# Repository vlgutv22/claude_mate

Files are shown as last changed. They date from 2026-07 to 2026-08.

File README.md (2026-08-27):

# Claude Mate










> **Not affiliated with Anthropic.** Claude and Claude Code are trademarks of
> Anthropic, PBC. This is an independent, non-commercial project — see
> [TRADEMARKS.md](TRADEMARKS.md).

<p align="center">
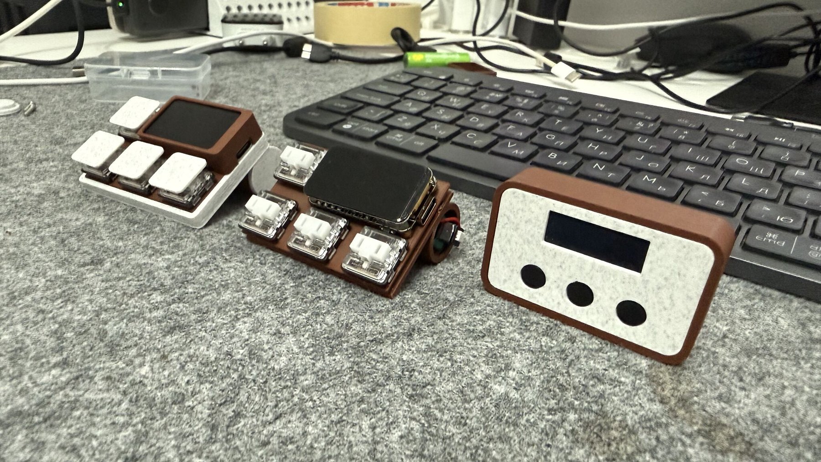
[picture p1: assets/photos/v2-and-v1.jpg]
Both Claude Mate builds on a desk — the cordless ESP32-S3 keypad with its colour screen, the same keypad opened up around its cell, and the original Arduino Nano box with its OLED
  
</p>

<p align="center"><sub><b>Two devices, one protocol.</b> Left and centre: iteration 2, the
cordless ESP32-S3 keypad (assembled, and opened around its cell). Right: iteration 1, the
USB Arduino Nano box.</sub></p>

**Claude Mate exists to cut the cognitive overload of orchestrating many
AI-agent sessions at once** — a wall of Claude Code tabs spread across different
accounts and projects, each finishing, blocking, or erroring on its own
schedule. Instead of scanning every terminal to find the one that stalled, you
glance at a small desk device: one screen and an indication LED tell you *which*
session needs you *right now*, and a single button jumps you straight to it.

**There are two devices, speaking one protocol, byte for byte.** The original
**Arduino Nano** over USB, and a cordless **ESP32-S3** with a 172×320 colour
screen that reaches the daemon over Wi-Fi, runs on a 14500 cell, and can open a
**live mirror of a session's actual terminal**. The daemon cannot tell them
apart: either works on its own, or **both at once** (see
[Bill of Materials](#bill-of-materials), [Roadmap](#roadmap) and
[`firmware/README.md`](firmware/README.md)).

You feed it from the Claude Code **hooks** or the **PTY wrapper**
(`claude-mate-wrap`); it becomes an ambient, always-on triage pane for every
session you have open — in VS Code, the terminal CLI, iTerm2, tmux, anywhere.

**Iteration 2 — ESP32-S3, 172×320 colour IPS, cordless:**

```
        ┌──────────────────────────────────────┐
        │ ▁▄█ CLAUDE MATE              ▮▮▮     │  ← status bar: Wi-Fi link · battery (3 segments)
        ├──────────────────────────────────────┤
        │ api-server                           │  ← r0: session name, in the state's colour
        │ WAIT   0:42                   work   │  ← r1: state · time-in-state · account
        │ Opus 5 xhigh                 5h82%   │  ← r2: model · effort · remaining limit
        │ 2/6  E  B  W  D  I                   │  ← r3: queue position · fleet strip, letter-coloured
        │ wifi 192.168.1.42                    │  ← link detail (firmware-local, never from the daemon)
        │══════════════════════════════════════│  ← accent bar in the selected session's state colour
        └──────────────────────────────────────┘
                  (•) WS2812 — rhythm AND colour
        [ PREV ]  [ GO ]  [ NEXT ]  [ MENU ]       ← a fourth button, with three gestures
   MENU: tap = the selected session's real terminal · double-tap = the on-device menu
         hold 2 s = long sleep (a tap wakes the board)
```

**Iteration 1 — Arduino Nano, 128×32 mono OLED, USB:**

```
        ┌───────────────────────┐
        │ api-server            │   ← r0: session name (flashes while its alert
        │ WAIT  0:42       work │   ← r1: state · time-in-state · account   is unacknowledged)
        │ Opus 5 xhigh    5h82% │   ← r2: model · effort · remaining limit
        │ 2/6 E B W D I         │   ← r3: queue position · whole-fleet letter strip
        └───────────────────────┘       (the active tab's letter sits in a wide centred filled rectangle)
              (•) indication LED               ← blinks per alert class, until you ack
          [ PREV ]   [ GO ]   [ NEXT ]         ← three buttons — same meaning, always
   PREV/NEXT: step the triage queue (hold = auto-repeat)   GO: short = ack + raise · double = FOLLOW · long = ack only

   the flash: name row inverting = unacknowledged (needs you) · steady = seen
   the strip: E error · B waiting · W working · D done · I idle — one letter per session, stable order
              a letter BLINKS while that tab's alert is unacknowledged; it goes steady once you ack it
   the box:   the active tab's letter is a wide centred filled rectangle (letter knocked out) — shows which tab is on screen
   the right edges: which ACCOUNT the session runs as (its wrapper profile) · how much of that account's plan
              limit is LEFT (5h82% = 82% of the 5-hour window · wk31% = 31% of the week — the tighter one shows)
   FOLLOW:    double-click GO → a ► marker appears; PREV/NEXT then also raise the selected terminal (raise only)
   the LED:   START 1 s blink · INPUT even blink · DONE 4-blink cascade · ERROR fast strobe  (loops until you GO/ack)
```

---

## Contents

- **[Install & use](#install--use)** — one command, then every CLI command
- **[The manual, 0 → hero](docs/USING.md)** — daemon, CLI and device in one page
- [What it is](#what-it-is)
- [The terminal mirror (ESP32-S3)](#the-terminal-mirror-esp32-s3)
- [Two ways to feed it](#two-ways-to-feed-it)
- [Features](#features)
- [Architecture](#architecture)
- [LED alerts & the acknowledge model](#led-alerts--the-acknowledge-model)
- [Bill of Materials](#bill-of-materials) · [Enclosures & 3D models](#enclosures--3d-models)
- [Quick start](#quick-start) · [Configuration](#configuration)
- [How the status maps to your sessions](#how-the-status-maps-to-your-sessions)
- [Roadmap](#roadmap)
- [Repository layout](#repository-layout)
- [Limitations](#limitations)
- [Changelog](#changelog)
- [License](#license)

---

## Install & use

**Install — one command.**

```sh
git clone https://github.com/vlgutv22/claude_mate.git && cd claude_mate
./install/install.sh --yes
```

It installs the Claude Code status hook, merges the hooks block into
`~/.claude/settings.json` (backing it up first), installs and **starts the
LaunchAgent** so the daemon runs at login, installs `pyserial` + `bleak`, and
puts the three commands below on your `PATH`. Idempotent — re-run it after a
`git pull`. Drop `--yes` and it asks before editing `settings.json`, its only
question.

**Then point `claude` at the wrapper** — this is what puts model, effort, account
and remaining limit on the screen:

```sh
echo 'alias claude="'"$PWD"'/bin/claude-mate-wrap"' >> ~/.zshrc && exec zsh
```

**No hardware needed.** `claude-mate` in a terminal is the same interface as the
device — and run bare, it is an app rather than a printout:

```sh
claude-mate
```
```
 claude-mate   ● daemon running · 14:22:31

 SESSIONS
  ▸• api-server   working    1:23   Opus 5  xhigh  work
    web-ui        waiting    0:05   Opus 5         needs you
    docs          idle      12:40

  ▸  Start new session
     Start new session · skip permissions
     Device · link status and pairing
     Accounts · switch or review
     Quit

 ↑↓ move   ⏎ raise this session   a ack   f follow   m mirror   c continue
 r restart daemon   q quit
```

Arrow keys move, Enter chooses, `q` quits. **Start new session** runs `claude`
through the wrapper in this terminal, which is the part you would otherwise
have typed — and going through the wrapper is what makes the new session show
up on the device at all.

Piped, hooked, cron'd or tested, `claude-mate` is still the plain one-shot queue
print it always was; the app appears only when both ends are a terminal.

### Every command

Full reference, including the other three binaries and every environment
variable: **[docs/CLI.md](docs/CLI.md)**.

| Command | Device button | What it does |
|---|---|---|
| `claude-mate` | — | the app on a terminal, else print the queue and exit |
| `claude-mate status` | — | the queue, printed once |
| `claude-mate watch` | — | reprint it every second until Ctrl-C |
| `claude-mate next` / `prev` | NEXT / PREV | step the selection (or scroll the mirror) |
| `claude-mate go` | GO | acknowledge **and raise that session's terminal** |
| `claude-mate ack` | GO, held | acknowledge only — leave your windows alone |
| `claude-mate follow` | ACK, held | toggle FOLLOW: `next`/`prev` then also raise |
| `claude-mate mirror` | 4th, tapped | toggle the live terminal mirror on the device |
| `claude-mate continue` | — | type `continue` into that session |
| `claude-mate new-terminal` | — | open a terminal in that session's directory |
| `claude-mate select <n\|name>` | *(none)* | point at a row instead of stepping to it |
| `claude-mate accounts` | — | the saved logins |
| `claude-mate accounts rm <n\|name>` | — | delete one, after typing its name back |
| `claude-mate daemon` | — | start the daemon, or restart it, through launchd |
| `claude-mate --version` | — | which build this is |

Three more commands beside it:

| | |
|---|---|
| `claude-mate-wrap` | the thing that actually runs `claude` and reports it. Reached through the shell alias above, never by name |
| `claude-mate-connect` | every link with a verdict, and the shortest fix for whichever is down. `--pair` enrols a cordless device over BLE |
| `claude-mate-switch` | carry this terminal's conversation to another account, with remaining limits |

**It presses the same buttons.** `claude-mate go` sends `press|G`, which the
daemon hands to the *same* handler that receives `B|G` from the device — so GO
means one thing here, and there is no second implementation to drift.

📖 **[docs/USING.md](docs/USING.md) is the full manual**, 0 → hero: the daemon,
every command above in detail, every button and screen on the device, how to
connect one, and a symptom → cause table for when something is wrong.

---

## What it is

**Claude Mate** is a small desk companion paired with a lightweight Python
daemon on your Mac. Build it either way — or both, at the same time:

| | **Iteration 1** — `claude_mate/` | **Iteration 2** — `claude_mate_s3/` |
|---|---|---|
| Board | Arduino Nano (ATmega328P) | Waveshare ESP32-S3-LCD-1.47**B** |
| Display | 0.91" 128×32 mono OLED (SSD1306) | 1.47" 172×320 colour IPS (ST7789) |
| Transport | USB serial | **BLE** or **Wi-Fi (TCP)**, USB as fallback |
| Buttons | 3 — PREV / GO / NEXT | 4 — + **MENU** (Kailh Choc low-profile) |
| Alert light | one LED, rhythm only | WS2812, rhythm **+ colour** |
| Power | USB | USB **or** a 14500 cell, with a gauge |
| Extra | — | a **live mirror** of a session's terminal |

The daemon keeps ONE **stable, alphabetically-ordered** **triage queue** of every
Claude Code session (tabs never shuffle as their states change) and renders ONE
screen: the *selected* session, over a whole-fleet letter strip. Urgency is
tracked **separately** — it drives the LED and the blinking fleet letters,
never the tab order or which tab is shown. The LED blinks a status-distinct pattern for the worst
*unacknowledged* alert — so a single tab finishing, blocking, or erroring is
*seen* even while the rest of your fleet keeps working. It keeps blinking until
you deal with it. There are **no UI modes**: the buttons — **PREV · GO · NEXT**,
and **MENU** on the S3 — mean the same thing at all times.

The single must-have action is **GO**: press it and the window for the
displayed session is raised so you can deal with it — the integrated VS Code
panel *or* the actual terminal that session is running in (matched by TTY).
Raise **only**: nothing in the system ever collapses or resizes a window.
Retrying or resubmitting a turn is intentionally **out of scope** (see
[Limitations](#limitations)).

The extra pixels on the S3 buy **typography, colour and the terminal mirror** —
never a different information model. The daemon pre-renders the same four rows
of at most 21 characters for both devices; each just draws what it was sent.

---

## The terminal mirror (ESP32-S3)

Tapping the **4th button** opens a live view of the selected session's *actual
terminal* on the device — 52×17 characters, refreshed about once a second.
**PREV/NEXT** then scroll it instead of moving the selection, and **GO** closes
it and raises the real window. Only **wrapped** sessions can be mirrored: a
hook-only session has no PTY for the daemon to read, and the device says so.

It adds no new channel. The PTY wrapper already mirrored the full TUI into
[pyte](https://github.com/selectel/pyte) (it was only being mined for state and
the model/effort strings), and the daemon already held a per-session control
socket to every wrapper for `focus`. The mirror is one more request/response on
that socket — so polling runs **only while the view is open**, and an unwatched
fleet costs nothing.

> ⚠️ **The mirror puts raw terminal output on the network.** The handshake is
> authenticated, but the session itself is **plaintext TCP** — and terminal
> contents can include keys, tokens and file contents, which is a materially
> larger exposure than shipping `WAIT` and a model name. Keep it to networks you
> trust. `--tcp` is opt-in and fails closed without a token.

---

## Two ways to feed it

You can drive the daemon from **either or both** of these — mix freely:

| Path | What it is | What it can see |
|---|---|---|
| **(a) Claude Code hooks** | `hooks/claude-status.sh`, wired to `UserPromptSubmit` / `Notification` / `Stop` / `StopFailure`. Fire-and-forget; never blocks or fails a turn. | Turn boundaries: started, needs-input, finished OK, finished on error — plus the **background work Claude reports on `Stop`** (`background_tasks` entries whose own `status` is still in flight, plus one-shot `session_crons`), so a turn that ends with work still running reports `working`, not a premature DONE — while a task listed as already finished is not counted, because the next `Stop` that would correct it may never come. Works in the VS Code extension and the CLI. |
| **(b) PTY wrapper** `bin/claude-mate-wrap` | Run `claude` *through* a wrapper (`alias claude=claude-mate-wrap`). It forks a pseudo-terminal, relays stdin/stdout transparently, and mirrors the TUI into a headless terminal emulator to read the **live screen**. | Everything on screen the hooks can't report: the spinner, **API errors/retries**, **permission prompts**, interactive option-pickers, and every **background-work** tell — the *"Waiting for N dynamic workflow to finish"* banner, the turn recap's *"· 1 shell still running"* suffix and the **live in-flight chip** in the hint row — i.e. it knows a session is **still busy after the turn "ends"**, including work that is only queued, and knows when it has stopped being busy. |

The wrapper is the more capable feed (true live state, plus terminal focus); the
hooks are the zero-dependency feed. Use whichever fits each session.

---

## Features

- **One stable, alphabetically-ordered triage queue** — every session in a
  fixed order (alphabetical by name, tiebroken by session key) so tabs **never
  shuffle under you** as their states change. **Urgency** is computed
  **separately** (worst unacknowledged alert: error → waiting → done, oldest
  first) and drives only the LED and the blinking fleet letters — never the
  tab order. **PREV** / **NEXT** step the order manually (hold to auto-repeat,
  wrapping at the ends); the screen **never changes subject on its own**.
- **No UI modes** — the buttons mean the same thing at all times:
  **PREV · GO · NEXT** (plus **MENU** on the S3). A short **GO** acknowledges
  the shown alert **and raises its window**; a **long-press of GO** (~0.5 s)
  acknowledges it **without** touching any window. Buttons fire instantly
  (edge-accepted ~40 ms debounce), and every accepted press flashes the device
  for ~80 ms — the Nano inverts the whole panel, the S3 turns its accent bar
  white — instant "the device heard you" feedback, well before the daemon
  round-trips a new frame.
- **No auto-switch, ever** — the selection is **sticky**: only PREV/NEXT/GO
  move it, and a GO/ACK stays on the tab it acted on. An alert on another tab
  announces itself through the LED and its **blinking fleet letter**; the view
  stays exactly where you left it until you navigate.
- **Navigation never touches windows** — the ONLY window operation in the
  whole system is GO, and it only **raises/activates**; the daemon never
  collapses, resizes, or miniaturizes anything.
- **GO is WYSIWYG** — GO/ACK act on exactly the session whose name is on the
  glass, never a freshly recomputed most-urgent alert. So a press can only ever
  raise the terminal you are actually looking at.
- **Status-distinct LED alerts** — the indication LED blinks the pattern of the
  *worst unacknowledged* alert across the whole fleet:
  - **START** — a job (re)started → one long 1 s blink (one-shot).
  - **INPUT** — a session is waiting on you → an aggressive even blink
    (~2.8 Hz), **looping** until you ack it.
  - **DONE** — a turn finished → a cascade of 4 quick blinks, then a pause,
    **looping** until you ack it.
  - **ERROR** — a turn ended on an API error → a super-aggressive ~7 Hz
    strobe, **looping** until you ack it.

  The loops run in the firmware until the daemon sends `V|OFF` (a GO/ACK, or
  the state changes on its own). If the daemon dies mid-alert the firmware
  stops the loop on its own after ~30 s of silence — and shows **LINK LOST**.
- **"Finished but not seen" model** — when a turn ends, the session becomes
  **done** and *stays* done (name flashing, LED looping) until you acknowledge
  it; later idle keepalives don't silently clear it. GO (or a long-press ACK)
  acknowledges it.
- **Flashing name row** — while the shown session's alert is unacknowledged,
  the top name row inverts at ~2.5 Hz; once acknowledged it goes steady. At
  a glance you know whether you've seen it.
- **Whole-fleet strip** — the bottom row shows your queue position
  (`pos/total`) plus one status letter per session in stable (alphabetical)
  order, **space-separated**: `E` error · `B` waiting · `W` working · `D` done ·
  `I` idle. A letter **blinks** while that tab's alert is unacknowledged.
- **Live time-in-state** — the state row counts up how long the session has
  been in its current state: for a `working` tab that IS the live turn
  runtime; for an alert it is how long it has been waiting on *you*.
- **One-button FOCUS** — GO raises the session's window: first the **PTY
  wrapper's own terminal** (iTerm2 / Terminal.app / VS Code / Ghostty / Warp /
  tmux, matched by TTY), else a **VS Code deep link**, else the VS Code window
  for the workspace folder. Raise only, always.
- **Honest link state** — with no daemon frame yet the firmware shows a boot
  splash; after ~30 s of daemon silence it replaces the stale frame with a
  **LINK LOST** screen (`NO LINK / waiting for daemon`) instead of freezing,
  and recovers on the next parsed line.
- **Hot-reloadable detection** — the wrapper's state patterns live in
  [`patterns.json`](patterns.json) and reload live (~0.25 s, no restart), so you
  can tune what counts as error/waiting/busy without touching code.
- **Robust by design** — the daemon keeps the serial port open continuously,
  auto-detects and auto-reconnects to the device, never crashes on a missing
  port; the hooks never block a turn; the wrapper falls back to running `claude`
  directly if anything is wrong.
- **`--mock` demo mode** — run the whole display with fake sessions cycling
  through every state, no Claude and no hardware required.

**On the ESP32-S3, additionally:**

- **Cordless, on a cell** — Wi-Fi (TCP) instead of USB, discovered over mDNS
  and authenticated with a nonce/HMAC handshake in which the token never
  crosses the wire. Wi-Fi credentials, daemon address and token live in **NVS**,
  a separate partition, so they **survive a reflash**. An unprovisioned board
  comes up on BLE and asks for a token over the cable; hold **BOOT** at power-on
  for a Wi-Fi setup portal you join from a phone.
- **Colour as a second channel** — the WS2812 plays the same rhythm *and* the
  alert class's colour, and every fleet letter is drawn in its own state colour.
  The colours differ in **brightness** as well as hue, so they stay distinct for
  a red/green-colourblind reader and in direct sunlight.
- **A battery indicator that doesn't lie** — **three segments** (3 green, 2
  amber, 1 red), not a percentage. Unplug a full cell and the voltage relaxes
  from 4200 to ~3950 mV in minutes, so a percentage read 100 % then 79 % with
  nothing wrong: 4200 mV is the *charger's* regulation point, surface charge is
  not consumption, and at ~9 mV per percent the ADC noise is worth whole points.
  Median-of-15 samples, an EMA, 60 mV of hysteresis and a 45-second hold sit
  behind it. The exact number stays in the About page, where diagnosis wants it.
  Charging is inferred in tiers; the board exposes no charge-status line.
- **A live terminal mirror** — see [above](#the-terminal-mirror-esp32-s3).
- **An on-device menu** — double-tap the 4th button. Four items: the triage view,
  SETTINGS, SHIP IT and long sleep. Settings holds the rest — a **BLE gamepad**
  switch, screen sleep, brightness, alert-LED level including a genuine *off*,
  Mac sound, flip, an About readout, and factory reset. **Nothing to do with
  Wi-Fi is on it at all** — not the radio switch, not the setup portal. Pairing
  a cordless board is `claude-mate-connect --pair` plus one press of GO, so the
  portal stopped being the only way in and stopped earning a row. **On the radio
  switch specifically:** one
  press used to be enough to move a cordless board onto Wi-Fi, and a board with
  no credentials then reboots into a portal that outranks the menu — hiding the
  row you would use to undo it. `claude-mate link <wifi|p2p|ble>` over USB still
  does it, which puts that switch behind a cable you have to actually have. About lives here
  rather than on the top strip because it is not a place you go: it is something
  you read. Entirely
  **firmware-local**: while it is up PREV/GO/NEXT are handled on
  the device and never emitted, so the queue cannot move while you are aiming at
  a settings row — and there is **no protocol change and no daemon change** for
  any of it.
- **A screen that turns itself off** — after 1–30 minutes, and only when nothing
  is waiting on you. What counts as waiting comes from the frame the device
  already has: a flashing name row, any lowercase fleet letter, or a *looping*
  LED — which the daemon drives from exactly "worst unacknowledged alert", so it
  is the authoritative signal. An alert turns the screen back on by itself. A
  `working` fleet does **not** hold it on — an hour of grinding with nothing to
  say is the case this exists for — and neither does `NO LINK`, because a dead
  daemon must not be able to burn the cell flat. A press on a dark screen only
  wakes, and is swallowed: GO raises a window, and obeying a press aimed at a
  screen you cannot read would sometimes yank you to the wrong session.
- **Long sleep** — hold the **4th button** for 2 s for deep sleep, tap to wake.
  Roughly a month of standby on a 14500; the WS2812 has no shutdown pin, so a
  switch in the battery lead is the only true zero.

---

## Architecture

```
   Claude Code session
   ├─ (a) hooks ─ ~/.claude/hooks/claude-status.sh
   │                 "<state>|<sid>|<name>\n"
   │
   └─ (b) PTY wrapper ─ bin/claude-mate-wrap  (alias claude=claude-mate-wrap)
                     "<state>|<sid>|<name>|<ctrl_sock>|<model>|<effort>\n"   + screen-scrapes the live TUI
                            │
                            ▼
              Unix domain socket  /tmp/claude-mate.sock
                            │
                            ▼
   ┌──────────────────────────────────────────────┐
   │   Python daemon (Mac)                        │
   │   • ONE triage queue + "done-until-acked"    │   (STABLE alphabetical order —
   │   • ONE pre-rendered screen                  │    tabs never shuffle; urgency separate)
   │       F|<flags>|<sel>|<r0>|<r1>|<r2>|<r3>          │
   │   • LED policy  V|<START/INPUT/DONE/ERR/OFF> │   worst unacked class, loops until ack
   │   • GO: raise the session's window — RAISE   │
   │     ONLY (wrapper ctrl-sock → VS Code link)  │
   │   • MIRROR: pull the session's live screen   │
   │     from its wrapper → M| lines (S3 only)    │
   └──────────────────────────────────────────────┘
             │                              │
   USB serial 115200 8N1        TCP :8787 (--tcp) or BLE GATT (--ble):
   "|"-delimited ASCII          mDNS-discovered / duty-cycled advertising,
             │                  the SAME nonce/HMAC handshake and the SAME
             │                  "|" lines — the token never crosses the wire
             ▼                              ▼
   ┌────────────────────────────┐  ┌──────────────────────────────────┐
   │  Arduino Nano (ATmega328P) │  │  ESP32-S3 (Waveshare -LCD-1.47B) │
   │  • SSD1306 128x32 OLED —   │  │  • ST7789 172x320 colour IPS —   │
   │    draws the one frame it  │  │    same four rows, + status bar  │
   │    was last sent (dumb)    │  │    and the M| terminal mirror    │
   │  • LED (D8) plays V|<KIND> │  │  • WS2812 plays V|<KIND> in the  │
   │  • PREV/GO/NEXT buttons    │  │    alert class's colour          │
   │    → B|P B|N B|G B|K       │  │  • + MENU button → B|M           │
   └────────────────────────────┘  │  • battery gauge, Wi-Fi config   │
             │                     │    in NVS, deep-sleep power-off  │
             │                     │  • its OWN menu + screen sleep,  │
             │                     │    which the daemon never sees   │
             │                     └──────────────────────────────────┘
             │  H (hello on boot), B|<x> (buttons)        │
             └───────────────► back to the daemon ◄───────┘
                    (both may be connected at the same time)
```

Two control flows worth calling out:

- **FOCUS round-trip.** Each wrapped session opens a per-session control socket
  (`/tmp/claude-mate-ctrl-<id>.sock`) and tells the daemon about it. On a GO
  press the daemon connects to that socket and sends the single verb `focus`;
  the wrapper raises *its own* terminal window using the right method for
  `$TERM_PROGRAM` (iTerm2 and Terminal.app match the exact tab by TTY), replying
  `go` on receipt and `ok` when the window op completed — so consecutive GO
  presses raise windows in press order. Hook-only sessions fall back to a
  VS Code deep link / window raise.
- **Reset recovery.** Opening the USB serial port resets the Nano (~1.5 s). On
  boot the Arduino emits `H`; the daemon responds by re-sending the full current
  state (the current frame + re-arming the LED loop), so the display recovers
  cleanly after any reconnect. A wireless device gets the same treatment when it
  (re)connects.
- **The wireless handshake.** The device dials the daemon, not the other way
  round — so it works from any address the Mac never has to know. It finds the
  listener via the `_claudemate._tcp` mDNS advertisement, then proves it knows
  the shared token against a server-issued nonce: the **token itself never
  crosses the wire**. `--tcp` is off unless asked for, and refuses to start
  without a token rather than serving an unauthenticated listener.

> The **triage queue** is a **stable, alphabetically-ordered** list of sessions —
> tabs never reorder as their states change. **Urgency** (worst unacknowledged
> **error > waiting > done**, oldest first) is tracked **separately** and drives
> only the LED and the blinking fleet letters, never the tab order or the shown
> tab (the selection is sticky). The top row is the selected session's **name**;
> its state (`ERR`/`WAIT`/`DONE`/`WORK`/`IDLE`) leads the second row.

---

## LED alerts & the acknowledge model

The LED is driven **entirely by the daemon** via `V|<KIND>` lines — the
firmware just plays the pattern (on D8 on the Nano, on the WS2812 on the S3);
the screen never blinks the LED on its own. The pattern is always the class of
the **worst unacknowledged alert** across all sessions (`ERROR` > `INPUT` >
`DONE`), so the LED loops exactly while something needs you:

| Event | `V|` kind | LED pattern | S3 colour | Repeat until acked |
|---|---|---|---|---|
| Job (re)started (nothing else pending) | `START` | one long 1 s blink, then dark | white | — (one-shot) |
| Waiting on you | `INPUT` | aggressive even blink (~2.8 Hz) | amber | **loops** continuously |
| Turn finished | `DONE` | cascade — 4 quick blinks, then a pause | green | **loops** continuously |
| Error / retry | `ERROR` | super-aggressive fast strobe (~7 Hz) | red | **loops** continuously |

The **rhythm is the primary channel** and is identical on both devices — colour
is redundant reinforcement on the S3, never the only thing carrying the message.

The loops run in the firmware until the daemon sends `V|OFF`. A turn ending
becomes **done** and keeps looping until you acknowledge the session — raising
it (**GO** short-press) or silencing it in place (**GO** long-press, no window
op) acknowledges it: a done tab becomes idle; a waiting/error tab goes quiet
but keeps its state until it changes. An alert can also die by
**auto-resolving** (the session leaves the alert class on its own — you
answered in the terminal) or by **TTL pruning**; nothing else removes one. A
session re-entering the same alert class within ~5 s of being acknowledged
stays acknowledged, so a bouncing detector can't re-fire the LED you just
silenced. The flashing name row mirrors the ack state: inverting while
unacknowledged, steady once seen. If the daemon ever dies mid-alert, the
firmware stops the loop on its own after ~30 s of serial silence and shows the
**LINK LOST** screen.

---

## Bill of Materials

### Iteration 2 — ESP32-S3, cordless

| Qty | Part | Notes |
|-----|---|---|
| 1 | **Waveshare ESP32-S3-LCD-1.47B** dev board | 1.47" 172×320 IPS (ST7789), dual-core ESP32-S3, 8 MB PSRAM, 16 MB flash, USB-C. Carries the WS2812, the Li-ion charger and the battery sense divider — so there is nothing else to solder on the board side |
| 4 | **Kailh Choc low-profile (1350) switches** | PREV · GO · NEXT · **MENU**. Tactile ("Chocolate"/brown) or linear, whichever you prefer — the firmware debounces in software either way |
| 4 | Choc keycaps (1350 footprint) | Any low-profile cap that fits Choc stems |
| 1 | **14500 Li-ion cell, ~800 mAh** | AA-sized 3.7 V. Plugs straight into the board's battery header — **do not** wire anything to GPIO 1 yourself, the sense divider is already there |
| 2 | M2 screws | Close the printed enclosure |
| — | Thin hook-up wire | Four switches to GPIO 3–6, one shared GND — no resistors, no debounce caps |
| 1 | USB-C cable | Flashing and charging |

> ⚠️ **The cell must be 3.7 V Li-ion.** The board's onboard charger is a 4.2 V
> Li-ion charger and the firmware's gauge curve and charge detection are
> calibrated for that chemistry (`CHARGE_FULL_MV 4150`, `BATT_LOW_MV 3300` in
> [`board_s3.h`](firmware/claude_mate_s3/board_s3.h)). A 3.2 V LiFePO4 cell would
> be over-charged by it *and* read as flat.

Pinout summary (full details in [`firmware/README.md`](firmware/README.md)):

| Signal | GPIO | Notes |
|---|---|---|
| PREV button | 3 | `INPUT_PULLUP`, emits `B|P`. A strapping pin, but an inert one — `STRAP_JTAG_SEL` is unburned by default |
| GO button | 4 | `INPUT_PULLUP`, emits `B|G` / `B|K` — same meanings as on the Nano |
| NEXT button | 5 | `INPUT_PULLUP`, emits `B|N` |
| **MENU** button | 6 | `INPUT_PULLUP`. Tap emits `B|M` (the mirror); **double-tap opens the on-device menu**; **hold 2 s = long sleep**, a tap wakes. Only the tap emits anything — the menu and the hold are firmware-local |
| Backlight | 46 | **On-board.** GPIO 46 on the ‑1.47**B**, 48 on the original ‑1.47 — the only pin that differs between revisions, and the wrong one leaves the panel dark while the ST7789 is driven perfectly |
| WS2812 alert LED | 38 | On-board. Plays `V|<kind>` in the alert class's colour |
| Battery sense | 1 | On-board 3:1 divider. Nothing to wire |

### Iteration 1 — Arduino Nano, USB

| Qty | Part | Notes |
|-----|---|---|
| 1 | Arduino Nano (ATmega328P) | Any USB-serial Nano clone works |
| 1 | SSD1306 0.91" 128×32 OLED, I2C | Address `0x3C` (some boards `0x3D`); 0.96" 128×64 also works |
| 3 | Momentary push buttons | PREV, GO, NEXT |
| 1 | LED + ~220 Ω–1 kΩ resistor | indication LED on D8 (the sole alert output) |
| — | Jumper wires, breadboard / perfboard | |
| 1 | USB cable (to the Mac) | Data-capable, not charge-only |

> The indication LED is the **sole alert output**: wire it on **D8 through a
> ~220 Ω–1 kΩ series resistor** to GND so the pin isn't over-driven, and keep
> all grounds common. See [docs/WIRING.md](docs/WIRING.md).

Pinout summary (full details in [docs/WIRING.md](docs/WIRING.md)):

| Signal | Pin | Notes |
|---|---|---|
| OLED SDA | A4 | I2C data |
| OLED SCL | A3 | **software (bit-banged) I2C** — hardware SCL A5 was damaged; see `firmware/claude_mate/softssd1306.h` |
| GO button | D2 | `INPUT_PULLUP`, emits `B|G` short (single = ack + raise; double-click = toggle FOLLOW) / `B|K` long (ack only) |
| NEXT button | D3 | `INPUT_PULLUP`, emits `B|N` (selection down; auto-repeats while held) |
| PREV button | D4 | `INPUT_PULLUP`, emits `B|P` (selection up; auto-repeats while held) |
| Indication LED | D8 | LED + series resistor to GND; plays the `V|<kind>` alert pattern |

Buttons on both builds use `INPUT_PULLUP` (other leg to GND; pressed = LOW),
laid out left→right as **PREV | GO | NEXT**.

---

## Enclosures & 3D models

Both devices are 3D-printed in the same two-material look — a terracotta body
with a felt-textured faceplate. Print either for **personal use** under the
project's non-commercial license.

| | Iteration 2 — ESP32-S3 | Iteration 1 — Arduino Nano |
|---|---|---|
| Model | [`claude_mate_s3.stl`](assets/3d-model/claude_mate_s3.stl) | [`claude_mate_v2.3mf`](assets/3d-model/claude_mate_v2.3mf) |
| Format | STL — body, 1 mm faceplate, LCD shelf and rim in assembled position; three small parts laid out separately | 3MF |
| Body size | ≈ 55 × 43 × 23 mm | — |
| Cut-outs | 1.47" LCD on a raised shelf, four Choc switches, USB-C | 0.91" OLED, three round buttons, USB |
| Holds | a 14500 cell in a tube on the back, closed by two M2 screws | the Nano and the perfboard |

Open either in Bambu Studio, PrusaSlicer, or Cura. The felt look is the 1 mm
faceplate printed in a second filament; print it in one colour and it still
assembles the same.

**Iteration 2:**

| On the keyboard | Assembled | Back, with the cell tube |
|:---:|:---:|:---:|
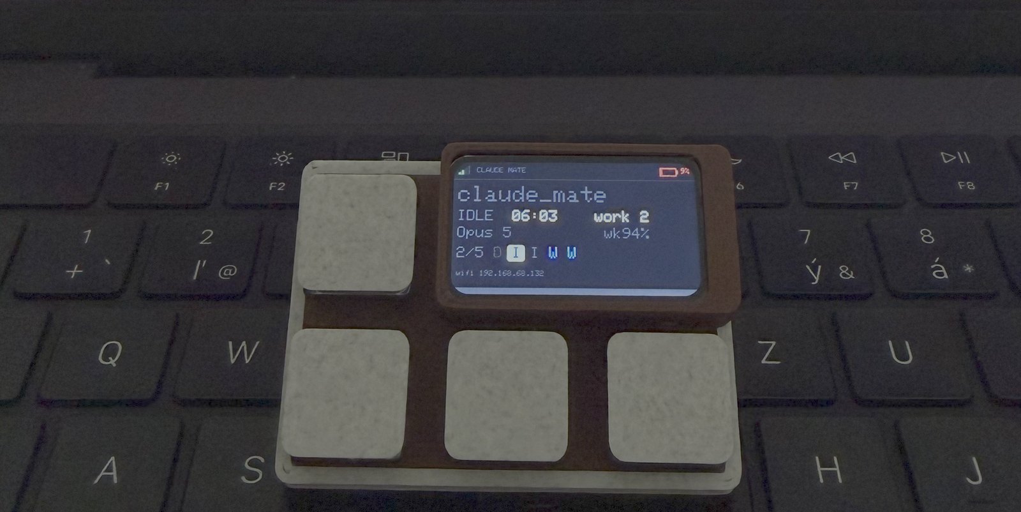
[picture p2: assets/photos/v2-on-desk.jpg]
The ESP32-S3 Claude Mate sitting on a laptop keyboard, its colour screen showing a live session
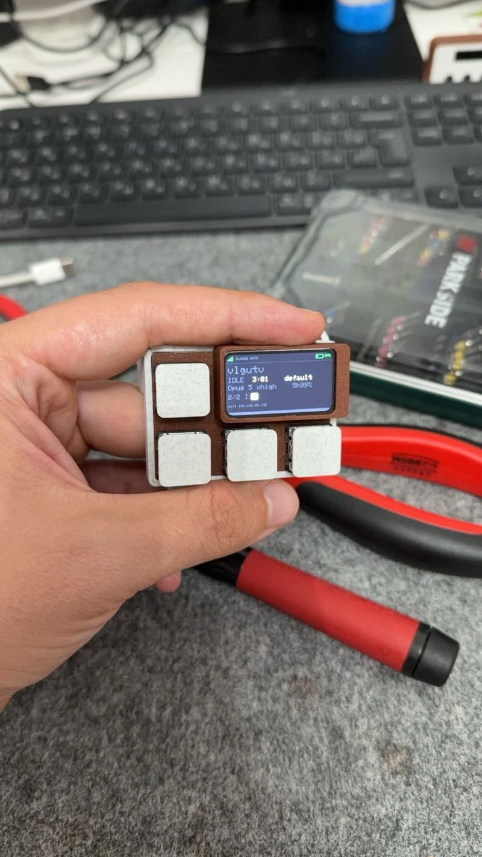
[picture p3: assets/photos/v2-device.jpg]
The assembled ESP32-S3 device held in a hand, four Kailh Choc keycaps and the colour screen lit
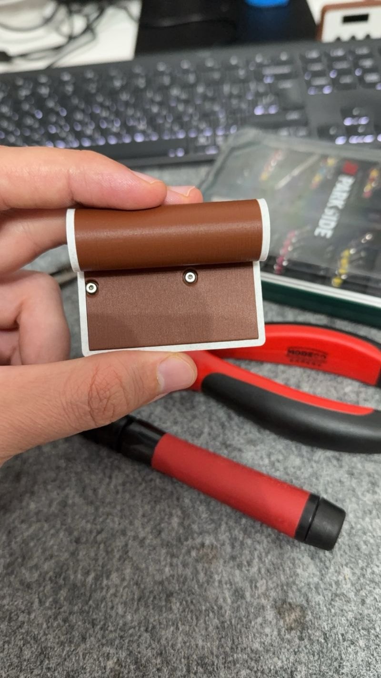
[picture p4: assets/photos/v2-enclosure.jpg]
The back of the printed enclosure — a cylindrical tube for the 14500 cell and a screwed-on base plate
| [](assets/photos/v2-on-desk.jpg) | [](assets/photos/v2-device.jpg) | [](assets/photos/v2-enclosure.jpg) |

**Iteration 1:**

| On the desk | Printed enclosure | Inside |
|:---:|:---:|:---:|
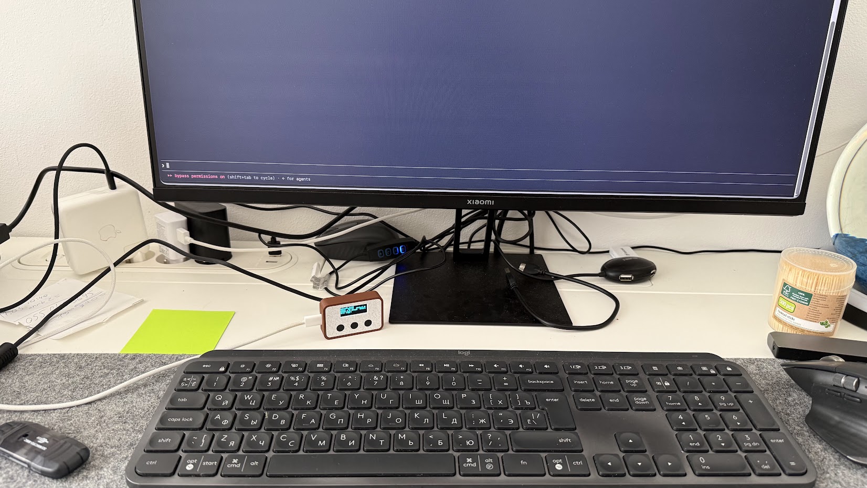
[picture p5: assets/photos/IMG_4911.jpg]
Claude Mate on a desk in front of the monitor
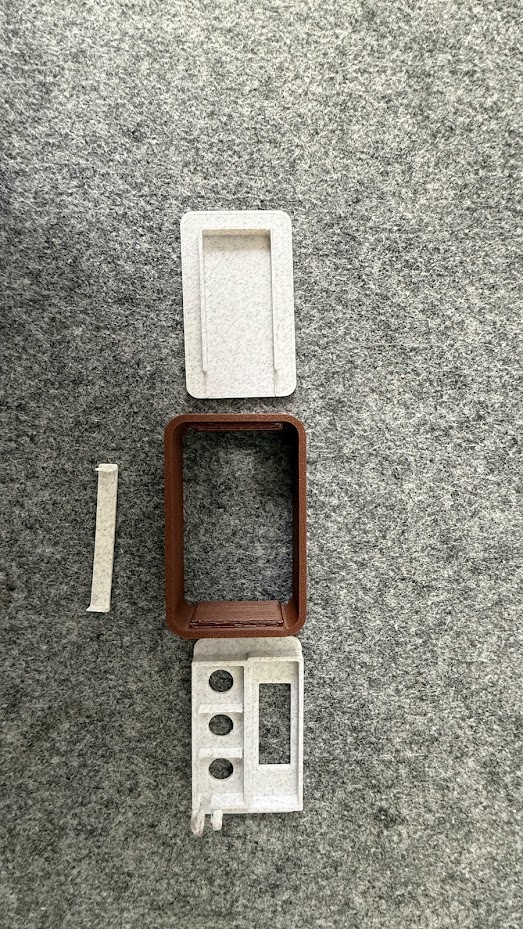
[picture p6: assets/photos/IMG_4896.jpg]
3D-printed enclosure parts laid out
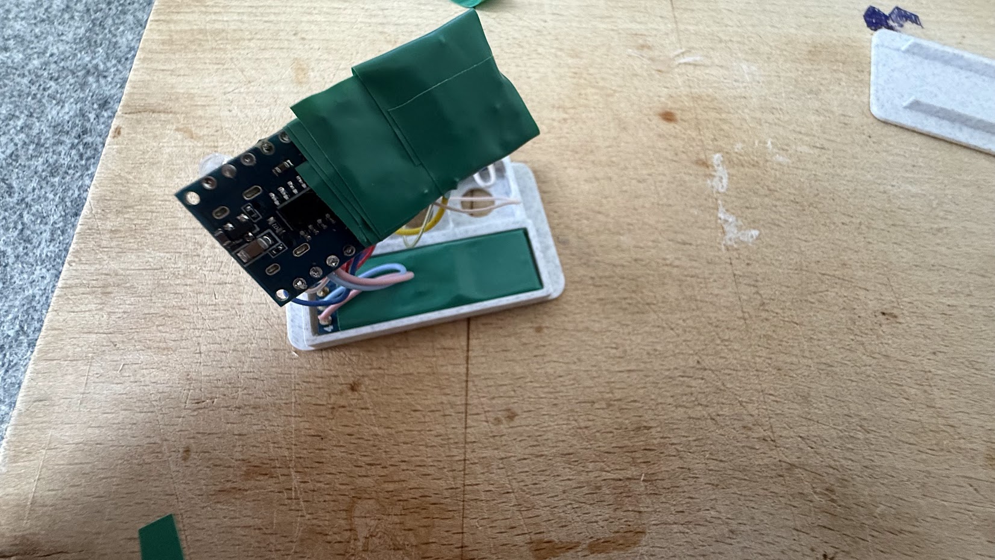
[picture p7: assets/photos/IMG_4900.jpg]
Wired PCB going into the enclosure
| [](assets/photos/IMG_4911.jpg) | [](assets/photos/IMG_4896.jpg) | [](assets/photos/IMG_4900.jpg) |

More build photos are in [`assets/photos/`](assets/photos/).

---

## Quick start

**One command.** Clone it and run the installer:

```sh
git clone https://github.com/vlgutv22/claude_mate.git && cd claude_mate
./install/install.sh --yes
```

That installs the status hook, merges the hooks block into
`~/.claude/settings.json` (backing it up first), installs and **starts the
LaunchAgent** so the daemon runs at login, and puts `claude-mate`,
`claude-mate-connect` and `claude-mate-switch` on your `PATH`. Drop `--yes` and it
asks before touching `settings.json` — that is the only question it has. Re-run it
any time; it is idempotent.

Then point `claude` at the PTY wrapper, which is what puts model, effort, account
and remaining limit on the screen:

```sh
echo 'alias claude="'"$PWD"'/bin/claude-mate-wrap"' >> ~/.zshrc && exec zsh
```

Check it with `claude-mate` (your sessions) and `claude-mate-connect` (every
link, with a verdict). **No hardware needed to try it** — `claude-mate` is the
same interface as the device:

```sh
claude-mate watch
```

📖 **[docs/USING.md](docs/USING.md) is the manual** — the daemon, every CLI
command, every button and screen on the device, and what to do when something is
wrong. The rest of this section is the manual way, and what to flash.

---

<details>
<summary><b>The manual way, and flashing a device</b></summary>

1. **Build & flash the firmware** — pick your device (or do both; they coexist):

   - **Arduino Nano** (`firmware/claude_mate/claude_mate.ino`). Install
     **Adafruit GFX** via the Arduino Library Manager — it is the only external
     library needed (the SSD1306 itself is driven by the bundled
     `softssd1306.h`, a software-I2C `Adafruit_GFX` subclass).
     ```sh
     arduino-cli upload -b arduino:avr:nano:cpu=atmega328 -p /dev/cu.usbserial-XXXX \
                        firmware/claude_mate
     ```
   - **ESP32-S3** (`firmware/claude_mate_s3/`). Install *GFX Library for
     Arduino* (Arduino_GFX), then use the bundled script — **`arduino-cli
     upload` cannot flash this board**, and `firmware/README.md` explains the
     three reasons why:
     ```sh
     ./firmware/flash_s3.sh
     ```
     On first boot an unprovisioned board comes up on **BLE** with no token —
     and with the daemon running you do nothing: it hands its token to any
     device that appears on the cable. Cordless, pair it in one command:
     `claude-mate-connect --pair`, then press **GO** on the device.
2. **Run the daemon** on your Mac:
   ```sh
   python3 daemon/claude_mate_daemon.py
   ```
   Try it with no hardware/Claude first:
   ```sh
   python3 daemon/claude_mate_daemon.py --mock
   ```
   For a **wireless** device, opt into a wireless transport. Either generates a
   shared token on first run and prints it — type that into the device's setup
   portal:
   ```sh
   python3 daemon/claude_mate_daemon.py --tcp        # port 8787, advertised over mDNS
   python3 daemon/claude_mate_daemon.py --ble        # Bluetooth LE (pip install bleak)
   ```
   Wi-Fi reaches the whole home or office and is right when the host is **not on
   this desk**; BLE is right when it **is**, and lets the device advertise in
   200 ms bursts four seconds apart instead of holding an association open all
   day for a device that has almost nothing to say. Pick one on the device at
   `I|BLE` over USB — it has a single 2.4 GHz radio, so it is never both. See
   [docs/POWER.md](docs/POWER.md).
   Add `--sound` to also play a macOS alert sound when the worst unacknowledged
   alert class changes. The device has no speaker of its own — the ESP32-S3 has
   no DAC and the board's rail is a linear LDO, so there is no switching node a
   firmware trick could make audible.
3. **Feed it.** Pick either (or both):
   - **Hooks:** install the Claude Code hooks so session events reach the daemon.
   - **PTY wrapper:** `pip install pyte`, then run Claude through the wrapper:
     ```sh
     alias claude="$PWD/bin/claude-mate-wrap"
     claude            # use Claude exactly as normal — now with live state + FOCUS
     ```
     The wrapper is safe to install as a global `claude` shim: non-interactive
     (`claude -p …`, pipes, CI) execs the real binary, and it locates the real
     `claude` even when every `claude` on `PATH` is your own shim.

</details>

Step-by-step guides:

- 📖 **The manual — daemon, CLI and device** — [docs/USING.md](docs/USING.md)
- 📦 **Install** — [docs/INSTALL.md](docs/INSTALL.md)
- 🔌 **Wiring (Nano)** — [docs/WIRING.md](docs/WIRING.md)
- 📶 **Both firmwares, flashing & provisioning** — [firmware/README.md](firmware/README.md)
- 📡 **Line protocol** — [docs/PROTOCOL.md](docs/PROTOCOL.md)
- 🔋 **Power, and what the battery build costs** — [docs/POWER.md](docs/POWER.md)
- ✅ **Testing** — [docs/TESTING.md](docs/TESTING.md)

### Configuration

**Daemon** environment variables (all optional):

| Variable | Default | Meaning |
|---|---|---|
| `CLAUDE_MATE_PORT`  | autodetect | Serial device. Autodetects `/dev/cu.usbserial*` then `/dev/cu.usbmodem*` |
| `CLAUDE_MATE_SOCK`  | `/tmp/claude-mate.sock` | Unix socket the hooks/wrapper write to |
| `CLAUDE_MATE_BAUD`  | `115200` | Serial baud rate |
| `CLAUDE_MATE_TCP` | off | `1` also serves the protocol over TCP for wireless devices (same as `--tcp`) |
| `CLAUDE_MATE_TCP_PORT` | `8787` | TCP listener port |
| `CLAUDE_MATE_TCP_BIND` | `0.0.0.0` | Bind address — a remote device needs a routable one; `127.0.0.1` keeps it on this machine |
| `CLAUDE_MATE_BLE` | off | `1` also serves the protocol over **Bluetooth LE** for the battery build (same as `--ble`). Needs the optional `bleak` package; without it the daemon says so and carries on |
| `CLAUDE_MATE_BLE_ADDRESS` | scan | Connect to this BLE address instead of scanning for the service. macOS reports its own per-host UUIDs, not MAC addresses — use the string `bleak` printed |
| `CLAUDE_MATE_TOKEN` / `_TOKEN_FILE` | `~/.config/claude-mate/token` | Shared secret wireless devices authenticate with — **the same one on both radios**. `--tcp`/`--ble` **generate one** (0600) and print it if none exists — send that to the device as `T\|<token>` over USB, or type it into the setup portal. Either transport still refuses to start if a token can neither be read nor created |
| `CLAUDE_MATE_SOUND`  | off | `1` plays a macOS alert sound when the worst unacknowledged alert class changes (same as `--sound`) |
| `CLAUDE_MATE_NO_USB_PROVISION` | off | `1` stops the daemon handing its token to a device that appears on the USB cable. On by default because *"how do I connect it after a factory reset"* should not be a question: provisioning over USB is already the trusted path, so the cable does it with nobody typing anything |

The listener is advertised as `_claudemate._tcp` over mDNS, so a device with no
host configured finds the daemon on its own.

**PTY wrapper** environment variables:

| Variable | Default | Meaning |
|---|---|---|
| `CLAUDE_MATE_SOCK` | `/tmp/claude-mate.sock` | Daemon socket to report state to |
| `CLAUDE_MATE_PATTERNS` | `<repo>/patterns.json`  | Detection patterns file (hot-reloaded) |
| `CLAUDE_MATE_DEBUG` | unset | If set to a path, append screen + state snapshots there (debugging) |
| `CLAUDE_REAL` | autodetect | Explicit path to the real `claude` binary |
| `CLAUDE_MATE_ACCOUNTS_DIR` | `~/.claude-accounts` | Root of account profile dirs (see below) |
| `CLAUDE_MATE_ACCOUNT`  | unset | Profile name to use, skipping the picker |
| `CLAUDE_MATE_USAGE_POLL_S` | `120` | Remaining-limit poll period in seconds (`<= 0` disables) |

**Account profiles** — Claude Code holds one login per config dir, so the
wrapper can run different terminals under different accounts by pointing each
session at its own `CLAUDE_CONFIG_DIR`. Every subdirectory of
`~/.claude-accounts` is a profile; create one with `mkdir -p
~/.claude-accounts/work` (or by typing a new name at the picker). Once at
least one profile exists, every interactive start shows a picker listing each
profile with the email logged into it — press Enter for your default
`~/.claude` login, or pick a number. `claude --account work …` (the flag is
consumed by the wrapper, never passed to claude) or `CLAUDE_MATE_ACCOUNT=work`
selects a profile non-interactively, and an already-exported
`CLAUDE_CONFIG_DIR` always wins. A fresh profile starts logged out — claude
prompts `/login` there on first run — and keeps its own settings, history, and
MCP config. With no profile dirs, nothing changes.

**The same thing from a terminal** — `claude-mate`. The device is the good
interface, but it is one device, sometimes across the room, and sometimes flat.
Everything it does is a line on the daemon's socket, so none of it needed to be
exclusive to the hardware:

```sh
claude-mate                  # the app: arrow keys, and a menu
claude-mate status           # the queue, printed once (what a pipe gets)
claude-mate watch            # ...and keep printing it
claude-mate next / prev      # step the selection
claude-mate go               # ack + raise that session's terminal
claude-mate ack / follow     # ack only · toggle FOLLOW
claude-mate mirror           # toggle the terminal mirror
claude-mate continue         # type "continue" into that session
claude-mate new-terminal     # open a terminal in that session's directory
claude-mate select api       # point at a row instead of stepping to it
claude-mate accounts         # the saved logins
claude-mate accounts rm old  # delete one, after typing its name back
claude-mate daemon           # start it, or restart it
```

Run it bare on a terminal and it is an app rather than a printout: arrow keys
through the queue, Enter to raise a session, and a menu that starts a new
wrapped session without going back to a shell. Piped, hooked or scripted it
stays exactly the one-shot print above. **[docs/CLI.md](docs/CLI.md)** is the
full reference for all four commands.

**It presses the same buttons.** `claude-mate go` sends `press|G`, which the
daemon hands to the *same* `ButtonReader` that handles `B|G` off the wire — so GO
means one thing on this project (mirror closes first, a double press toggles
FOLLOW, the raised window is the one whose name was on the glass) and there is no
second implementation to drift. `claude-mate select` is the only thing the device
has no equivalent for; it walks there with PREV/NEXT instead.

**Deleting an account happens in the CLI's own process, never over the socket.**
That socket is `chmod 0600` — the user's own, which is all a hook needs. Even
so, a hook firing a malformed line should not be able to remove a login.

**Device will not connect?** — press `d` at the account picker, or run
`claude-mate-connect`. It reports every link — daemon, token, cable, BLE — and
prints the shortest fix for whichever one is down.

With a cable it has nothing to do: **the daemon hands its token to any device
that appears on USB**, so a board that has just been factory reset links itself
a few seconds after being plugged in, with nobody typing anything. Cordless,
**pair it over BLE** — one command and one button:

```sh
claude-mate-connect --pair     # the device shows PAIR? — press GO on it
```

The device is the one that asks its human, which is what makes it safe to expose
to the radio: being in range gets you a prompt on a screen you cannot reach, and
nothing else. The token is sent only after the button, and once — see
[`docs/PROTOCOL.md`](docs/PROTOCOL.md#enrolment).

> **It will never appear in System Settings → Bluetooth**, and that is correct,
> not a fault. The status link is an unpaired GATT peripheral advertising in
> short bursts; there is no pairing step by design, because Just Works pairing
> authenticates nobody and the token handshake is what decides who may drive the
> device. Only a CoreBluetooth scan sees it, which is what the daemon does — its
> log is the one place the Mac can answer *"is it advertising?"*. (The **gamepad**
> mode is a genuine HID device and does appear there; that is a different role of
> the same board.)

**Hit the limit? Carry the conversation across** — `claude-mate-switch`
continues *this terminal's* conversation on another account. An account is a
config dir read once at startup, so nothing can change account in place; and
each profile keeps its own `projects/` tree, so a new account cannot see the
old one's transcripts. The switch closes that gap: a transcript is just a file,
so copying it into the target profile's tree makes `claude --resume` find it.

```sh
claude-mate-switch                 # accounts, remaining limits, and what would move
claude-mate-switch work2           # copy the conversation there and resume
claude-mate-switch --best          # whichever account has the most headroom left
claude-mate-switch --dry-run work2 # show the move, touch nothing
```

It works because the wrapper publishes a small **context file per terminal**
under `$TMPDIR` — which transcript is in flight, under which account, in which
directory, with which flags, and how depleted that account is. Temp and
per-terminal on purpose: it describes a running process, is worthless once that
process exits (and is unlinked then), and two terminals in the same directory
are two different conversations that must not carry each other off. A context
not refreshed for 15 minutes is treated as dead rather than resumed.

Which transcript is *this* terminal's is **asked, not guessed**: the wrapper
mints the conversation id and hands it to claude (`--session-id`), so the file
is the one with that name wherever Claude Code's undocumented directory
mangling puts it. The earlier version looked at the newest `.jsonl` under the
config dir and picked wrong in the field — a terminal in one project offering
to carry off another terminal's conversation from another project. Sessions
that name their own conversation (`--resume`, `--continue`) fall back to a
search that now verifies the directory recorded *inside* each transcript.

> **One caution.** The copy puts one account's conversation into another
> account's local store, and resuming replays it to that account's API. The
> tool never switches without being told where, prints both logins side by
> side, and says so plainly when their email domains differ — but it does not
> *stop*. It used to: a differing domain was read as "another organisation" and
> refused. Every account it can reach is one you installed and logged into
> yourself, so on a real three-account fleet spread across three domains that
> rule refused every possible switch, and said so only in a log file — breaking
> the exact case the feature exists for (*this account is out of limit,
> continue on another*). Announce, don't block.

**When a press declines, the device says why.** Any of these can fail for an
ordinary reason — already on that account, nothing said yet worth carrying, not
a wrapped session — and the wrapper answers each in words. Those words go on
the glass for about four seconds, across the middle two rows, keeping the
session name above them. A press that silently does nothing is indistinguishable
from a broken button, and the cure for "I pressed it and nothing happened" is
not to press harder.

**Account + remaining limit on the device** — each wrapped session reports
which account it runs as (the profile name, or `default`), shown right-aligned
on the state row, and how much of that account's plan limit is left, shown as
a chip on the model+effort row: `5h82%` = 82% of the 5-hour window remaining,
`wk31%` = 31% of the week — whichever window is more depleted. The wrapper
reads the session's own OAuth token (from `<config-dir>/.credentials.json`, or
the macOS Keychain where Claude Code keeps it) and polls Anthropic's usage
endpoint every `CLAUDE_MATE_USAGE_POLL_S` seconds (default 120; `<= 0`
disables). Read-only: the wrapper never refreshes or rewrites credentials —
that stays claude's job.

**Detection tuning** lives in [`patterns.json`](patterns.json) — case-insensitive
substrings matched against the rendered TUI, grouped as `error` / `waiting` /
`waiting_footer` / `busy` (precedence: error > waiting > waiting_footer > busy >
idle). Matching is scoped to Claude's **live status region** (the bottom ~20
non-empty lines) for error/waiting/busy, and to the **footer** (~4 lines) for the
generic picker phrases — so the same keywords in scrollback, logs, code, or
conversation above don't false-trigger. The footer phrases are limited to
`to select` / `to navigate` (a real question picker), and a footer-only `waiting`
must **persist a couple of seconds** before it reports — so a config dialog you
open and dismiss (the `/effort` or `/model` slider, whose footer is
`… · Esc to cancel`) no longer alerts the instant you open it.

**Background work is not tunable there — and deliberately so.** A turn can end
while a dynamic workflow, background agents, a backgrounded shell, a monitor or
an MCP task keep going, and the session must stay `working` until they finish
(otherwise the device buzzes DONE mid-flight and then shows IDLE for work that
is still running). Claude renders four tells for it, and the wrapper matches
them with **structural regexes** in code, because a substring loose enough to
catch them would fire on ordinary prose:

| Tell | Looks like | Covers |
|---|---|---|
| Banner | `✻ Waiting for 2 background agents and 1 dynamic workflow to finish` | Turn end; also matched when it **wraps** in a narrow terminal |
| Turn recap suffix | `✻ Crunched for 1m 56s · 1 shell still running` | Turn end, for work the banner doesn't name |
| Task-panel counter | a dim, right-aligned *`N` in background* | The same fact on Claude's task panel |
| **In-flight chip** (hint row) | `⏵⏵ bypass permissions on · 1 shell · ← for agents · ↓ to manage` | **Everything, including queued work and scheduled loops.** Read only *below the prompt box*, where neither the conversation nor the line you are typing can reach |

**The first three are transcript text, so they expire.** Claude prints them
once and never rewrites them — a recap still reads *"1 shell still running"*
long after that shell exited, and nothing scrolls it away while you are away
from the keyboard, which is exactly when the device is all you can see. So each
counts only while it is still Claude's **last word**: the moment Claude prints
anything that supersedes it (`⏺ Background command … completed (exit code 0)`,
`⏺ Agent … finished · 9s`, or simply the next reply), the tell goes quiet. The
chip needs no such gate — it lives in Claude's live chrome and disappears on its
own. Verified against two 200-second recordings of real sessions, one per tell;
the frames are the fixtures in `tools/test_detect.py`.

Three guards come with it. A to-do left `in progress` in the task panel is
**not** counted — it is a plan item, not a running task, and keying off it would
mean the device could never report DONE again. A **finished** subagent's row in
the agents panel keeps its final `9s · ↓ 7.5k tokens` on display, which is
textually a live activity meter — so the meter is read only above the prompt
box, never from that panel. And background work never masks
**needs-your-input**: only the foreground spinner vetoes a question picker, so a
session that keeps a shell or a workflow running still alerts when it asks you
something.

---

## How the status maps to your sessions

The daemon keeps one record per session (keyed by `session_id`, or by name if no
id is provided). Each session is in one of these states:

| State | Triggered by | Meaning |
|---|---|---|
| `working` | `UserPromptSubmit` / wrapper "busy" | A turn is in progress (or a background workflow is still running) |
| `waiting` | `Notification` / wrapper prompt+picker | Needs permission, a question, or a menu choice |
| `error` | `StopFailure` / wrapper API-error | Turn ended on an API error (5xx / overloaded / timeout / usage limit) |
| `done` | `Stop` (then held until acknowledged)  | Turn completed OK — keeps alerting until you GO/ack |
| `idle` | Inactivity (TTL) / acknowledged done | No active turn |

The daemon keeps the **triage queue** in a **stable, alphabetical order** (tabs
never shuffle as their states change) and computes **urgency separately**:

```
tab order:  STABLE — alphabetical by name (tiebreak: session key)
urgency:    worst UNACKNOWLEDGED alert (error > waiting > done, oldest first)
            → drives the LED loop + the blinking fleet letters only,
              never the order and never the shown tab
```

Urgency is the **priority model** for two things only: what the LED blinks
about, and which fleet letters blink on the strip. The shown tab is **sticky**:
the screen never switches on its own — you navigate with PREV/NEXT. The LED
pattern is always the class of the worst *unacknowledged* alert (`ERROR` >
`INPUT` > `DONE`), dropping to `V|OFF` when nothing needs you. GO/ACK act on the
session **currently shown** (WYSIWYG) and never move the tab order. With zero
sessions the device shows `MATE / no sessions`.

---

## Roadmap

Claude Mate is built in iterations, each removing more friction than the last.

- **Iteration 1 — Arduino + macOS (this repo).** An Arduino Nano drives the
  OLED, the three buttons, and the indication LED over **USB serial**; a Python
  daemon on the Mac keeps the triage queue, renders the screen, and raises
  windows. Tethered by USB to the machine it watches.
- **Iteration 2 — ESP32-S3 Wi-Fi remote (here, shipped).** A Waveshare
  ESP32-S3-LCD-1.47B talks to the daemon **over Wi-Fi** instead of USB — a
  genuinely wireless desk remote you can put anywhere, running on a 14500
  Li-ion cell with an on-screen battery gauge and a deep-sleep power-off. Same
  triage model, same line protocol; the transport became the network. The
  172×320 colour LCD adds a fourth **Kailh Choc** key that opens a **live
  mirror of a session's actual terminal**, and the follow-ons that iteration 1
  could only hint at — colour-coded alerts, on-battery operation — are in.
  Iteration 1 is **unchanged and still supported**: both devices speak the
  identical protocol and can be connected at the same time. See
  [`firmware/README.md`](firmware/README.md).

The goal stays fixed across every iteration: **one calm surface that tells you
which agent needs you, so running many of them in parallel stops taxing your
attention.**

---

## Repository layout

```
claude_mate/
├── README.md
├── LICENSE · CONTRIBUTING.md · CODE_OF_CONDUCT.md · SECURITY.md
├── patterns.json                  # hot-reloadable state-detection tuning
├── assets/                       # device photos + printable 3D enclosures (.3mf, .stl)
├── bin/
│   └── claude-mate-wrap           # PTY wrapper: live state + terminal FOCUS (pyte)
├── daemon/
│   ├── claude_mate_daemon.py      # Python daemon (pyserial; --tcp adds the wireless link)
│   └── blelink.py                 # BLE central for --ble (optional: bleak)
├── firmware/
│   ├── README.md                  # both builds: options, wiring, flashing, provisioning
│   ├── claude_mate/               # Arduino sketch (one-frame OLED renderer + LED)
│   ├── claude_mate_s3/            # ESP32-S3 sketch (colour UI, Wi-Fi/BLE, mirror, battery)
│   ├── flash_s3.sh                # the only way to flash the S3 board
│   └── selftest/                  # hardware self-test sketch
├── hooks/
│   ├── claude-status.sh           # installed to ~/.claude/hooks/
│   └── settings.snippet.json      # the four hook wirings
├── install/                       # install.sh / uninstall.sh / LaunchAgent plist
├── packaging/                     # notarizable macOS .pkg installer
├── tools/                         # feed.sh + e2e / wrapper / settings-merge tests
└── docs/
    ├── INSTALL.md · WIRING.md · PROTOCOL.md · TESTING.md · ARCHITECTURE.md
```

---

## Limitations

- **Retry/resubmit is out of scope.** When a turn ends on an error, Claude Mate
  shows it (a flashing `ERR` frame + the looping ~7 Hz LED strobe until you ack
  it) but does **not** offer a "retry" action. Reliably resubmitting a turn from outside the
  GUI is not feasible, so GO — taking you to the session — is the intended
  response.
- **Model/effort strings are best-effort.** The model/effort row (e.g.
  `Opus 4.8 xhigh`) is scraped from the live TUI by the PTY wrapper and
  stays empty for hook-only sessions or until scraped. Claude Mate never
  fabricates it; treat this as an extension point.
- **The remaining-limit chip is best-effort too.** It comes from Anthropic's
  OAuth usage endpoint (an undocumented interface that may change), polled with
  the session's own token. Offline / expired-token / console-account sessions
  simply show no chip (or keep the last known value until a poll succeeds).
- **FOCUS targets the wrapper's terminal first, then VS Code.** A wrapped session
  raises its own terminal window (matched by TTY) using the terminal app's own
  scripting — it selects the session's tab and brings that window to the front.
  No special permission is required (macOS **Automation**, granted once on first
  use — not Accessibility). Raise is the *only* window operation; nothing is ever
  collapsed or resized. Hook-only sessions fall back to a VS Code deep link, then
  to raising the VS Code window for the workspace folder — the exact deep-link URI
  lives behind a single config constant so it is trivial to update.
- **Detection is screen-scrape-based (wrapper).** State is inferred from the
  rendered TUI using `patterns.json`. It is scoped to the live status region to
  avoid false positives, but unusual terminal themes/locales may need a pattern
  tweak — which you can do live, no restart.
- **The wireless link is authenticated, not encrypted.** The handshake is
  nonce/HMAC and the token never crosses the wire, but the session itself is
  **plaintext** — so session names, states and, with the mirror open, raw
  terminal contents are readable by anyone on the same network. `--tcp` is
  opt-in and refuses to start without a token; treat it as a trusted-LAN
  feature. **`--ble` is exactly the same trade**, over a different pipe and with
  a shorter radius: the link is deliberately unpaired and unencrypted, because
  "Just Works" pairing is what a device with no keypad gets and is
  unauthenticated by definition — the token handshake, not Bluetooth, is what
  decides who may drive the device.
- **`arduino-cli upload` cannot flash the ESP32-S3 board.** Its download mode
  ignores the DTR/RTS straps, the USB link stalls partway through any large
  transfer, and `--after hard-reset` lands back in the bootloader looking
  exactly like a bricked board. Use `firmware/flash_s3.sh`, which works around
  all three and verifies every 32 KB piece with a device-side hash.
- **The S3's charge detection is inferred, not read.** The board exposes no
  charge-status line, so charging is deduced from the cell's own voltage —
  which is calibrated for a 14500-class Li-ion cell. A much larger cell creeps
  too slowly for the trend fallback; the "at the regulation point" tier still
  catches it.
- **macOS-focused.** The daemon and wrapper target a Mac (serial device naming,
  `open`, AppleScript focus). Other platforms would need port/focus adjustments.

---

## Changelog

Dated release notes live in **[CHANGELOG.md](CHANGELOG.md)** — the from-zero
interface rewrite, account profiles, the on-device account + remaining-limit
chip, and the move to a fully sticky selection.

---

## License

**Creative Commons Attribution-NonCommercial 4.0 International (CC BY-NC 4.0)** —
see [LICENSE](LICENSE). This covers the whole repo: the software, both
firmwares, the hardware design, the 3D-printable enclosures, the photos, and the
documentation.

- ✅ **Personal, non-commercial use** — build one for yourself, modify it, share
  it, and contribute changes back, with attribution.
- ❌ **No commercial use** — you may not sell the device, the models, or a
  service built on this work, or otherwise use it for commercial advantage.

Because of the non-commercial restriction this is **source-available** rather
than an OSI-approved "open-source" license — but the source is fully open for
personal use and contributions. © 2026 Volodymyr Gutorov and the Claude Mate
contributors.

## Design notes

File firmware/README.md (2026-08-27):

# Firmware

Two devices speak the same protocol, byte for byte. The daemon cannot tell them
apart, and **both can be connected at once**.

| | `claude_mate/` (iteration 1) | `claude_mate_s3/` (iteration 2) |
|---|---|---|
| Board | Arduino Nano | Waveshare ESP32-S3-LCD-1.47**B** |
| Display | 128×32 mono OLED (SSD1306) | 172×320 colour IPS (ST7789) |
| Transport | USB serial | **BLE or Wi-Fi (TCP)**, stored in NVS and switched over USB (`I\|BLE`); USB as fallback |
| Buttons | 3 — PREV / GO / NEXT | 4 — PREV / GO / NEXT / **MENU**, Kailh Choc (1350) |
| Alert LED | one LED, rhythm only | WS2812, rhythm **+ colour**, adjustable (incl. off) |
| Power | USB | USB or a 14500 Li-ion cell, with a battery gauge |
| On-device UI | — | a menu: settings, about, the game, sleep |
| Screen sleep | — | off after 1–30 min when nothing needs you |
| Flash with | `arduino-cli upload` | **`./flash_s3.sh`** (see below) |

The Nano build is **unchanged** by the S3 work and remains fully supported. The
S3 is an addition, not a replacement — the extra pixels buy typography, colour
and the terminal mirror, never a different information model.

---

## Arduino Nano — `claude_mate/`

Wiring is in [`docs/WIRING.md`](../docs/WIRING.md).

```bash
arduino-cli compile -b arduino:avr:nano:cpu=atmega328 firmware/claude_mate
arduino-cli upload  -b arduino:avr:nano:cpu=atmega328 -p /dev/cu.usbserial-XXXX \
                    firmware/claude_mate
```

Boards shipping the **new** bootloader need `cpu=atmega328` (as above) at
115200; older ones want `cpu=atmega328old`. Library: **Adafruit GFX**, and only
that one — the SSD1306 is driven by the bundled `softssd1306.h`, a software-I2C
`Adafruit_GFX` subclass that puts SCL on A3 (hardware SCL A5 was damaged) and
leaves SDA on A4. Adafruit SSD1306 is *not* needed; CI compiles this sketch with
Adafruit GFX alone.

`selftest/` is a standalone sketch that exercises the OLED, buttons and LED with
no daemon attached — flash it first when bringing up new hardware.

---

## ESP32-S3 — `claude_mate_s3/`

A cordless companion: colour LCD, four buttons, and a wireless link to the daemon
so it can sit anywhere on a battery.

- `claude_mate_s3.ino` — protocol, the CONDUCTOR view, the menu, hibernate
- `board_s3.h` — pin map, layout geometry, palette, battery/charging constants
- `netcfg.h` — Wi-Fi transport, mDNS discovery, HMAC handshake, NVS config,
  setup portal
- `blelink.h` — the same line protocol over BLE: duty-cycled advertising, a GATT
  service, the same HMAC handshake. The alternative to `netcfg.h`, never
  simultaneous with it — one 2.4 GHz radio
- `blepad.h` — the device as an ordinary Bluetooth HID gamepad
- `settings.h` — the device's own preferences (NVS, `mate-ui` namespace). The
  only state here that is neither the daemon's nor the network's; none of it is
  about a session, so the daemon has no business knowing

**Library:** *GFX Library for Arduino* (Arduino_GFX, by moononournation).

### Board options

```
esp32:esp32:waveshare_esp32_s3_lcd_147
    CDCOnBoot=cdc          REQUIRED
    USBMode=hwcdc
    PartitionScheme=app3M_fat9M_16MB
```

`CDCOnBoot=cdc` is **not** the board default, and without it `Serial` maps to
UART0 instead of USB — the `?` / `W|` / `S|` / `T|` config commands then have
nowhere to go. The 3 MB app partition is required because Wi-Fi plus the display
does not fit the default 1.2 MB.

`PSRAM=enabled` already means **OPI** on this board (`psram_type=opi`, correct
for the S3R8); do not "fix" it.

### Wiring you add

The bare board has only BOOT and RESET. Add four momentary switches, each
`INPUT_PULLUP` with its other leg to **GND** — no resistors, no debounce caps
(the firmware debounces in software, and all four grounds may share one wire):

```
PREV → GPIO 3     GO → GPIO 4     NEXT → GPIO 5     MENU → GPIO 6
```

The reference build uses **Kailh Choc low-profile (1350) switches** with Choc
keycaps, which is what the printed enclosure
([`assets/3d-model/claude_mate_s3.stl`](../assets/3d-model/claude_mate_s3.stl))
is cut for — three across the bottom, one above them at the left, with the LCD
on a raised shelf to their right. Tactile or linear is taste; the firmware
debounces either. Any momentary switch works if you print your own plate.

GPIO 3 is a strapping pin but an inert one: it selects the JTAG source and is
only sampled when `STRAP_JTAG_SEL` is burned, which is not the factory default.
Boot mode is decided by GPIO 0 and GPIO 46, neither of which is wired to a
button, so no button held through a reset can strand the board in download mode.
Verify with `espefuse summary` if in doubt.

**Battery:** nothing to solder. Plug a **14500 Li-ion cell (AA-sized, 3.7 V,
~800 mAh)** into the onboard battery header; the charger and the sense divider
are on-board, landing on GPIO 1. Do not connect anything to GPIO 1 yourself.

The chemistry is not interchangeable. The board's charger is a **4.2 V Li-ion**
charger, and `board_s3.h` calibrates both the percent curve and the
charge-trend detection for that (`CHARGE_FULL_MV 4150`, `BATT_LOW_MV 3300`). A
3.2 V LiFePO4 cell of the same physical size would be over-charged by the board
*and* read as permanently flat. A larger Li-ion cell (an 18650) is electrically
fine but creeps too slowly for the trend fallback — see the note at the
constants.

**Board revisions differ in exactly one pin:** the backlight is **GPIO 46** on
the ‑1.47B and GPIO 48 on the original ‑1.47. The wrong value fails in a
maddening way — the ST7789 is driven perfectly and the panel simply never
lights, which looks like a dead board or a bad flash.

### Flashing: use `./flash_s3.sh`

```bash
./firmware/flash_s3.sh              # compiles, then flashes the first usbmodem
./firmware/flash_s3.sh /dev/cu.usbmodemXXX
```

**`arduino-cli upload` does not work on this board.** Three quirks bite at once:

1. **Download mode.** `--before default-reset` (esptool's default, and what
   arduino-cli uses) drives the virtual DTR/RTS straps, which this board
   ignores — you get *"Failed to connect: No serial data received"*.
   `--before usb-reset` does a USB-level reset and works from a running app,
   with no BOOT/RESET press.
2. **The link cannot sustain a large transfer.** One ~680 KB stream stalls at a
   random point (2 %–24 % observed) with the USB node still present. So the app
   is written in **32 KB pieces**, one esptool run each, every piece verified by
   a device-side MD5. Roughly ten absorbed stalls per run is normal here, not a
   fault; retries alternate `no-reset` / `usb-reset` so a stall self-heals.
3. **Booting afterwards.** `--after hard-reset` re-asserts the GPIO 0 strap and
   lands straight back in download mode — dark screen, silent serial, esptool
   refusing to reconnect, indistinguishable from a bricked board. The script
   finishes with `--after watchdog-reset`.

Verifying the whole app with `verify-flash` can never complete: a 1 MB readback
hits the same ceiling as a 1 MB write, so it would fail on a perfectly good
image. Trust the per-piece hash plus the read-back verify of the small regions,
which the script does.

If automatic entry fails, the script falls back to prompting for a manual
**BOOT + RESET** (hold BOOT, tap RESET, release BOOT).

### First boot and provisioning

An unprovisioned board comes up **on BLE**, advertising as `Claude Mate` with no
token, and says so on the glass: `no token: claude-mate-connect`.

**With a cable, you do nothing.** The daemon hands its token to whatever appears
on the USB port, so a factory-reset board provisions itself and links a few
seconds after being plugged in.

**Without one, pair it — one command and one button:**

```sh
claude-mate-connect --pair      # or press `d` at the account picker
```

The device puts **PAIR?** on its screen; press **GO** on the device and it is
done. No access point, no phone, no secret typed by hand. The `E|` exchange
behind it is described under [BLE as the link itself](#ble-as-the-link-itself).

The long way round is still there for a board whose BLE will not start: hold
**BOOT** at power-on (or send `Z` over USB) to raise the setup portal — an access point
whose name and password are on the glass — join it from a phone at
`http://192.168.4.1`, paste the token and leave **Network** as *none*. Or
`T|<token>` down the cable.

**That default is a bootstrap fix, not a preference.** A board with empty NVS
used to default to Wi-Fi, which meant the setup portal — and the portal outranks
every screen on the device — including, at the time, the only row that could
have moved it to BLE. A factory-reset cordless board was therefore held in a portal it
had no credentials to satisfy, with the way out visible from nowhere. A board
that has an SSID stored is not affected: it still comes up on Wi-Fi, because an
upgrade must not move a working device onto a different radio behind its owner's
back.

**For Wi-Fi instead**, send `W|<ssid>|<password>` and then `I|WIFI`, or use the
setup portal — `Z` over the cable, or BOOT (or GO) held at power-on. Nothing
Wi-Fi is on the device's menu at all; see **Settings** below for why.

**For Wi-Fi with no network to join**, send `I|P2P`. The device stops being a
client and becomes the access point: it brings up `Claude-Mate-XXXX` with a
password generated **once and kept** (unlike the portal's, which is regenerated
every time, because the Mac is expected to save this network and rejoin it at
every login). Join it from the Mac and the device reads the Mac's DHCP lease off
its own AP and dials the daemon — same handshake, same protocol, no router and
no credentials anywhere. `I|P2P` prints the network and password before it
reboots; `?` prints them again, along with whether the Mac has joined yet.

Note that a P2P device is an AP for as long as it is on, which is the heaviest
radio state this firmware has — see [POWER.md](../docs/POWER.md). And the Mac
has one Wi-Fi radio: while it is on the device's network it is not on yours.
The portal shows an access point name (`Claude-Mate-XXXX`) and a password that is
regenerated on every portal start. Join it from a phone, open
`http://192.168.4.1`, and fill in the network, password, **shared token**, and
port (8787); leave the host blank to discover the daemon over mDNS.

On a device whose link is **BLE** the same page is the no-cable way to provision
a token: the network is optional there (the dropdown offers **none**), and the
token reaches the running BLE stack, so it takes effect on the next handshake
without a reboot. That portal also expires after 5 idle minutes and hands the
glass back, since it is not the only way out of there.

**Where the token comes from.** Run the daemon with `--tcp` or `--ble` once and
it creates one, prints it, and saves it to `~/.config/claude-mate/token` (mode
0600). Send that string as `T|<token>`, or paste it into the portal's **Shared
token** box. It used to refuse to start
without one, which left you having to know to create the file by hand before the
portal would ever be satisfiable.

> **An empty token box means "keep the one I have".** It used to write
> unconditionally, so coming back to the portal to change networks — filling in
> the Wi-Fi password and nothing else — silently erased the token, after which
> the device could never finish the handshake and just said it was not
> connected. To clear a token deliberately, tick **Erase the stored token**, or
> send `X|WIPE` over serial.

If a connection attempt fails, the reason now shows on the device's bottom line
for 20 seconds (`x no token configured`, `x wifi lost`, …) instead of the device
silently cycling back through `dialing…` — every failure used to look identical
from across the room.

Or provision over USB serial:

```
?                     print the current config (never the token itself)
W|<ssid>|<password>   set Wi-Fi credentials
S|<host>|<port>       set the daemon address (empty host = mDNS discovery)
T|<token>             set the shared secret (must match the daemon's)
I|AUTO I|CABLE I|BLE  which link the device uses (reboots into it)
I|WIFI I|P2P          ...wifi needs credentials stored first
X|WIPE                clear all stored config
R                     reboot
Z                     start the setup portal now
```

`?` also reports the link state and the battery gauge's raw millivolts, which is
the quickest way to tell a mis-set `BATT_DIVIDER` from a genuinely flat cell.

### The battery indicator is three segments, not a percentage

Three green, two amber, one red. That is not a simplification for its own sake —
a percentage was actively misleading here, and the failure is easy to reproduce:
unplug a full cell and the reading falls from 4200 mV to about 3950 mV within
minutes, so the display went **100 % → 79 %** with nothing wrong.

Every one of those numbers was honest. The display was still a lie:

- **4200 mV is the charger's constant-voltage point, not the cell's charge.**
  While plugged in you are reading the charger, not the battery.
- **A Li-ion just off charge carries surface charge** that relaxes over tens of
  minutes. That fall is not consumption.
- **The curve is steep here** — roughly 9 mV per percent — so ordinary ADC noise
  on an unfiltered divider is worth whole percentage points.

A number invites you to trust its last digit. Three segments promise only what
one voltage reading through a noisy divider can deliver, and the thresholds
(3900 / 3700 mV) are placed so a fresh cell's relaxation stays inside the top
segment instead of visibly draining.

Two guards sit behind it, stopping different things. **Hysteresis** (60 mV, fall
only — rise on touch) stops a voltage sitting on a threshold flickering between
levels. A **45-second hold** stops a genuine but brief excursion — a Wi-Fi TX
burst, a backlight step, the sag as the screen wakes — from moving the display at
all. Neither alone is enough: hysteresis lets a long sag through, and a hold
alone still flickers once it expires. The EMA also slowed from 1/8 to 1/16
(~80 s), since a three-level display has no use for speed.

The exact percentage and millivolts are still in `?` and on the About page.
Diagnosis wants the number; a glance wants the shape.

The daemon side needs `--tcp` (or `CLAUDE_MATE_TCP=1`) and a token in
`~/.config/claude-mate/token`. Config lives in NVS, a separate partition, so it
**survives a reflash**.

### The 4th button carries three gestures

It is the only button whose meaning the daemon does not own, which makes it the
only place the device can grow a UI of its own.

| Gesture | In CONDUCTOR | In the menu |
|---|---|---|
| **Tap** | open/close the terminal mirror | back out one level |
| **Double-tap** | open the menu | — |
| **Hold 2 s** | long sleep (deep sleep) — a tap wakes the board | same |

A tap is **deferred by 300 ms**, because a first tap is not yet knowably a single
one. That cost is paid by the least latency-sensitive of the three on purpose:
the mirror already waits a daemon round-trip, so 300 ms disappears into latency
that was there anyway. 300 ms is also the daemon's own `DOUBLE_CLICK_S`, so both
double-taps on this device — GO's FOLLOW toggle and this one — want the same
rhythm from your thumb.

The hold is deliberately much longer than any other gesture: switching off by
fumbling a button would be a poor joke on a device whose job is to be
glanceable. It works with the screen dark, too — reaching for the device to
switch it off should not need two goes.

### The menu

Firmware-local, and the **only** part of this device the daemon knows nothing
about. While it is up, PREV/NEXT/GO are handled here and **never emitted** — a
GO forwarded while you were aiming at a settings row would raise a terminal you
were not looking at. The daemon simply sees no button events, keeps its frame
current the whole time, and needs no protocol change.

```
  ┌──────────────────────────────────────┐
  │ ▁▄█ CLAUDE MATE               ▰ 64%  │
  ├──────────────────────────────────────┤
  │        ┌────────┐                    │
  │        │  ▤▤▤   │   ⚟     ▦     ☾    │  ← the selected tile is enlarged
  │        └────────┘                    │
  │            CONDUCTOR                 │  ← only the selected item is labelled
  │  PREV/NEXT move   GO open   4th back │
  └══════════════════════════════════════┘
```

A horizontal strip rather than a list, and not as a style preference: this panel
is 320×172, so a vertical list uses a fifth of the width and runs out of height
at five rows, while a strip has room to spare in the axis it actually has. Only
the selected item is labelled — several labels at once are either unreadable at
size 1 or collide at size 2, and the icons carry the recognition once you have
been here twice. They are drawn from primitives: at 34–46 px a font glyph is
unrecognisable, and a bitmap costs flash plus a second place to keep the design.

**Four items, not six.** ABOUT and WI-FI used to sit here and are now rows in
SETTINGS, because neither is a *place you go* — one is something you read and the
other is something you set, which is what that page is for. Keeping them on the
strip meant the top level grew every time the device learned a new trick, and
the strip is the one screen that has to stay scannable at a glance. The pitch
did not change; only the origin, since three gaps span 156 px instead of five
spanning 260.

| Item | What it does |
|---|---|
| **CONDUCTOR** | back to the triage view — the daemon's frame, unchanged since iteration 2 shipped |
| **SETTINGS** | the ten rows below |
| **SHIP IT** | the platformer, played on a contribution graph. Runs on the device itself; the record survives a flat battery |
| **SLEEP** | the same deep sleep the 2 s hold does, made discoverable |

### Settings

Eight rows, five visible, so the page scrolls and draws a scrollbar — without
one a cut list simply looks complete. Everything is computed from the row count,
so adding a row costs nothing but the row.

**There is no `Link` row, and that is deliberate.** It was a plain toggle, so
one press moved a cordless board onto Wi-Fi — and a board with no credentials
then reboots into the setup portal, which outranks the menu and does not time
out for a Wi-Fi device, so it hides the very row you would use to undo it. One
press on the glass, and no way back without a cable. The transport is not
deleted, only off the glass: `I|WIFI` / `I|BLE` still work over USB, which puts
that switch behind a cable you have to actually have — if you can type `I|WIFI`
you can type `I|BLE` back. Which radio is live, and whether it has found the
daemon, is on the **About** page.

**And no setup-portal row either — there is no Wi-Fi anywhere on this menu.**
That row existed for exactly one reason: a factory-reset board with no cable had
no way to be given a token. [BLE enrolment](#enrolment) removed that reason —
`claude-mate-connect --pair` puts **PAIR?** on the glass and one press of GO
provisions the device over the link it was already using. What was left was a
Wi-Fi flow wearing a label that said *Set token*.

The order here matters and is not taste: removing this row **before** pairing
existed stranded a real board within minutes, and `tools/test_ble_link.py`
asserts the `E|?` handler exists in the same breath as asserting the row does
not. The portal is still reachable where a mistake cannot reach it — `Z` over
USB, or **BOOT** (or **GO**) held at power-on — because a board whose BLE will
not start needs something, and both of those need physical access.

| Row | Values | Notes |
|---|---|---|
| **BLE gamepad** | on / off | The device as an **ordinary Bluetooth HID gamepad** — pair "Claude Mate" once in System Settings and macOS presents it as a system controller. **On means the device *is* a gamepad**, across a screen sleep and across a reboot, until you turn it off; off means it is the conductor again and the daemon link comes back. This is the only input path the **public site** can use: the daemon path needs `http://127.0.0.1`, which an https page cannot reach. It also skips Wi-Fi, mDNS, the TCP dial, the daemon and SSE entirely, which is the chain that was making the controller lurch. Four buttons, no axes, physical order (1 = PREV, 2 = GO, 3 = NEXT, 4 = 4th). Leave with a 2 s hold of the 4th button, which turns the switch off too. See the radio policy below |
| **Sleep screen** | off · 1m · 2m · 5m · 10m · 30m | One row, not a toggle plus a duration — the two can never disagree, and it costs one row on a screen that has five. Defaults to **off**: nobody's screen should start going dark because they took an update |
| **Brightness** | 5 steps | Non-linear in duty (20/60/120/200/255). Equal duty steps feel like one enormous jump at the bottom and four identical ones at the top. Applied live, so the step you are on is the step you can see |
| **Alert LED** | off · low · med · high | **off is genuinely dark.** A 7 Hz red strobe is the right answer to a failed turn at a desk and the wrong one in a bedroom — and the alert still arrives, through the flashing name row and fleet letter |
| **Mac sound** | on / off | Named for **where it happens**. "Sound: on" on a device with no speaker would be a promise the hardware cannot keep. Crosses the link at once (`O\|SND\|`) — a toggle that only reached NVS would do nothing until the next reconnect and read as a dead row |
| **Flip screen** | on / off | Applies **on restart**; the row says so and a long GO does it. Rotation is set once after `begin()`, and re-rotating a live panel is the one failure in this firmware that looks exactly like dead hardware |
| **About** | → | Link, RSSI (or, on BLE, which radio and whether the pad has it), battery % + raw mV, boot cause, firmware version. The serial `?` output, on the glass — the only place it can be read on a cordless device with no console attached. The 4th button backs out to **this page**, not to the top strip: one level at a time |
| **Factory reset** | hold GO to confirm | Wipes Wi-Fi, token **and** settings. Asks twice, and the second gesture is a **long** press rather than another tap — you cannot double-tap your way into wiping the token. Disarms itself after 6 s |

Settings live in their own NVS namespace (`mate-ui`), separate from the network
config, which is what lets a factory reset choose what it destroys. Writes are
deferred 1.5 s, so holding NEXT through the brightness steps costs one flash
write rather than five — with **one deliberate exception**: the gamepad switch
is written immediately. Turning it on tears the link down, brings the HID stack
up and hands the glass to the pad face, and a cell pulled in the second and a
half that follows would bring the device back as a conductor while the Mac still
lists "Claude Mate" as a paired controller. One flash write per deliberate
toggle is nothing; a switch that can disagree with reality across a power cycle
is not.

**There used to be two gamepad rows.** *Game controller* opened the
daemon-driven controller mode and *BLE gamepad* opened the HID one, side by side
on a 172 px screen, offering what reads as the same thing twice. They were not
the same thing, but the difference was a transport detail — precisely the kind
of thing a menu must not ask you to hold in your head. The HID one wins on every
axis that matters from the device's side, so the row became one persistent
switch, and the daemon-driven mode survives only where it belongs: as something
the Mac asks for over the link (`G|1`), never as a menu item. **The device's own
switch outranks the Mac's** — a browser tab closing no longer revokes a gamepad
you turned on yourself.

### The radio policy, in BLE gamepad mode

The S3 has **one 2.4 GHz radio**, shared between Wi-Fi and BLE, so holding both
up costs latency on the link that matters — and Wi-Fi is the half that was
misbehaving. But a device that goes deaf for a whole session is worse than a
laggy one: the daemon is the reason this thing exists, and an error you hear
about an hour later is an error you heard about too late.

So the radio follows your thumbs, because nothing else can tell it. **A HID
gamepad is one-way** — the browser has no channel back to the device — so "are
you mid-level?" is answered by "did you press anything recently?".

| State | Radio | Why |
|---|---|---|
| **Pressing things** (within `PAD_PLAY_IDLE_MS`, 6 s) | Wi-Fi parked via `net.shutdown()` | You are playing. `poll()` no-ops in `OFF`, so nothing blocks the loop and BLE gets the air to itself |
| **Still** for 6 s | Wi-Fi back up, link re-dialled | You stopped to read a card, or paused, or wandered off. Go and see what the daemon has |
| **Urgent alert arrives** (`V\|ERROR` or `V\|INPUT`) | Leaves the pad entirely, back to CONDUCTOR | Those two mean a human is blocked. `DONE` and `START` are news, and news can wait until you stop |

The radio is never parked mid-attempt: once it comes up it stays up for at least
`PAD_WIFI_CHECK_MS` (20 s), because tearing a join down before it can finish
would mean the check never actually happens — the device would spend the session
neither playing cleanly nor learning anything, which is the worst of both.

**None of that applies on a BLE link**, and cannot. There the transport and the
pad are two roles on *one stack*, so unparking would mean tearing the HID
connection down and re-pairing every time you paused to read something — not a
policy, a fault. The rule there is the plain one the settings row promises: the
gamepad is on, so the device is a gamepad, and turning it off is what brings the
daemon back.

### BLE as the link itself

Wi-Fi keeps an association up all day for a device that has almost nothing to
say. Status changes are rare and bursty — a session goes WAIT, forty minutes
later it goes DONE — and in between the radio holds a link open to transmit
nothing. That is the wrong shape for a cell, so the battery build can carry the
**same line protocol over BLE** instead (`blelink.h`, and `daemon/blelink.py` on
the Mac). Nothing above the wire knows which pipe it got.

| | Wi-Fi (`--tcp`) | BLE (`--ble`) |
|---|---|---|
| Who dials | the **device** dials the daemon, found over mDNS | the **Mac** scans and connects; the device only advertises |
| Idle radio | association held open continuously | **200 ms of advertising, then ~4 s silent**, repeating |
| Auth | nonce + HMAC-SHA256 over the shared token | *the same handshake, the same token* |
| Blocking the loop | `MDNS.queryService()` has no timeout parameter and a TCP dial costs up to 600 ms — both stop the button poll | nothing blocks; the duty cycle is two comparisons against `millis()` |
| Range | the whole home or office | one room |
| Right for | a host that is **not on this desk** | a device that **is** |

The duty-cycle figures come from [issue #21](https://github.com/vlgutv22/claude_mate/issues/21), credited there to
Jack Jansen in the ESP8266/ESP32 group, who measured roughly 5% of normal
consumption with that rhythm on his own battery devices. **Be honest about what
it saves here:** stopping the advertiser cuts the *radio's* share of the draw,
not the CPU's — this firmware never light-sleeps, because the display, the LED
pattern engine and the button poll all want the loop running. See
[`docs/POWER.md`](../docs/POWER.md).

The advertisement carries **identity, not status**. The issue floated packing
the compact status into the advertising payload, and it cannot work in this
direction: the status originates on the *host* and this device is the
*peripheral*, so the only thing it could advertise about is itself. Status
travels on GATT, where it also gets flow control for free.

Two characteristics, because a GATT characteristic is not bidirectional: an RX
one the daemon writes frames into, a TX one the device notifies button events
on. **A notification boundary is not a line boundary** — the device can pack two
lines into one notification and split one across two — and both ends reassemble
on newlines rather than assuming otherwise.

The link is **not encrypted and does not pair**. "Just Works" pairing is what a
device with no keypad gets, it is unauthenticated by definition, and it would
add an OS-level pairing dance to every fresh Mac. The token handshake is what
actually decides who may drive this device, and it is already provisioned — so
the threat model is exactly the Wi-Fi transport's, stated in the same terms: the
payload is plaintext, anyone in radio range can read session names and states,
and an on-path attacker could inject button events into an established
connection.

**Cost, measured rather than guessed:** the whole transport adds **9,008 bytes
of flash and 2,848 bytes of RAM** against the same sketch without it. It is that
cheap because the BLE stack was already linked in for the HID gamepad — the
~290 KB was paid for once, and this is the second thing to use it.

Select it with `I|BLE` over the cable — the *transport* is deliberately not on
the device's menu, for the reason given under **Settings** (provisioning is).
It is a stored
byte rather than a compile-time `#define` on purpose: moving a device on a desk
between the two should not need a toolchain. Holding BOOT at power-on still
forces the Wi-Fi setup portal whichever transport is stored — that escape hatch
has to outrank the setting, or a device could be locked out by the very thing
you were trying to fix. On a BLE device it outranks it only for as long as it is
up: five idle minutes and the portal expires, the radio goes off, and BLE gets
the glass back. Without that, holding BOOT on a cordless BLE board — which is
also how you enter download mode, so it happens by accident — was a one-way
door into a portal that device had no reason to fill in.

> **BOOT only — GO used to count and no longer does.** Factory reset is confirmed
> with a long press of **GO** and reboots at once, so GO was still held when
> `setup()` read the buttons a few milliseconds later: **every menu factory reset
> came back up in the Wi-Fi setup portal**, on a BLE device, reliably. Two fixes
> went in — `rebootAfterRelease()` waits for the button to come up, and
> `forcePortal` stopped accepting GO at all — because GO is the most-pressed
> button on this device and has no business arming a Wi-Fi flow.
>
> That does mean this gesture needs **BOOT**, which the printed enclosure covers.
> Deliberate: with pairing and USB provisioning, the portal is a last resort for a
> board whose BLE will not start, and a last resort should take deliberate
> physical access. The routes you actually want are `claude-mate-connect --pair`
> or plugging the cable in; `Z` over USB raises the portal without opening
> anything.

#### Why changing the link reboots the device

**BLE does not come back in the same boot.** `BLEDevice::deinit(true)` does not
fully release the controller, and every `BLEDevice::init()` after it fails —
deterministically, silently, forever. Measured on hardware, not assumed:

| | Result |
|---|---|
| Fresh boot → `ble` | `ADVERTISING` ✓ |
| `ble` → `wifi` → `ble` in one boot, swapping stacks in place | `ble : OFF`, permanently |
| ...and `I|BLE` again to force it | still `OFF` — a no-op, since the transport had not changed |
| Reboot | `ADVERTISING` ✓ |

The first cut swapped the stacks in place and worked exactly once per boot in
each direction. Flipping the row twice — which is what anyone does while looking
at a new setting — left the device with **no link at all**, no advertising, no
Wi-Fi, no retry and no way to force one. `ble : OFF` was visible only over a
cable a cordless device is probably not attached to.

So the rule is: **anything that takes the BLE stack down reboots to bring it
back.** The transport is in NVS, so the reboot loses nothing — the device comes
up as exactly what you asked for, in about three seconds, behind a screen that
says which link it is switching to. The same applies to turning the **BLE
gamepad off** on a BLE build, for the same reason: the pad and the link are two
roles on one controller.

There is a backstop underneath that. `blelink.h` remembers that it was asked to
be up and retries a failed start a few times; when those are spent, `stuck()`
tells the sketch and the sketch reboots. Rebooting is genuinely the only way
back, so the only real choice is between doing it deliberately and pretending
the problem is not there.

#### Connecting over BLE, start to finish

There is **no pairing step and no portal**. The device advertises, the daemon
scans, and the shared token — the same one the Wi-Fi transport uses, which a
provisioned device already has — is what lets them attach. Four things have to
be true, and all four are easy to check:

**1. The daemon has `bleak`, in the Python that actually runs it.** This is the
commonest miss, because the daemon usually runs from a LaunchAgent under a
different interpreter than the one on your `$PATH`:

```sh
# which Python is running the daemon?
ps -o comm= -p "$(pgrep -f claude_mate_daemon.py | head -1)"
# ...then install into THAT one, e.g.
/usr/local/bin/python3 -m pip install bleak
```

Without it the daemon says so and carries on over USB, which is a working
daemon and an easy thing not to notice.

**2. The daemon is running with `--ble`.** In the foreground that is literally
`--ble`. Under the **LaunchAgent there are no flags** — `install.sh` writes a
plist whose `ProgramArguments` you are not meant to hand-edit — so use the
environment variable instead, exactly as `--tcp` is enabled:

```sh
PLIST=~/Library/LaunchAgents/com.claudemate.daemon.plist
/usr/libexec/PlistBuddy -c "Add :EnvironmentVariables:CLAUDE_MATE_BLE string 1" "$PLIST"
launchctl unload "$PLIST" && launchctl load "$PLIST"
```

Every `--flag` has a `CLAUDE_MATE_*` twin for this reason; see the table in the
main [README](../README.md#configuration).

**3. macOS is letting that program use Bluetooth.** **System Settings →
Privacy & Security → Bluetooth** must list the program running the daemon —
your terminal, or the Python binary for a LaunchAgent. A LaunchAgent has no
window to raise a prompt from, so it can be refused *silently*: the daemon scans
forever and finds a device that is sitting right there advertising. If the log
says `no device found yet` while the device says it is advertising, check this
before anything else.

**4. The device is actually on BLE.** `I|BLE` over USB sets it (and reboots);
`?` prints `link : ble`, and **SETTINGS → About** shows it on the glass. A board
that has been moved to Wi-Fi is not advertising at all — the stack is down, so
the daemon scans forever and the Mac never sees it.

> **The device will never appear in System Settings → Bluetooth, and that is
> correct.** That pane lists Classic and pairable devices; this is an unpaired
> GATT peripheral advertising in 200 ms bursts every 4 s, and there is no
> pairing step by design (see the threat model in `blelink.h` — the token
> handshake is what decides who may drive the device, not Just Works pairing).
> Only a CoreBluetooth scan sees it, which is what the daemon does. **The
> daemon's log is the only place "is it advertising?" is answerable from the
> Mac** — not the Bluetooth pane, and not a generic scanner app, which will also
> usually miss a 5 % duty cycle.

**Knowing it worked**, from either end:

```
daemon      BLE device connected: 2A55ED32-...
            handshake H -> resending full state

device (?)  link  : ble
            ble   : LINKED  adv 200ms/4000ms  token (set)
```

**When it does not**, the two ends disagree in a way that names the fault:

| Device says | Daemon says | It is |
|---|---|---|
| `ble: start the daemon with --ble` | `no device found yet` | one of 1–3 above — usually the Bluetooth permission |
| `AUTHING`, then `no handshake - is the daemon on --ble?` | *(nothing)* | something connected that is not the daemon. macOS itself probes new GATT services; harmless, and it recycles after 5 s |
| `x token rejected` | `BLE: token rejected` | the device and the daemon hold different tokens. `T\|<token>` over USB, from `~/.config/claude-mate/token` |
| `x no token - claude-mate-connect` | `THE DEVICE HAS NO TOKEN` | exactly what it says, and it is what a factory-reset board says. Run `claude-mate-connect --pair` and press **GO** on the device. With a cable, plugging it in is enough — the daemon provisions it on port open |

### Screen sleep

The backlight is by far the biggest draw on this board — tens of milliamps
against the ~1 mA the WS2812 idles at — so turning it off is most of the runtime
available without touching the radio.

It goes off after the configured delay **only when nothing is waiting on you**,
and what counts as waiting is answered from the frame the device already has:
the flashing name row, any lowercase fleet letter, or a **looping** LED pattern
— which the daemon drives from exactly *"worst unacknowledged alert"* and is
therefore the authoritative signal. An alert turns the screen back on by itself.

Two things deliberately do **not** hold the backlight on:

- **A `working` fleet.** An hour of grinding with nothing to say is precisely
  the case this setting exists for.
- **`NO LINK`.** A dead daemon must not be able to burn the cell flat, which is
  what would happen the moment you carried the device out of Wi-Fi range.

Only the backlight goes off. `displayOff()` would save another milliamp or two
and would put the wake path one command away from the dead-panel failure above;
not worth 2 mA. Rendering is skipped while dark (a full flush is ~28 ms of SPI),
but the frame keeps arriving and being parsed, so waking shows the **current**
state rather than a stale one that then jumps. The terminal mirror is closed on
the way down — polling a wrapper once a second to draw onto a dark panel is the
one case where hibernating saves nothing and costs the Mac work.

**A press on a dark screen only wakes, and is swallowed.** Phone convention, but
for a specific reason: GO raises a terminal window, so obeying a press aimed at
a screen you cannot read would occasionally yank you to the wrong session — the
exact thing this device exists to prevent. The 2 s hold is the one exception.

"Off" means **deep sleep, not zero**. The WS2812 has no shutdown pin and idles
around 1 mA whenever the rail is up, which dwarfs the ~8 µA the S3 itself draws
asleep. That works out to roughly a month of standby on a 14500 — off in every
practical sense, but a switch in the battery lead remains the only true zero.

Waking **reboots**: deep sleep does not resume, it re-runs `setup()`. Config is
in NVS so nothing is lost, but rejoining Wi-Fi costs a few seconds. `?` reports
`boot : woke from power-off` or `power-on / reset`, which is the only way to
tell a deliberate wake from a brownout after the fact.

Three details in the implementation are load-bearing, and all three fail
silently if skipped:

- The backlight pin is driven low **and latched** (`gpio_hold_en`). Deep sleep
  releases every GPIO, so an unheld pin floats and the panel can sit there lit,
  burning the current this is meant to save. The latch survives the reboot, so
  `setup()` must release it first — otherwise the board wakes to a black screen,
  indistinguishable from the dead-panel failure a wrong `LCD_BL` causes.
- It **waits for the button to be released** before sleeping. The wake is
  level-triggered on LOW, so sleeping with the button still down wakes the chip
  instantly and reads as "power off is broken".
- The Wi-Fi link is closed **politely**. A half-open socket leaves the daemon
  holding a dead client and still listing the device as present.

### The terminal mirror

Tapping the 4th button in **CONDUCTOR** opens a live view of the selected
session's real terminal, refreshed about once a second; PREV/NEXT then scroll it
and GO closes it and raises the actual window. Only **wrapped** sessions can be
mirrored — a hook-only session has no PTY for the daemon to read and says so.
See [`docs/PROTOCOL.md`](../docs/PROTOCOL.md) for the wire format.

While the view is open the **daemon** reinterprets PREV/NEXT as scroll, so the
firmware never learns that this particular mode exists: it emits the same two
verbs either way and draws whatever rows arrive. That is still true of the
mirror. It is *not* true of the menu, which is the firmware's own and swallows
those buttons — see [The menu](#the-menu).

Terminal contents cross the network on the same token-authenticated but
**plaintext** TCP link as everything else. That is a bigger exposure than a
status string; keep it to networks you trust.

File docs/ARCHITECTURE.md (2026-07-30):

# Claude Mate — Architecture

Claude Mate is a hardware companion for Claude Code. Two devices speak the
identical protocol and may be connected at once:

- **Arduino Nano over USB** (iteration 1) — an I2C OLED, three buttons, and an
  **indication LED**. Everything below describes this device unless stated
  otherwise; it is the reference implementation of the protocol.
- **ESP32-S3 over Wi-Fi** (iteration 2) — a 172×320 colour LCD, four buttons, a
  WS2812, and a Li-ion cell. It reaches the daemon over TCP (mDNS-discovered,
  HMAC-authenticated) instead of a cable. It renders the *same* pre-rendered
  frame; the extra pixels buy typography and colour, never a different
  information model. Its one extra capability is the
  [terminal mirror](#the-terminal-mirror-esp32-s3-only). See
  [`firmware/README.md`](../firmware/README.md).

The daemon is written so that anything the Nano cannot do sits behind a verb the
Nano never sends, which is why iteration 2 required no change to iteration 1.

The Nano drives a small I2C OLED, three buttons, and an **indication LED**. The daemon
keeps ONE **stable, alphabetically-ordered** **triage queue** of sessions (tabs
never shuffle as their states change) and the OLED shows ONE screen — the
*selected* session (the selection is **sticky**: only PREV/NEXT/GO ever move
it): four size-1 rows — the session name, the
state + time-in-state (+ the account the session runs as), the model + effort
(+ a remaining-limit chip, e.g. `5h82%` = 82% of the 5-hour window left), and a
whole-fleet letter strip (with the queue position). The LED blinks a
status-distinct pattern (driven by the daemon) for the worst unacknowledged
alert, looping until you acknowledge it. It shows the live status of one or
more Claude Code sessions running in the VS Code native extension (and/or the
terminal CLI) on a Mac, and lets you press a button to **raise** the window of
a session that needs your attention.

Retry / resubmit is intentionally **out of scope** (see [Limitations](#limitations)).
**Focus is the must-have action.**

---

## Data flow

The end-to-end flow is one-directional for *status* (Claude → hardware) and a
short return path for *buttons* (hardware → action):

```
Claude Code hook event (UserPromptSubmit, Notification, Stop, StopFailure)
        |
        v
~/.claude/hooks/claude-status.sh        (fire-and-forget, always exits 0)
        |   one newline-terminated line:  <state>|<session_id>|<name>
        |   (a Stop whose payload still lists background_tasks — or a one-shot
        |    session_cron — reports 'working': the turn ended, the work did not)
        v
Unix domain socket  /tmp/claude-mate.sock
        |
        v
Python daemon  (daemon/claude_mate_daemon.py)
        |   - keeps session-state model keyed by session_id
        |   - keeps ONE triage queue in STABLE order (alphabetical by
        |     name, tiebroken by session key) — tabs never shuffle
        |   - urgency (worst unacked: error > waiting > done, oldest
        |     first) is separate: drives the LED + fleet blink only
        |   - pre-renders ONE screen:  F|<flags>|<sel>|<r0>|<r1>|<r2>|<r3>
        |   - drives the LED:  V|<kind> for the worst unacked alert class
        v
USB serial  (115200 8N1, ASCII lines, '|' delimited, '\n' terminated)
        |
        v
Arduino Nano (ATmega328P)
        |
        +--> OLED SSD1306 128x32 (software I2C, addr 0x3C)  draws the one frame it
        |                                            was last sent: four size-1
        |                                            rows — name (flashing ~2.5 Hz
        |                                            while unacked), state+time
        |                                            +account, model+effort
        |                                            +remaining-limit, fleet strip
        +--> indication LED (D8)                    plays V|<kind>: START one-shot;
                                                     INPUT/DONE/ERROR loop until V|OFF

Buttons back (return path) -- layout PREV | GO | NEXT:
        Button press (PREV=D4, GO=D2, NEXT=D3)
        |   serial line: B|P PREV · B|N NEXT · B|G GO-short · B|K GO-long
        v
        Arduino  -->  serial  -->  daemon
        |
        +-- B|P PREV   : selection one step up the queue   (auto-repeats while held)
        +-- B|N NEXT   : selection one step down the queue (auto-repeats while held)
        +-- B|G GO     : single = ack + RAISE the shown session's window (stay);
        |                 double-click = toggle FOLLOW mode
        |                 best    : PTY wrapper ctrl socket ('focus' — raise only)
        |                 primary : macOS deep link  (open <FOCUS_URI_TEMPLATE>)
        |                 fallback: raise VS Code window for the workspace cwd
        +-- B|K GO-long: acknowledge WITHOUT raising anything
```

A handshake byte closes the loop after every reset. Opening the USB serial port
resets the Nano (~1.5 s), so on boot the Arduino emits `H`; the daemon answers
`H` by **re-sending the full current state** (the current frame + re-arming the
LED loop), and the OLED redraws it. This keeps the display correct across
reconnects without any persistent storage on the device.

---

## Component diagram (ASCII)

```
 +-------------------------------------------------------------+
 |                          macOS host                         |
 |                                                             |
 |  +----------------+        +-----------------------------+  |
 |  |  Claude Code   |        |   Python daemon (always-on) |  |
 |  |  (VS Code ext  |        |                             |  |
 |  |   or CLI)      |        |  +-----------------------+  |  |
 |  |                |        |  | socket server thread  |  |  |
 |  |  hook events   |        |  |  /tmp/claude-mate.sock|  |  |
 |  +-------+--------+        |  +-----------+-----------+  |  |
 |          |                 |              |              |  |
 |          | runs            |              v              |  |
 |          v                 |  +-----------------------+  |  |
 |  +----------------+   sock  |  | session registry      |  |  |
 |  | claude-status. +-------->|  |  (dict keyed by sid)  |  |  |
 |  |     sh (hook)  |  line   |  |  + the triage queue   |  |  |
 |  +----------------+         |  +-----------+-----------+  |  |
 |                             |              |              |  |
 |                             |   +----------+----------+   |  |
 |                             |   |                     |   |  |
 |                             |   v                     v   |  |
 |                             | +-----------+   +-----------+|  |
 |                             | | screen    |   | serial    ||  |
 |                             | | composer  |   | maintainer||  |
 |                             | | + 1 Hz    |   | + button  ||  |
 |                             | | ticker    |   | reader    ||  |
 |                             | +-----+-----+   +-----+-----+|  |
 |                             +-------|---------------^------+  |
 |                                     |               |         |
 +-------------------------------------|---------------|---------+
                                       | USB           | B|P / B|N / B|G / B|K
                             F|.. V|.. P | CDC          | H
                                       v               |
                              +-----------------------------------+
                              |        Arduino Nano (328P)        |
                              |                                   |
                              |  +--------+    +----------------+ |
                              |  | OLED   |    | indication LED | |
                              |  | 0x3C   |    | D8, V|<kind>:  | |
                              |  | one F| |    | START one-shot | |
                              |  | frame  |    | INPUT/DONE/ERR | |
                              |  |        |    | loop until OFF | |
                              |  +--------+    +----------------+ |
                              |   [PREV D4]  [GO D2]  [NEXT D3]   |
                              +-----------------------------------+
```

The daemon is the brain. The Arduino is a thin display + input device: it holds
no session model, makes no policy decisions, and simply renders the one frame
the daemon last sent and reports button presses. The only screens it draws on
its own are the boot **splash** (`MATE / starting...`) and the **LINK LOST**
screen (`NO LINK / waiting for daemon`) after ~30 s of daemon silence; on every
accepted press it also inverts the whole panel for ~80 ms as instant feedback.

---

## Triage-queue logic

There are **no UI modes** and no aggregate status word. The **triage queue** is a
**stable, alphabetically-ordered** list of sessions — tabs keep their position as
their states change and never shuffle under the user:

```
tab order:  STABLE — alphabetical by name (tiebreak: session key)
urgency:    worst UNACKNOWLEDGED alert (error > waiting > done, oldest first)
            → drives the LED loop class + the blinking fleet letters ONLY
```

Urgency is computed **separately** from the order. It decides only what the LED
blinks about and which fleet letters blink; the shown tab is **sticky** — the
screen never switches subject on its own. An already-acknowledged error never
hides a fresh waiting alert in the LED, but the tab order itself never
reorders.

An alert is born on the transition into `error`/`waiting`/`done` and dies in
exactly four ways — nothing else removes one, so none can be lost silently:

1. **`B|G` GO** — acknowledged + the window raised.
2. **`B|K` ACK** — acknowledged, no window op.
3. **Auto-resolve** — the session leaves the alert class on its own (the user
   answered in the terminal → `working`; a new turn started).
4. **TTL prune** — `done` sessions drop after 120 s without updates; anything
   drops after 600 s.

Acknowledging a `done` session turns it `idle`. **Flap suppression:** a session
re-entering the SAME alert class within 5 s of being acknowledged stays
acknowledged, so a bouncing detector cannot re-fire the LED the user just
silenced.

### The indication LED

The OLED is the **sole visual status**; the **indication LED on D8** is the
alert output, driven **entirely by the daemon** via `V|<kind>` lines — the
firmware just plays the pattern. The pattern is always the class of the
**worst unacknowledged alert** across all sessions (`ERROR` > `INPUT` >
`DONE`), so the LED loops exactly while something needs the human:

```
START   one long 1 s blink, then dark                 one-shot
INPUT   aggressive even blink (~2.8 Hz)               LOOPS until V|OFF
ERROR   super-aggressive fast strobe (~7 Hz)          LOOPS until V|OFF
DONE    cascade — 4 quick blinks, then a pause        LOOPS until V|OFF
OFF     LED off now                                   (sent when nothing is unacked)
```

The daemon (re)sends a loop kind only when the desired loop *changes*, so the
link is not spammed. As a failsafe the firmware stops any loop **and shows the
LINK LOST screen** if the daemon goes fully silent for ~30 s. See
[PROTOCOL.md](PROTOCOL.md) for the exact contract.

---

## Screen behaviour

The screen is **daemon-driven**: the Arduino only ever shows the single frame
it was last told to show via an `F|<flags>|<sel>|<r0>|<r1>|<r2>|<r3>` line.

- **What a frame shows:** four size-1 rows (≤ 21 chars each) — **r0** the
  selected session's name (full width, ~21 chars, inverting ~2.5 Hz while its
  alert is unacknowledged); **r1** the state (4-char tag
  `ERR `/`WAIT`/`DONE`/`WORK`/`IDLE` + time in that state, plus the session's
  account right-aligned); **r2** the best-fit model + effort plus the
  remaining-limit chip right-aligned (e.g. `5h82%`); **r3** the fleet strip (`pos/total` + one
  status letter per session in stable (alphabetical) order, space-separated —
  `E` error, `B` waiting, `W` working, `D` done, `I` idle; cut with a trailing
  `+` when it doesn't fit). An unacknowledged alert's letter is sent **lowercase**
  so the firmware **blinks** it — the acked/unacked state of every tab is
  visible in the strip.
- **Screen ownership:** the display NEVER changes subject on its own — only
  PREV/NEXT/GO move the selection (it falls back to the first tab only when
  the selected session ends). A GO/ACK **stays on the tab** it acted on — the
  device never auto-switches tabs.
- **Active-tab highlight / FOLLOW:** the shown session's fleet letter is drawn in
  a **wide (~11 px) filled rectangle centred on it** (a lit block, letter knocked
  out) so you can see which tab is on screen. Double-clicking GO toggles
  **FOLLOW** mode (a ► marker by the state row): PREV/NEXT then also raise the
  selected terminal, ~250 ms after the selection settles (raise only — never ack
  or collapse).
- **Navigation:** **PREV** / **NEXT** step the selection up/down the queue,
  wrap around the ends, and auto-repeat while held (400 ms to start, then
  5/s). Selection is tracked by session **key**, so the subject stays put as
  sessions come and go (only the `pos/total` number changes).
- **WYSIWYG:** GO/ACK act on exactly the session whose frame is on the glass —
  never a freshly recomputed most-urgent alert. So a press can only ever raise the
  terminal whose name the user is actually looking at.
- The daemon sends an `F` line whenever the rendered bytes change: immediately
  on any state change or button, and ~1/s while a displayed time ticks.
  Identical frames are not re-sent (except on handshake). With **zero
  sessions** it sends `F|0|-1|MATE|no sessions||`.

Long sibling names that collide at the row width are disambiguated with a
middle squeeze (first 9 + `~` + last 10, e.g. `webapp-ba~ervice-one`). The
exact line format is in [PROTOCOL.md](PROTOCOL.md).

---

## The terminal mirror (ESP32-S3 only)

Tapping the S3's fourth button opens a live view of the selected session's
**actual terminal** on the device, refreshed about once a second. It is the one
capability the three-button build could not have: acknowledging and FOLLOW were
already reachable through GO's long-press and double-click, so a switch spent on
either would have bought a shortcut.

It reuses plumbing that already existed rather than adding a channel:

1. The PTY wrapper already mirrors the full TUI into a headless terminal
   emulator (**pyte**) — it was only mined for state and model/effort. It now
   also publishes that rendered text and serves it on the command `screen`.
2. The daemon already holds a **per-session control socket** to every wrapper
   (used for `focus`). The mirror is a request/response on that same socket, so
   there is no new socket, no streaming, and **zero cost when nobody is
   looking** — polling runs only while the view is open.
3. The daemon clips rows to the device's geometry and pushes them as `M|` lines,
   exactly as it pre-renders `F|` frames. The firmware stays a dumb renderer.

Three details are load-bearing:

- **The wrapper's reply is length-prefixed** (`SCREEN <n>`, then `n` rows, then
  `ok`) rather than sentinel-terminated. Terminal output can contain any line,
  *including one that is exactly `ok`*, which would truncate the mirror at an
  arbitrary point.
- **Blank runs are collapsed** before the tail is taken. A TUI is not a
  scrolling log: Claude's screen puts the banner and conversation at the top, a
  wide gap in the middle, and the input box pinned at the bottom, so a naive
  tail of the last rows mirrors the gap and shows nothing.
- **Rows are clipped, never reflowed.** A TUI's box drawing and alignment carry
  meaning; rewrapping turns it into noise.

While the view is open the **daemon** reinterprets PREV/NEXT as scroll, so the
firmware never learns a mode exists — it emits the same verbs either way. GO
closes the view and raises the real window: looking at a copy is superseded by
having the original. Only **wrapped** sessions can be mirrored; a hook-only
session has no PTY and says so, rather than showing a blank screen that would
read as an idle session.

**Privacy.** Terminal contents cross the network on the same token-authenticated
but **plaintext** TCP link as everything else. Sending `WAIT` and `Opus 4.8` is a
very different exposure from sending raw output, which can include keys and file
contents. Keep it to networks you trust.

---

## Focus mechanism

Focus is the single must-have action, and it is the **only window operation in
the entire system**: navigation NEVER touches macOS windows, and focus only
**raises/activates** — the daemon never collapses, resizes, or miniaturizes
anything (the wrapper's `collapse` verb still exists for compatibility, but the
daemon never sends it). When you press **GO** on a session, the daemon tries to
bring you to it:

1. **Best — the PTY wrapper's own terminal.** For wrapped sessions the daemon
   connects to the session's per-session control socket and sends the single
   verb `focus`; the wrapper raises + un-minimizes + activates *its own*
   terminal window. The wrapper replies in two stages — `go` on receipt
   (liveness), `ok` after the window op completed — and the daemon serializes
   focus work on a side thread, so consecutive GO presses raise windows in
   press order (a press still queued when a newer one arrives is dropped —
   last wins).

2. **Primary — VS Code deep link.** The daemon runs the macOS `open` command
   against a URI built from a configurable `FOCUS_URI_TEMPLATE` constant,
   formatted with the session id. Per the VERIFIED FACTS, the documented URI
   handler is:

   ```
   vscode://anthropic.claude-code/open?session={session_id}&prompt={prompt}
   ```

   This opens/links a Claude Code chat tab for the given session id. Keeping it
   behind a single constant means if the precise URI changes, it is a one-line
   fix.

3. **Fallback — raise the workspace window (always implemented).** When the
   session id is unknown/stale, or the primary `open` returns nonzero, the daemon
   raises VS Code for the session's workspace folder:
   `open -a "Visual Studio Code" <cwd>` (or `code <cwd>` if the CLI is on PATH),
   optionally activating "Visual Studio Code" via AppleScript.

A short GO also **acknowledges** the alert (raising the window = seen); a long
GO (~0.5 s, `B|K`) acknowledges *without* any window op.

---

## Robustness summary

- The daemon **keeps the serial port open continuously** to avoid resetting the
  Nano on every message.
- It **auto-detects** the port (`/dev/cu.usbserial*` then `/dev/cu.usbmodem*`)
  and **auto-reconnects** if the device disappears and returns; it never crashes
  on a missing port.
- Work is split across **threads with locks** (socket server, button reader,
  serial maintainer, 1 Hz ticker) — no busy-wait spinning; focus runs on
  serialized side threads so the button reader never blocks.
- The **hook always exits 0** and never blocks Claude; if the daemon/socket is
  down it silently no-ops with a short timeout.
- The **Arduino** tolerates partial/garbled lines, caps its input buffer
  (96 bytes), ignores malformed lines, and debounces buttons (~40 ms,
  immediate-fire). If the daemon goes silent for ~30 s it stops any LED loop
  and shows the **LINK LOST** screen instead of a frozen display.

---

## Limitations

These are deliberate, documented boundaries — not bugs:

- **Retry / resubmit is not supported in the GUI.** Re-running a failed turn is
  not reliably possible from outside the VS Code GUI, so Claude Mate does not
  attempt it. The hardware surfaces an `error` state as a flashing `ERR` frame
  (with the looping `V|ERROR` strobe) so a human can act, but the only button
  action toward a session is **GO** (raise its window).
- **Model/effort strings are best-effort.** The model/effort row is
  scraped from the live TUI by the PTY wrapper and stays empty for hook-only
  sessions or until scraped. The daemon **never fabricates** it; it fits
  whatever it reliably knows into the 21-char row.
- **Account + remaining limit come from the wrapper too.** The account is the
  wrapper's profile name (`default` for ~/.claude); the remaining-limit chip is
  polled from Anthropic's OAuth usage endpoint with the session's own token
  (read-only — refreshing credentials stays claude's job) and shows the more
  depleted of the 5-hour / weekly windows. Hook-only sessions show neither.
- **Focus depends on the deep link (hook-only sessions).** A wrapped session
  raises its own terminal via its control socket. Hook-only sessions use the
  VS Code deep link derived from the session id (VERIFIED FACTS:
  `vscode://anthropic.claude-code/open?session=...`). Per those same facts,
  **no documented URI pattern exists to programmatically focus an existing
  session inside an already-running chat panel** — the handler opens/links a chat
  tab. When the session id is unknown/stale or the deep link returns nonzero, the
  daemon falls back to **raising the VS Code window** for the workspace folder.
  Focus is therefore best-effort and may land you on the workspace rather than
  the precise chat in some cases.
- **No persistence on the device.** The Arduino holds no state; every reset
  relies on the `H` handshake and the daemon re-sending state. If the daemon is
  not running, the firmware shows the **LINK LOST** screen after ~30 s rather
  than stale data.

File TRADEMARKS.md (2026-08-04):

# Trademarks

Claude, Claude Code and Anthropic are trademarks of Anthropic, PBC.

Claude Mate is an independent, non-commercial project built by one person. It is
**not affiliated with, sponsored by, endorsed by, or officially connected to
Anthropic, PBC.**

References to "Claude" and "Claude Code" in this repository are nominative: they
identify the product this device is built to work with. No Anthropic logo,
wordmark or brand asset appears anywhere in this repository, on the project page,
or on the device — the device glyph and the game sprites are original artwork
drawn for this project (see [docs/GAME.md](docs/GAME.md#9-provenance-of-every-asset)).

Anthropic's trademark guidelines: <https://www.anthropic.com/legal/trademark-guidelines>

If Anthropic, PBC would like any use here changed or removed, email
vlgutv@gmail.com and it will be actioned.

---

## Note for anyone forking or packaging this

Anthropic's published guidelines are permission-first — *"You may only use our
trademarks as specifically permitted by us and only in materials we approve
beforehand"* — and they contain **no** naming carve-out, no nominative-use
exception and no "X for Claude" safe harbour of the kind Mozilla, Slack, the
Linux Foundation and WordPress all publish. Nothing here should be read as
permission to use those marks in *your* project's name.

If you build on this, prefer a name of your own with "for Claude Code" as a
trailing descriptive phrase, rather than a name with the mark inside it.

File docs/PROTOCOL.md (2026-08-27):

# Claude Mate — Protocol (source of truth)

This document is the **authoritative** description of every wire format in Claude
Mate. The daemon, the firmware, and the hook MUST agree with this file verbatim.
If code and this document disagree, the document wins until it is updated.

There are three interfaces:

1. **Serial protocol** — daemon ⇄ Arduino (USB CDC serial).
2. **Socket message** — hook / PTY wrapper → daemon (Unix domain socket).
3. **Session state model** — the triage queue the daemon keeps.

---

## 0. The interface model (one screen, one queue, three buttons)

The daemon keeps ONE **stable-ordered** list of sessions (alphabetical, so tabs
never shuffle) and renders ONE screen: the *selected* session. The firmware is
a dumb renderer: it holds exactly one pre-composed frame (four size-1 rows) and
draws it. All ordering, selection, truncation and layout live in the daemon.

```
+---------------------+
|api-server           |   r0: session name — flashes (inverts ~2.5 Hz) while
|WAIT  0:42       work|   r1: state tag + time-in-state    its alert is unacked
|Opus 4.8 xhigh  5h82%|       + the ACCOUNT the session runs as (right-aligned)
|2/6 E B W D I        |   r2: model + effort + REMAINING-LIMIT chip (right)
+---------------------+   r3: queue position + one status LETTER per session;
                              the active tab's letter sits in a filled rectangle
```

The **account** (`work`, `default`, …) is which Claude login the session runs
as (the PTY wrapper's `--account` profile). The **remaining-limit chip** shows
how much of that account's plan limit is left, for whichever window is more
depleted: `5h82%` = 82% of the 5-hour window remaining, `wk31%` = 31% of the
week left. Both come from the PTY wrapper and are empty (row right edges stay
blank) for hook-driven sessions.

The **active tab** (the session shown above) has its fleet letter drawn in a
**wide filled rectangle** in r3 — a lit block with the letter centred and
knocked out — so you can see at a glance which tab is on screen. Any tab with
an **unacknowledged alert** has its letter **blinking** in the strip, so you can
tell acked from unacked without hunting.

The buttons mean the same thing at all times. The Nano build has **three**; the
ESP32-S3 build adds a fourth, and the first three are identical on both:

| Button (left→right) | Short press | Held / double |
|---|---|---|
| **PREV** | selection one step **up** the queue | auto-repeats (400 ms, then 5/s) |
| **GO** | single: **RAISE** the terminal of the session **shown on the glass** (acknowledging its alert) | **double-click** (≤ 300 ms apart): toggle **FOLLOW** mode. Held ≥ 500 ms: acknowledge **without** raising. |
| **NEXT** | selection one step **down** the queue | auto-repeats (400 ms, then 5/s) |
| **MIRROR** *(4-button devices only)* | open/close a live view of that session's **actual terminal** | — (tap only) |

The 4th button is spent on the one thing three buttons could not do. Acknowledging
and FOLLOW were already reachable through GO's long-press and double-click, so
putting either on a switch would have bought a shortcut; showing the terminal was
not reachable at all. A 3-button device loses nothing — GO keeps all three
gestures — it simply cannot mirror.

**MIRROR mode.** While the view is open the daemon pulls the rendered TUI from
that session's PTY wrapper about once a second and pushes it as `M|` rows, and
**PREV/NEXT scroll the view instead of moving the selection**. That
reinterpretation happens in the DAEMON: the firmware emits the same `B|P`/`B|N`
either way and never learns a mode exists. GO closes the view and raises the real
window — looking at a copy is superseded by having the original. Polling stops
completely when the view closes, so an unwatched fleet costs nothing.

Only **wrapped** sessions can be mirrored: a hook-only session has no PTY for the
daemon to read, and says so rather than showing a blank screen that would look
like an idle session. Rows are **clipped, not reflowed** — a TUI's box drawing and
alignment carry meaning, and rewrapping turns it into noise.

**FOLLOW mode** (toggled by double-clicking GO, or by holding ACK on a
4-button device; shown by a small ► marker by the state row): while on,
PREV/NEXT additionally **raise** the selected session's terminal, ~250 ms after
the selection settles (so holding to scroll never raises the windows it passes
over). Raise ONLY — never ack (ack stays on GO long-press and the ACK button),
never collapse.

**Window contract:** navigation touches macOS windows ONLY in FOLLOW mode, and
then only to **raise/activate** the selected terminal — the daemon never
collapses, resizes, or miniaturizes anything.

**WYSIWYG:** GO/ACK act on **exactly the session whose frame is on the glass** —
never a freshly recomputed most-urgent alert. So a press can only ever raise the
terminal whose name the user is actually looking at.

**No auto-switch, ever:** the selection is **sticky** — the screen only
changes subject when you navigate (PREV/NEXT), and a GO/ACK **stays on the tab
it acted on**. An alert on another tab announces itself through the LED and its
blinking fleet letter, never by stealing the screen. The tab **order** never
changes either.

---

## 1. Serial protocol (daemon ⇄ Arduino)

**Transport:** USB CDC serial.
**Baud:** `115200`.
**Framing:** `8N1` (8 data bits, no parity, 1 stop bit).
**Encoding:** ASCII lines, each terminated by a **single newline** (`\n`).
**Field separator:** the `|` character.

Lines that do not parse MUST be ignored by the receiver (the Arduino caps its
input buffer at 96 bytes and drops malformed/oversized lines).

### 1a. Daemon → Arduino

| Line | Meaning |
|---|---|
| `F\|<flags>\|<sel>\|<r0>\|<r1>\|<r2>\|<r3>` | **The whole screen**, pre-rendered as four size-1 rows. See field table below. At least 7 fields; `r3` is the **last** field and may itself contain `\|`. A **transient notice** (why a press was declined, or which account a switch is heading for) rides in `r1`+`r2` for ~4 s: the daemon owns row rendering, so saying something new on the glass costs no firmware change and works on a device already flashed. `r0` and `r3` are left alone, so the message never loses the session it is about. |
| `V\|<kind>` | LED alert control (indication LED only; never touches the OLED). `<kind>` is `START`, `INPUT`, `DONE`, `ERROR`, or `OFF`. See **LED** below. |
| `L\|<i>\|<n>\|<name>\|<chip>` | **One saved account**, pushed on every handshake so the device's picker can show the logins you already have. Row 0 is always `default` (the `~/.claude` login, which is not a directory under the profiles root — omitting it let the device switch away from your main account with no way back). `i==0` resets the list, so a profile you deleted cannot leave a stale row behind. `<chip>` is that account's remaining-limit chip and may be empty: the names are free, the limits cost an HTTPS round trip each, so the daemon sends names immediately and re-sends enriched a moment later rather than blocking the handshake. Which account has headroom is the whole basis of the choice. Two consequences of that re-send, both load-bearing: the device must keep its **selection by name** across a rebuild (row numbers do not survive one, and the enriched push lands while a thumb is over GO), and the daemon must decode `B\|A<i>` against the list it actually **pushed** — it re-pushes within ~5 s of the profile set changing, but until then the glass is showing older rows and a fresh `listdir` would decode them to the wrong name. |
| `G\|2` | **BLE gamepad mode.** The device comes up as an ordinary Bluetooth HID gamepad (four buttons, no axes, physical order) and needs no daemon, no Wi-Fi and no loopback from then on — which is the only way a page served over **https** can be driven by this hardware, since it cannot reach `http://127.0.0.1`. Entering parks whichever radio was carrying the link, because the S3 has one 2.4 GHz radio and sharing it costs the link that matters. Reachable from the device itself at **SETTINGS → BLE gamepad** — the verb exists so the mode can also be entered, and tested, from the far end of a cable. Verified on hardware: advertises as `Claude Mate` with service `0x1812`, and `deinit` + Wi-Fi restart round-trips cleanly. **That last part holds only because Wi-Fi is a different stack** — BLE itself does *not* come back after a `deinit` in the same boot (`BLEDevice::init()` fails from then on), so on a device whose *link* is BLE, turning the gamepad off reboots rather than restarting the stack. See `firmware/README.md`. **`G\|2` now also sets the device's stored gamepad switch**, so it survives a reboot exactly as the menu toggle does — and consequently `G\|0` will *not* undo it (see below). |
| `G\|1` `G\|0` | **Controller mode** on / off. Sent by the daemon when a browser page takes or releases the grab on the `--web` bridge (see `daemon/webbridge.py`). While on, the device stops acting on its own buttons, reads the four pins raw and emits press/release **edges** (`B\|+P` …), draws a gamepad face **once** instead of per frame, and drops the backlight to a fraction of its normal duty. That last part is not decoration: a full flush is 110 KB over SPI, and doing it once a second to redraw a screen nobody is looking at — on battery, while the Mac has the buttons — is the overuse the mode exists to avoid. The device leaves on `G\|0`, or on a two-second hold of the 4th button if the Mac never sends one (a crashed tab, a killed daemon). An older firmware ignores `G\|` entirely and simply keeps its menu semantics. **The device can also be a gamepad by itself**, from **SETTINGS → BLE gamepad**, with no daemon involvement at all — so `G\|1` arriving while it is already a controller is a no-op rather than an error, and the daemon must not assume it is the only thing that puts the device there. <br><br>**`G\|0` releases only the mode the daemon opened.** Since the BLE gamepad became a persisted switch rather than an action, "on" is a standing instruction from the person holding the device, and a browser tab closing on the Mac must not revoke it. A device whose own switch is on stays a gamepad through `G\|0`; the two-second hold of the 4th button, or the settings row, is what turns it off. |
| `P` | Ping / keepalive, sent every ~15 s. The Arduino replies with `K` (NOT `H` — `H` means "I rebooted" and triggers a full resend + LED re-arm, which would restart the blink phase every ping). |

> **Adding a downlink verb? These letters are already taken, and not by this
> table.** On the S3, USB serial lines go to the **config console** first —
> `handleConfigLine()` — and only fall through to the protocol handler if it
> declines them. It owns `?`, `W`, `S`, `T`, `I`, `X`, `R`, `Y`, `Z`. A protocol verb
> that collides with one of those is **silently unreachable over USB** while
> working perfectly over TCP, so it survives every test that does not run on a
> cabled device. This is not hypothetical: controller mode first shipped as
> `X|1`, which the console answered with `refusing: send X|WIPE to clear
> config` — one lax compare away from wiping the Wi-Fi credentials and the
> token every time somebody opened the game. `tools/test_controller_mode.py`
> asserts the two sets stay disjoint.

**`F` line fields** — each row is ≤ 21 chars (size-1), drawn top to bottom:

| Field | Description |
|---|---|
| `flags` | Bitfield. **bit0**: invert **row 0** (the name) at ~2.5 Hz (an unacknowledged alert is on screen). **bit1**: FOLLOW mode is on (draw a ► marker by the state row). |
| `sel` | The character column **within `r3`** of the active tab's fleet letter (`-1` = none). The firmware fills a **wide** rectangle (~11 px) **centred** on that letter — a lit block with the letter knocked out. |
| `r0` (name) | Session name. The daemon truncates to the row width and, when two long sibling names collide, disambiguates with a middle squeeze (first 9 + `~` + last 10, e.g. `webapp-ba~ervice-one`). |
| `r1` (state) | `TAG  time` — the 4-char state tag (`ERR`/`WAIT`/`DONE`/`WORK`/`IDLE`) and the time in that state (mm:ss, or h:mm past an hour) — plus the session's **account** right-aligned (≥ 2-space gap, truncated to fit; omitted when unknown). |
| `r2` (meta) | Best-fit `model effort`, plus the **remaining-limit chip** (e.g. `5h82%`) right-aligned (≥ 2-space gap); the model+effort best-fit degrades into the room the chip leaves. Empty for hook-driven sessions with no scraped metadata. |
| `r3` (fleet) | `pos/total ` + one status **letter** per session in the stable (alphabetical) order, **space-separated**: `E` error, `B` waiting (blocked), `W` working, `D` done, `I` idle. An **unacknowledged alert's letter is sent LOWERCASE** — the firmware draws it uppercase but **blinks** it, so you can see which tabs still need acknowledging (they stop blinking as you ack them). When the strip does not fit, it is cut with a trailing `+`. `r3` is the last field (the firmware stops tokenizing at the 6th `\|` and takes the rest verbatim). |

The daemon sends an `F` line whenever the rendered bytes change: immediately on
any state change or button, and ~1/s while a displayed time ticks. Identical
frames are not re-sent (except on handshake).

With no sessions the daemon sends `F|0|-1|MATE|no sessions||`.

#### LED — `V|<kind>`

The daemon owns the LED policy; the firmware just plays the pattern on D8. The
pattern is always the class of the **worst unacknowledged alert** across all
sessions (`ERROR` > `INPUT` > `DONE`), so the LED loops exactly while something
needs the human:

| `<kind>` | When the daemon sends it | Firmware pattern | Repeat |
|---|---|---|---|
| `START`  | A job (re)started, and nothing else needs you. | one long **1 s** blink, then dark. | one-shot |
| `INPUT`  | Worst unacked alert is `waiting` (Claude needs input). | aggressive even blink (~2.8 Hz). | **loops** until `V\|OFF` |
| `ERROR`  | Worst unacked alert is `error`. | super-aggressive fast strobe (~7 Hz). | **loops** until `V\|OFF` |
| `DONE` | Worst unacked alert is `done` (finished turn). | cascade — 4 quick blinks, then a pause. | **loops** until `V\|OFF` |
| `OFF` | No unacknowledged alerts remain. | LED off now. | — |

The daemon (re)sends the loop `<kind>` only when the desired loop *changes*, so
the link is not spammed. As a failsafe the firmware stops any loop **and shows
the LINK LOST screen** if the daemon goes fully silent for ~30 s (it pings `P`
every 15 s and refreshes `F` frames ~1/s, so this only trips when the daemon
has died). `OFF` (alias `STOP`) darkens the LED immediately.

#### Firmware-local screens

Two states the firmware draws on its own (the daemon never sends them):

* **Splash** — booted, no `F` frame yet: `MATE` / `starting...`.
* **LINK LOST** — no serial byte for ~30 s: `NO LINK` / `waiting for daemon`.
  Clears on the next complete parsed line.

#### Press feedback blip

On every accepted button edge the firmware inverts the whole panel for ~80 ms
(SSD1306 `0xA7`/`0xA6`) — instant "the device heard you" feedback with zero
framebuffer cost. Best-effort: the command is only sent while no chunked frame
transfer is open.

### 1b. Arduino → Daemon

The buttons are, left→right, **PREV | GO | NEXT** (plus **ACK** on the
ESP32-S3's 4-button layout). Debounce is ~40 ms immediate-fire (an edge is
accepted and emitted the same tick). PREV/NEXT emit on the **press** edge and
auto-repeat while held (400 ms to start, then one event per 200 ms). GO and ACK
distinguish a short press (emit on release) from a long press (emit once at
500 ms; the release is then swallowed).

| Line  | Meaning |
|---|---|
| `H` | Hello / handshake, sent **once** right after boot/reset. On receiving `H` the daemon **re-sends the full current state** (frame + re-arms the LED loop). |
| `K` | Keepalive ack — the reply to `P`. The daemon ignores it. |
| `B\|P` | **PREV** pressed (D4) — selection one step up the queue. Repeats while held. |
| `B\|N` | **NEXT** pressed (D3) — selection one step down the queue. Repeats while held. |
| `B\|G` | **GO** short press (D2). The firmware just emits `B\|G` on each short press; the **daemon** disambiguates a single press (after ~300 ms) from a double-click. A single press raises the terminal of the session **shown on the glass** (raise only), acknowledging its alert. A **double-click** (two `B\|G` within ~300 ms) toggles **FOLLOW** mode. |
| `B\|K` | **GO** long press (D2, held ≥ ~500 ms) — acknowledge the shown session's alert WITHOUT raising anything. No-op when nothing is unacknowledged. Also sent by a **short press of the ACK button** on a 4-button device: same verb, same effect, no daemon-side distinction. |
| `B\|F` | Toggle **FOLLOW** mode directly. Identical in effect to a GO double-click, but unambiguous: no 300 ms window to race. Turning it ON raises the shown terminal immediately, exactly as the double-click does. No stock firmware emits this today (the 4th button became MIRROR); it is kept because the daemon accepting it costs nothing and a device with a fifth switch would want it. |
| `B\|M` | **MIRROR** — open/close the terminal view for the session on the glass. Now reached from the ACTIONS sheet rather than directly from the 4th button. |
| `B\|C` | **Send "continue"** — type `continue` into the shown session and press Enter. The reason the ACTIONS sheet exists: a session that hit its 5-hour limit or took an API error is waiting for one word, and this is how you say it without turning back to the laptop. Wrapped sessions only — a hook-only session has no PTY to type into. The daemon relays it as `submit continue` on that session's control socket; the wrapper strips control bytes, so this can never become a remote keyboard. |
| `B\|T` | **New terminal** — open one in the shown session's directory and focus it. `open -a Terminal <cwd>`, which both opens and fronts, so no separate raise is needed. |
| `B\|A<i>` | **Switch to saved account `<i>`** — continue the shown conversation on one of the logins you already have. Switching does **not** mean signing in again: each is a profile directory under `~/.claude-accounts` holding its own credentials. `<i>` indexes the `L\|` list the daemon pushed, sorted, so both ends agree which name row 3 was — a drift there would switch you to the wrong account. The daemon sends `switch <name>` to the wrapper, which owns the claude process and so is the only thing that can replace it: it copies the transcript into that profile and re-execs with `--resume`. The name travels as **one argument, spaces and all** — a profile is a directory the user named, and `work 2` is an ordinary name for one. The wrapper answers `err <why>` and **keeps the session running** if it cannot honour the request — already on that account, no such profile, or nothing said yet so there is no transcript to carry. Every reason is checked before claude is asked to exit: a switch that fails after the session is gone costs you the session and gives nothing back. **The refusal goes on the glass**, not just into a log — the daemon holds it across the middle two rows for ~4 s (see `F\|`), because a press that quietly declines is indistinguishable from a button that does not work. Reasons are written to fit two 21-char rows for that reason. A different **organisation** is *not* among them: every account the picker can offer is a login the user installed and authenticated, so the domain difference is announced by the switcher and not used to refuse — a guard that fired on every pair of a real three-account fleet was an outage, not a safeguard. |
| `B\|+P` `B\|-P` `B\|+G` `B\|-G` `B\|+N` `B\|-N` `B\|+M` `B\|-M` | Press / release **edges**, emitted **only in controller mode** (see `G\|` below). Debounce drops to 8 ms and there is no auto-repeat and no deferred tap, because a gamepad is asked a different question than a menu is: not "was it pressed" but "is it held down *this frame*". The ordinary verbs cannot answer it — 40 ms of debounce, then 400 ms before the first repeat, then one event per 200 ms, is a held direction that moves once, stalls for most of a second, then stutters. A daemon that does not know these codes must **ignore** them rather than treat `+` as the verb; acting on both edges would move the selection twice per press. |
| `O\|<KEY>\|<value>` | A device-set **option**. Unknown keys are ignored, so an older daemon and a newer firmware interoperate in both directions — the same rule the `B\|` verbs follow. Currently only `O\|SND\|0` / `O\|SND\|1`: mute or unmute the **macOS** alert sound. It crosses the link because it is the one device setting whose effect happens on the Mac — the device has no speaker, so a mute reached for on the device has to travel. Re-sent on every connect, since the daemon keeps no per-device state to remember it in. |

### 1c. Daemon → Arduino: the MIRROR view

Sent only while the view is open. Rows are pre-rendered and clipped to
**52 columns**, `17` rows, exactly like `F|` — the firmware never decides what
fits.

| Line | Meaning |
|---|---|
| `M\|T\|<title>` | Header: the mirrored session's name and state. |
| `M\|<n>\|<text>` | Row `n` (0-based, `n < 17`). Text is the rest of the line VERBATIM; tabs are expanded, control bytes become spaces, and any literal `\|` is replaced with `¦` so it cannot be mistaken for a field separator. |
| `M\|END` | The full set has landed — draw it. Buffering until `END` means the view updates in ONE flush and never tears mid-refresh. |
| `M\|OFF` | Close the view; the daemon then re-sends the normal `F\|` frame. |

The daemon fetches the rows by sending `screen` to the session's PTY-wrapper
control socket (the same socket used for `focus`). The wrapper replies
length-prefixed — `SCREEN <n>`, then `n` rows, then `ok` — rather than using a
sentinel, because terminal output can contain any line, **including one that is
exactly `ok`**, which would truncate the mirror at an arbitrary point. A wrapper
predating the command answers a bare `ok`, which reads as "no preview".

### 1d. The wireless handshake (TCP and BLE devices)

Before any of the above flows, a wireless device proves it knows the shared
token. **The same three lines on both radios**, in the same order, verified the
same way, against the same token — one handshake to understand, one secret to
provision, one thing to get wrong:

| Direction | Line | Meaning |
|---|---|---|
| daemon → device | `C\|<nonce>` | 32 hex chars, fresh per connection |
| device → daemon | `A\|<mac>` | hex HMAC-SHA256(token, nonce) |
| device → daemon | `A\|NOTOKEN` | *"I have no token configured"* — see below |
| daemon → device | `A\|OK` | authenticated; the protocol above begins |
| daemon → device | `A\|NO` | rejected; the socket closes |

The token never crosses the wire and the nonce is fresh per connection, so a
sniffed handshake is worthless.

`A|NOTOKEN` exists because a device with no token used to simply hang up, which
reached the daemon as `bad handshake None` — indistinguishable from a crash, a
truncated read or a network fault, when the device knew the exact answer all
along. A cleared token is the commonest wireless failure there is (it is what
the setup portal used to cause), so it gets a line of its own and a daemon
message that says what to do about it. A daemon too old to recognise it reports
a rejected token, which is still more use than silence.

### 1d-bis. Enrolment (`E|`, BLE only) {#enrolment}

The handshake above assumes both ends already share a token. Getting one *onto*
a cordless device used to mean a cable it may be nowhere near, or a Wi-Fi access
point and a phone — for a BLE board, over a link that is already connected and
talking. `E|` is the verb that closes that gap.

| Direction | Line | Meaning |
|---|---|---|
| daemon → device | `E\|?` | may I enrol you? |
| device → daemon | `E\|OK` | a human pressed **GO** on the device |
| device → daemon | `E\|NO` | declined, already provisioned, or nobody was there |
| daemon → device | `E\|<token>` | the secret — **only ever after `E\|OK`** |
| device → daemon | `E\|SET` | adopted; challenge me again |

**The device asks its own human**, and that is the whole security argument. It
puts `PAIR?` on its screen and waits up to 45 s for a button; the daemon's side
is *armed*, never on, for three minutes at a time and disarmed by success or by
a refusal. So being in radio range gets an attacker a prompt on a screen they
cannot reach, and nothing else — and `E|<token>` is refused outright unless a
button was pressed in that same connection, because "has no token yet" must
never be permission by itself.

**What it costs**, stated plainly: the token crosses the air once, in the clear,
inside that window. The link is unencrypted by design (see the threat model
above), so this introduces no plaintext that was not already there — but a
sniffer listening at the second you press GO does learn the secret. Pair away
from hostile radio, or use a cable, which the daemon provisions over
automatically and with no window at all.

### 1e. Which pipe carries it

Three, and the bytes above are identical on all of them. Nothing in the protocol
changes with the transport; only who dials whom, and what the idle radio costs.

| | USB | TCP (`--tcp`) | BLE (`--ble`) |
|---|---|---|---|
| Who initiates | the daemon opens the port | the **device** dials the daemon, found over mDNS | the **Mac** scans; the device only advertises |
| Discovery | serial-port glob | `_claudemate._tcp` | the service UUID `c1a0de00-…-0001` |
| Idle cost | none (cabled) | an association held open continuously | **200 ms of advertising, then ~4 s silent**, repeating |
| Handshake | none (physical access is the trust) | §1d | §1d, identical |
| Framing | newline-delimited ASCII | newline-delimited ASCII | newline-delimited ASCII inside GATT writes/notifications — **a notification boundary is not a line boundary**, and both ends reassemble on newlines |

On BLE the device is the **peripheral** and exposes two characteristics, because
a GATT characteristic is not bidirectional: `…-0002` is written by the daemon
(everything in §1a), `…-0003` is notified by the device (everything in §1b).
Status is **never** encoded into the advertising payload — the status originates
on the host and the peripheral is the device, so the only thing it could
advertise about is itself.

**Wi-Fi and BLE are alternatives, never simultaneous:** the ESP32-S3 has one
2.4 GHz radio. Which one is a stored device setting (`claude-mate link`, or
`I|WIFI` / `I|BLE` / `I|P2P` over the cable), not a compile-time choice. `p2p`
is a third value of that same setting: Wi-Fi with the device as the access point
and the Mac as its only client, so the device dials a DHCP lease off its own AP
instead of an mDNS answer off a router. **Nothing above the socket changes** —
same nonce handshake, same frames — which is why the daemon has no notion of P2P
at all. The daemon can
serve both at once — a Nano on a cable, a Wi-Fi board and a BLE board all get
every frame — because on its side they are three transports, not three
protocols.

**Reset note:** opening the USB serial port resets the Nano (~1.5 s). The `H`
handshake plus the daemon re-sending state on `H` is exactly what makes the
display recover correctly after every reconnect. The daemon also forgets its
LED-loop tracker on `H`, so an unacknowledged alert's loop is re-armed after
every replug.

---

## 2. Socket message (hook / PTY wrapper → daemon)

**Transport:** Unix domain socket at `/tmp/claude-mate.sock` (override with
`CLAUDE_MATE_SOCK`).
**Framing:** one **newline-terminated** line per message.

```
<state>|<session_id>|<name>[|<ctrl_sock>|<model>|<effort>|<account>|<limit>]
```

| Field | Description |
|---|---|
| `state` | One of: `working`, `waiting`, `done`, `error` (or `idle`/`end` from the PTY wrapper). |
| `session_id` | The Claude Code session id. **MAY be empty** if not provided. |
| `name` | Basename of `cwd`. |
| `ctrl_sock`  | (PTY wrapper) per-session control socket GO's `focus` connects to. Empty for hooks. |
| `model` | (PTY wrapper) model in use, e.g. `Opus 4.8`. Empty until scraped / for hooks. |
| `effort` | (PTY wrapper) effort level, e.g. `xhigh`. Empty until scraped / for hooks. |
| `account` | (PTY wrapper) account/profile the session runs as, e.g. `work` or `default`. Empty for hooks. |
| `limit` | (PTY wrapper) remaining-limit chip for that account, e.g. `5h82%` (82% of the 5-hour window left) or `wk31%` (31% of the week left) — whichever window is more depleted. Refreshed every `CLAUDE_MATE_USAGE_POLL_S` (default 120 s) from Anthropic's OAuth usage endpoint; empty until the first successful poll / for hooks. |

The hook path sends only the first three fields; the PTY wrapper appends the
control socket, (once scraped) the model + effort, and (once known) the
account + remaining limit. All trailing fields are optional — the daemon
defaults missing ones to empty.

The hook is **fire-and-forget**: it connects with a short timeout, writes one
line, and exits **0** regardless of outcome. If the daemon/socket is down it
**silently no-ops**. The hook must never block or fail a Claude turn.

### The control socket (CLI → daemon) {#the-control-socket}

The same socket carries **commands**, not just session updates, and this is the
whole surface — six verbs. Anything unrecognised is parsed as a session update
above and dropped, so a typo is silent rather than an error.

| Line | Reply | Meaning |
|---|---|---|
| `queue` | JSON | the whole queue, as the device shows it. Also the only liveness check there is |
| `accounts` | JSON | the saved logins and where they live |
| `accounts-refresh` | `ok` | re-read the accounts directory (after something changed it) |
| `press\|<code>` | `ok` | press a device button: `P N G K F M C T`, or `A<n>` to continue on saved account *n* |
| `select\|<n\|name>` | `ok <name>` | point the selection at a row |
| `pair` | `ok` | arm BLE enrolment for the next unprovisioned device |

**The button codes are the device's own**, and deliberately so: `press|G` is
handed to the same `ButtonReader` that handles `B|G` off the wire, so GO cannot
mean one thing to the device and another to the terminal.

There is **no** `status`, `ping` or `version` verb, and **no** delete. A hook in
any of your shells can write to this socket; a hook firing a malformed line
should not be able to remove a login, so `claude-mate accounts rm` does the
deletion in its own process and only asks the daemon to re-read afterwards. The
socket is mode 0600 — owner only.

Starting the daemon is not on here either, for the reason in
[CLI.md](CLI.md#starting-and-stopping-the-daemon): it goes through launchd, or
you get two of them fighting over one socket.

### Wrapper control socket (daemon → wrapper)

The daemon connects to a session's `ctrl_sock` and sends **only one verb**:

* `focus` — raise + un-minimize + activate that session's terminal window.

The wrapper replies in two stages — `go` on receipt (liveness), `ok` after the
window op completed — so consecutive focuses apply in press order. Pre-ack
wrappers close the socket immediately (EOF), degrading to fire-and-forget.
The `collapse` verb still exists in the wrapper for compatibility but the
daemon **never sends it**.

### Hook event → state mapping

| Claude Code hook event | Socket `state` |
|---|---|
| `UserPromptSubmit` | `working` |
| `Notification` | `waiting` |
| `Stop` | `done` — or `working`, see below |
| `StopFailure` | `error` |

> **A `Stop` with work still in flight reports `working`, not `done`.** The
> `Stop` payload carries `background_tasks[]` (background work that is running
> or pending: dynamic workflows, background agents, backgrounded shells,
> monitors, MCP tasks) and `session_crons[]` (scheduled tasks that will wake the
> session later). Each `background_tasks[]` entry carries its own `status`
> (`running`, `pending`, …); entries in a **terminal** status are already over
> and are not counted, because the later `Stop` that would correct the downgrade
> may never arrive. An entry with no `status` at all *is* counted, so a build
> that omits the field behaves as before. When in-flight work remains — or a
> cron is a **one-shot** wakeup (`recurring: false`), i.e. this turn continuing later —
> the hook reports `working`, and the finish is reported by the next `Stop` that
> lands with nothing in flight. Recurring crons are not counted: a session that
> merely owns a daily schedule is finished for now, and suppressing its DONE
> forever would hide it from the device. Both fields are optional, so a Claude
> Code build that omits them behaves exactly as before.

> **No `SessionEnd` hook is installed.** The daemon's `idle` state is **not**
> driven by any socket message — it is reached purely via the
> done-until-acknowledged model and TTL pruning (see §3).

---

## 3. Session state model (kept by the daemon)

The daemon keeps a dictionary of sessions, **keyed by `session_id`** (or by
`name` when the id is empty).

### Per-session fields

| Field | Description |
|---|---|
| `name` | cwd basename. |
| `state` | Current state (see below). |
| `sid` | Session id (`session_id`). |
| `cwd` | Working directory, if known (used by the FOCUS fallback). |
| `last_update_ts` | Timestamp of the last update for this session. |
| `state_since` | When the current state began — the displayed time is always *time in state* (for `working` that IS the live turn runtime; for an alert it is how long it has been waiting on the human). |
| `model`/`effort` | Best-effort strings scraped by the PTY wrapper. |
| `account`/`limit`| The account the session runs as + its remaining-limit chip (PTY wrapper; sticky once seen). |
| `focus_ctrl` | The wrapper control socket path, if any. |
| `acked` | Has the human seen this alert? |

### States

| State | Entered when |
|---|---|
| `working` | `UserPromptSubmit` fired — a turn is in progress. Also a turn that **ended with background work still in flight** (hook: `Stop` + `background_tasks`; PTY wrapper: the background-work tells on screen). |
| `waiting` | `Notification` fired — needs permission / Claude asked something. |
| `error` | `StopFailure` fired — turn ended on an API error (5xx / overloaded / timeout). |
| `done` | `Stop` fired — turn completed OK. Also `working` → `idle` becomes `done` (finished but not yet acknowledged) and STAYS `done` until acknowledged. |
| `idle` | Acknowledging a `done` session, or inactivity/TTL pruning. **No hook/socket message sets `idle` directly into the model.** |

### Tab order (stable) vs. urgency (separate)

The display / navigation order is **stable — alphabetical by name** (then the
session key as a deterministic tiebreak). Tabs keep their position as their
states change; they never shuffle under the user.

**Urgency** is computed separately and drives only two things, never the tab
order:

```
worst UNACKNOWLEDGED alert  (error > waiting > done, oldest first)
```

* the **LED** loop class, and
* which **fleet letters blink** (unacked alerts are sent lowercase).

It never moves the selection: the shown tab is sticky.

### Ack lifecycle

An alert is born on the transition into `error`/`waiting`/`done`. It dies in
exactly four ways — nothing else removes one, so none can be lost silently:

1. **`B|G` GO** — acknowledged + the window raised.
2. **`B|K` ACK** — acknowledged, no window op.
3. **Auto-resolve** — the session leaves the alert class on its own (the user
   answered in the terminal → `working`; a new turn started).
4. **TTL prune** — `done` sessions drop after 120 s without updates; anything
   drops after 600 s.

Acknowledging a `done` session turns it `idle`. **Flap suppression:** a session
re-entering the SAME alert class within 5 s of being acknowledged stays
acknowledged (a bouncing detector cannot re-fire the LED the user just
silenced).
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

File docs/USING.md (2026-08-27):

# Claude Mate — the manual, 0 → hero

Read it in order and you go from an empty machine to a working desk companion.
Every section stands alone if you already have the one before it.

**1.** [Install](#install-one-command) — one command · **2.** [The daemon](#the-daemon)
— what it is · **3.** [The CLI](#the-cli) — every command · **4.**
[The device](#the-device) — every button · **5.** [Connect one](#connecting-a-device)
· **6.** [When it is wrong](#when-something-is-wrong)
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

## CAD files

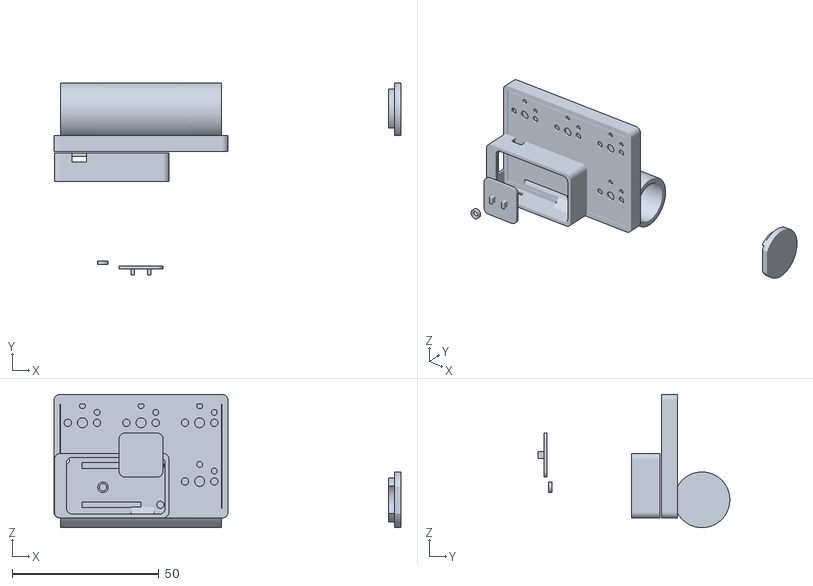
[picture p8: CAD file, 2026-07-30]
assets/3d-model/claude_mate_s3.stl
118.4 x 65.4 x 45.5

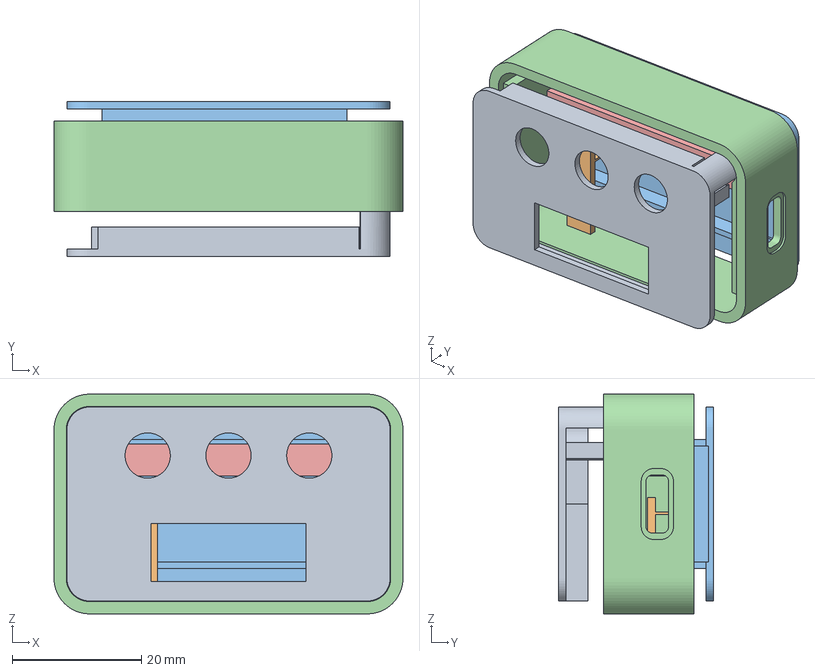
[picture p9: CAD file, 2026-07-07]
assets/3d-model/claude_mate_v2.3mf
54.0 x 24.0 x 34.0 mm

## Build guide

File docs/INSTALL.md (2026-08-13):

# Claude Mate — Install

## The short version

```sh
git clone https://github.com/vlgutv22/claude_mate.git && cd claude_mate
./install/install.sh --yes
```

Steps 2, 3 and 4 below are what that does: it installs the status hook, merges
the hooks block into `~/.claude/settings.json` (backing it up first), installs
and starts the **LaunchAgent** so the daemon runs at login, and puts
`claude-mate`, `claude-mate-connect` and `claude-mate-switch` on your `PATH`.
Drop `--yes` and it asks before editing `settings.json`, which is the only
question it has. It is idempotent — re-run it after a `git pull`.

Then alias `claude` to the PTY wrapper (this is what gets model, effort, account
and remaining limit onto the screen):

```sh
echo 'alias claude="'"$PWD"'/bin/claude-mate-wrap"' >> ~/.zshrc && exec zsh
```

**You do not need hardware.** `claude-mate` in a terminal is the same interface
as the device — see [USING.md](USING.md), which is the manual for both.

Undo it all with `./install/uninstall.sh`.

The rest of this page is the **manual** route, and the firmware. Read it if you
are flashing a board, or if you want to know exactly what the installer touched.

---

## Prerequisites

A Mac, **Python 3.9+**, and — only if you are building hardware — `arduino-cli`
or the Arduino IDE plus your assembled device ([WIRING.md](WIRING.md)).

Python dependencies, all optional in the sense that the daemon degrades rather
than fails without them: **pyserial** (a USB device), **pyte** (the terminal
mirror and the PTY wrapper's state scraping), **bleak** (the BLE transport).

Put the project wherever you like — this guide refers to its root as `$REPO`
(e.g. `~/src/claude_mate`).

> **Two devices, and this page's step 1 is the Nano.** For the **ESP32-S3** —
> the cordless colour build — flashing is `./firmware/flash_s3.sh` and is
> documented in [`firmware/README.md`](../firmware/README.md), because
> `arduino-cli upload` cannot flash that board and the reasons are specific.
> Provisioning it needs nothing typed: plug it in and the daemon hands it a
> token, or run `claude-mate-connect --pair` and press GO.

---

## 1. Flash the firmware (Arduino IDE)

1. Open the firmware sketch in the **Arduino IDE** (under `$REPO/firmware/`).
2. **Tools → Board →** Arduino Nano. **Tools → Processor →** ATmega328P (try
   "ATmega328P (Old Bootloader)" if uploads fail).
3. **Tools → Port →** select the Nano's port (a `/dev/cu.usbserial*` or
   `/dev/cu.usbmodem*` device).
4. Install the **one required library** via **Sketch → Include Library → Manage
   Libraries…**:
   - **Adafruit GFX Library** — graphics primitives, and the only external
     dependency. The panel itself is driven by the bundled
     [`softssd1306.h`](../firmware/claude_mate/softssd1306.h), a software-I2C
     `Adafruit_GFX` subclass that puts SCL on **A3** (hardware SCL A5 was
     damaged) and leaves SDA on A4. **Adafruit SSD1306 and Adafruit BusIO are
     not needed** — CI compiles this sketch with Adafruit GFX alone.
   - If you have a **1.3" SH1106** panel instead, you will need its own driver
     (**Adafruit SH1106 / U8g2**) and a matching edit to the sketch — see the
     SSD1306-vs-SH1106 note in [WIRING.md](WIRING.md).
5. Confirm the I2C address in the sketch is **0x3C** (change to **0x3D** if your
   panel uses the alternate address).
6. **Upload**. After upload, the board resets and emits `H` on boot.

> If you installed the **10 µF RESET→GND cap** from the WIRING caveat, **remove
> it before uploading** — it blocks the bootloader — then re-install it.

**Smoke test:** open the IDE **Serial Monitor** at **115200 baud**. You should
see `H` shortly after a reset. (See [TESTING.md](TESTING.md) for the full
ladder.) Then **close the Serial Monitor** — it holds the port and the daemon
cannot open it at the same time.

---

## 2. Run the daemon

The daemon needs Python 3.9+ and pyserial:

```sh
python3 -m pip install --user pyserial
```

Run it directly:

```sh
python3 $REPO/daemon/claude_mate_daemon.py
```

It auto-detects the serial port (`/dev/cu.usbserial*` then `/dev/cu.usbmodem*`),
opens it once, and keeps it open. Leave it running.

**Optional environment variables** (sane defaults shown):

| Variable | Default | Meaning |
|---|---|---|
| `CLAUDE_MATE_PORT` | autodetect | Serial device path (skip autodetect). |
| `CLAUDE_MATE_SOCK` | `/tmp/claude-mate.sock` | Unix socket the hook writes to. |
| `CLAUDE_MATE_BAUD` | `115200` | Serial baud rate. |

**Mock mode (no hardware needed for the display logic, no Claude needed):**

```sh
python3 $REPO/daemon/claude_mate_daemon.py --mock
```

`--mock` injects a few fake sessions that cycle through states so you can demo
the OLED card, the status word + vibration haptic, and the carousel without
Claude or hooks.

---

## 3. Merge the hooks snippet

The hook script is **fire-and-forget** and always exits 0, so it can never block
or break a Claude turn.

1. Make sure the hook script is installed and executable at the path Claude Code
   expects:

   ```sh
   mkdir -p ~/.claude/hooks
   cp $REPO/hooks/claude-status.sh ~/.claude/hooks/claude-status.sh
   chmod +x ~/.claude/hooks/claude-status.sh
   ```

2. Merge the hooks block into your Claude Code settings. Settings live at
   (VERIFIED FACTS):
   - **User:** `~/.claude/settings.json`
   - **Project:** `.claude/settings.json`
   - **Local:** `.claude/settings.local.json`

   Add (merge into any existing `"hooks"` object) the events Claude Mate cares
   about — `UserPromptSubmit`, `Notification`, `Stop`, and `StopFailure` — each
   pointing at the script with the matching state as its argument. The canonical
   snippet ships at `$REPO/hooks/settings.snippet.json` and is exactly what
   `install/install.sh` merges; merge its `hooks` object, which looks like:

   ```json
   {
     "hooks": {
       "claudeMateWorking": {
         "type": "shell",
         "events": ["UserPromptSubmit"],
         "command": "~/.claude/hooks/claude-status.sh working"
       },
       "claudeMateWaiting": {
         "type": "shell",
         "events": ["Notification"],
         "command": "~/.claude/hooks/claude-status.sh waiting"
       },
       "claudeMateDone": {
         "type": "shell",
         "events": ["Stop"],
         "command": "~/.claude/hooks/claude-status.sh done"
       },
       "claudeMateError": {
         "type": "shell",
         "events": ["StopFailure"],
         "command": "~/.claude/hooks/claude-status.sh error"
       }
     }
   }
   ```

   (Hooks-block shape per VERIFIED FACTS: each hook has `type`, `events`,
   `command`. `StopFailure` is a distinct event that fires instead of `Stop` on
   API errors; its `claudeMateError` entry is optional and can be omitted on
   builds without `StopFailure`.) There is **no `SessionEnd` hook**: the daemon's
   `idle` state is derived purely from inactivity (TTL pruning), not from a hook
   event — see [PROTOCOL.md](PROTOCOL.md).

3. Restart / reload Claude Code (or start a new session) so it picks up the
   hooks. With the daemon running, submitting a prompt should show the word
   **WIP** (working) and a card; a `Notification` switches it to **BLOCKED** (and
   the motor gives a gentle per-session buzz as sessions start/wait/finish/error), etc.

---

## 4. Install the LaunchAgent (auto-start)

To keep the daemon running and restart it on login/crash, install the macOS
**LaunchAgent**.

The simplest path is to run the installer, which templates the plist (filling in
your repo path, `python3`, and `$HOME`) and loads it for you:

```sh
$REPO/install/install.sh
```

To do it by hand instead, copy and load the plist (note the label has **no
hyphen** between "claude" and "mate"):

```sh
cp $REPO/install/com.claudemate.daemon.plist \
   ~/Library/LaunchAgents/com.claudemate.daemon.plist

launchctl load ~/Library/LaunchAgents/com.claudemate.daemon.plist
```

To stop / unload it:

```sh
launchctl unload ~/Library/LaunchAgents/com.claudemate.daemon.plist
```

The LaunchAgent runs the same `daemon/claude_mate_daemon.py`. The daemon tolerates
the device being absent at launch and auto-reconnects when you plug the Nano in,
so it is safe to keep loaded all the time.

> **Port conflict reminder:** only one program can hold the serial port. If the
> Arduino IDE **Serial Monitor** is open, the daemon (or LaunchAgent) cannot open
> the port — and vice versa. Close one before starting the other.

---

## Verifying the install

Follow [TESTING.md](TESTING.md) from the bottom up: confirm the port appears in
`ls /dev/cu.*`, run the selftest, poke the protocol by hand, run the daemon in
`--mock`, feed a fake hook line, and finally exercise real Claude hooks.

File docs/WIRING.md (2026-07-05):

# Claude Mate — Wiring

Target board: **Arduino Nano (ATmega328P)**, 5 V logic.

All grounds are common. The OLED runs on 5 V over I2C. The three buttons use the
internal pull-ups (`INPUT_PULLUP`) so they need no external resistors. The
**OLED** shows the single triage frame (session name + info row + fleet strip);
the **indication LED on D8** is the alert output, driven by the daemon via
`V|<kind>`.

---

## The display + indication LED

The OLED is the **sole visual status**: one pre-rendered frame of four size-1
rows — session name (flashing while its alert is unacknowledged), state + time,
model + effort, and a position + fleet-letter strip. The daemon composes it and
sends it; the Arduino renders it.

The **indication LED on D8** is the alert output. Alerts are driven by the
daemon via `V|<kind>` for the worst unacknowledged alert class. Because the
output is a light, each state has its own glanceable blink rhythm and every
"act now" state blinks until you acknowledge it (GO, or hold GO):

| `V|` kind | LED pattern | Repeat |
|---|---|---|
| `START` | one long 1 s blink, then dark | one-shot |
| `INPUT` | aggressive even blink (~2.8 Hz) | **loops** until `V|OFF` |
| `ERROR` | super-aggressive fast strobe (~7 Hz) | **loops** until `V|OFF` |
| `DONE` | cascade — 4 quick blinks, then a pause | **loops** until `V|OFF` |
| `OFF` | LED off | sent on acknowledge / clear |

There is no wheel, no dial, no motor — those are gone. See
[PROTOCOL.md](PROTOCOL.md) for the exact contract.

---

## Pin map

| Function | Nano pin | Notes |
|---|---|---|
| OLED VCC | 5V | SSD1306 0.91" 128x32, I2C (module pin order: GND/VCC/SCK/SDA) |
| OLED GND | GND | common ground |
| OLED SDA | **A4** | I2C data |
| OLED SCL | **A3** | I2C clock — **software (bit-banged) I2C** (hardware SCL A5 was damaged; the 328P's TWI is fixed to A4/A5 and can't be remapped, so SCL moved to the plain GPIO A3). See `firmware/claude_mate/softssd1306.h`. |
| GO button | **D2** | `INPUT_PULLUP`; other leg to GND |
| NEXT button | **D3** | `INPUT_PULLUP`; other leg to GND |
| PREV button | **D4** | `INPUT_PULLUP`; other leg to GND |
| Indication LED | **D8** | LED + **~220 Ω–1 kΩ series resistor** to GND. Blinks the alert pattern; the sole alert output. |

> There are **no motor pins**, **no stepper pins**, and **no traffic-light LED
> pins** — the vibration motor (old D5) and the stepper status wheel are gone.
> D4 is the PREV button.

### Buttons

Layout left→right is **PREV | GO | NEXT**. Each button connects its
**D2 / D3 / D4 pin to one leg** and **GND to the other leg**. With `INPUT_PULLUP`,
an unpressed button reads **HIGH** and a pressed button reads **LOW**. The
firmware debounces presses (~40 ms — snappy) and emits:

- **D2 = GO** → `B|G` on a **short** press (acknowledge + raise the shown
  session's window) and `B|K` on a **long** press ≥ ~500 ms (acknowledge only).
- **D3 = NEXT** → `B|N` on press (selection down the queue; auto-repeats ~5/s
  while held).
- **D4 = PREV** → `B|P` on press (selection up the queue; auto-repeats ~5/s
  while held).

---

## Power note

Everything runs off the **USB 5 V rail** — the OLED and the LED draw only a few
tens of mA combined. Tie all grounds common and always use the series resistor
on the LED so the pin isn't over-driven. No separate supply, no homing, no
endstop.

---

## ASCII wiring overview

```
        Arduino Nano (ATmega328P)
        +-----------------------+
   5V --| 5V              A4(SDA)|---- OLED SDA
  GND --| GND             A3(SCL)|---- OLED SCL  (software I2C; A5 was damaged)
        |                       |
        |                    D2 |---- GO     button -- GND   (INPUT_PULLUP)
        |                    D3 |---- NEXT   button -- GND   (INPUT_PULLUP)
        |                    D4 |---- PREV   button -- GND   (INPUT_PULLUP)
        |                       |
        |                    D8 |---- LED +anode, -cathode -> [~220-1k R] -> GND
        +-----------------------+

  OLED module: VCC->5V, GND->GND, SDA->A4, SCL->A3   (software I2C, addr 0x3C)
  Indication LED on D8 blinks the alert pattern for the worst unacknowledged
  alert (V|<kind>); always use a series resistor so the pin isn't over-driven.
```

---

## Bill of materials (BOM)

| Qty | Part | Notes |
|-----|---|---|
| 1 | Arduino Nano (ATmega328P) | 5 V; USB CDC serial |
| 1 | I2C OLED 0.91" 128x32 — SSD1306 | 4-pin GND/VCC/SCK(SCL)/SDA |
| 3 | Momentary push buttons (tactile) | PREV + GO + NEXT |
| 1 | Indication LED + ~220 Ω–1 kΩ resistor | on D8; blinks the alert pattern |
| — | Breadboard / perfboard + jumper wires | assembly |
| 1 | USB cable (to the Mac) | data-capable, not charge-only |

> The **stepper, ULN2003 driver, endstop microswitch, dial/wheel, old 3 LEDs,
> and the vibration motor + its driver are all gone** — the indication LED on
> D8 is the only alert output.

---

## Notes and caveats

### I2C address: 0x3C (alt 0x3D)

The default I2C address used by the firmware is **0x3C**, which is by far the
most common for these 128x32 modules. Some boards are strapped to **0x3D** (the
common alternative). If the screen stays blank, try 0x3D — many modules have a
solder jumper labeled `0x78 / 0x7A` (the 8-bit forms of 0x3C / 0x3D). Change the
address constant in the firmware to match.

### SSD1306 vs SH1106 (1.3" panels)

The pin map and I2C address are identical, but the **controller chip differs**:

- **0.91" 128x32** (this build's default) and **0.96" 128x64** modules are almost always **SSD1306**.
- **1.3" 128x64** modules are often **SH1106**, not SSD1306.

The SH1106 has a slightly different internal column offset (its RAM is 132 px
wide vs the 128 px panel), so driving an SH1106 with an SSD1306 driver typically
produces a **2-pixel horizontal shift and/or garbage at the edges**. If you use a
1.3" panel, select the **SH1106** driver/library instead of the SSD1306 one.
Everything else (wiring, address, protocol) is unchanged.

### Serial reset / 10 µF cap caveat

On the Nano, **DTR toggling from opening the USB serial port pulses RESET**, so
the board reboots (~1.5 s) every time the daemon opens the port. This is by
design and is exactly why the firmware emits **`H` on boot** and the daemon
**re-sends full state on `H`** — the display self-heals after each reconnect.

If you specifically want to **prevent** the auto-reset (for example, to keep the
display from blanking when the daemon reconnects), you can place a **10 µF
electrolytic capacitor between the RESET pin and GND** (observe polarity:
negative leg to GND). This holds RESET steady through the DTR pulse.

Important: that same cap will **block normal sketch uploads**, because uploading
*relies* on the auto-reset to enter the bootloader. **Remove the 10 µF cap
before flashing new firmware, then re-install it afterward.** For most users the
default behavior (no cap, rely on the `H` handshake) is the right choice.

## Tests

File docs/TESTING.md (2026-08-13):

# Claude Mate — Testing

Test **bottom-up**. Each rung isolates one layer so that when something breaks,
you know exactly where. Start at level 0 and only move up once the current rung
passes.

```
(5) real Claude hooks        <- highest: end-to-end with Claude Code
(4) tools/feed.sh fake hook
(3) daemon --mock
(2) serial protocol by hand
(1) selftest sketch
(0) port shows up            <- lowest: is the device even there?
```

> **The one gotcha that bites everyone — port is exclusive.**
> The Arduino IDE **Serial Monitor** and the **daemon** cannot both hold the
> serial port at the same time. Level 2 uses the Serial Monitor; levels 3–5 use
> the daemon. **Close the Serial Monitor before running the daemon, and stop the
> daemon (or its LaunchAgent) before opening the Serial Monitor.** A "port busy" /
> "resource busy" / "could not open port" error almost always means the other one
> still has it.

---

> **Which device?** The ladder below is written for the Arduino Nano, the
> reference implementation. It applies unchanged to the ESP32-S3 except that you
> flash with [`firmware/flash_s3.sh`](../firmware/flash_s3.sh) rather than
> `arduino-cli upload` (that board needs three separate workarounds — see
> [`firmware/README.md`](../firmware/README.md)), and there is a fourth button.
>
> **The automated tests drive the daemon over a serial PTY, so the S3's TCP
> transport is the one path they do not cover.** A regression that only appears
> over Wi-Fi is possible and has happened: the terminal mirror first shipped
> sending rows that were correct over the wire but empty of content, which the
> serial-based suite could not have caught. When touching the wireless path,
> test against hardware — or against a throwaway client that performs the
> nonce/HMAC handshake and speaks the protocol directly.

## Level −1 — Automated tests (no hardware, no Claude)

Self-contained tests exercise the Mac side before you touch any hardware
(`tools/test_*.py` — CI runs the whole glob):

```sh
pip install pyserial                  # one-time, for the e2e test

python3 tools/test_e2e.py             # fake Arduino over a PTY + a fake PTY-wrapper
                                      # ctrl socket: drives real hook lines through
                                      # the socket, presses fake buttons (B|P/N/G/K),
                                      # and asserts ~30 checks — the
                                      # F|flash|r0|r1|r2|r3 frame protocol (four
                                      # size-1 rows + the packed letter fleet
                                      # strip), the V|<KIND> LED lines (incl.
                                      # handshake re-arm), the PREV/NEXT queue walk,
                                      # the GO/ACK triage sweep (GO focuses exactly
                                      # the shown session — WYSIWYG — then snaps to
                                      # the next alert; B|K acks without focusing;
                                      # last ack -> V|OFF), sibling-name
                                      # disambiguation, and the window-op invariants
                                      # (navigation sends ZERO window ops; GO sends
                                      # exactly one 'focus'; 'collapse' is never
                                      # sent), plus the MIRROR view (B|M opens it,
                                      # the tail of a taller screen is shown, a
                                      # blank gap is collapsed rather than
                                      # windowed into, PREV scrolls WITHOUT moving
                                      # the selection, and mirroring a terminal
                                      # never raises it). Nothing is launched on
                                      # your Mac: open/code/osascript are stubbed.

python3 tools/test_settings_merge.py  # proves the installer's settings.json merge
                                      # preserves your existing config and is idempotent

python3 tools/test_detect.py          # the wrapper's screen scrape: which rendered
                                      # TUI frames read working/waiting/error/idle —
                                      # incl. the background-work tells that must
                                      # NOT read idle while work is in flight, and
                                      # must STOP reading working once it finishes
                                      # (real captured frames) (needs pyte)

python3 tools/test_hook_state.py      # the hook's wire line per Stop payload —
                                      # incl. "the turn ended but work is still in
                                      # flight" reporting working instead of done

python3 tools/test_controller_mode.py # what --web puts on the DEVICE link: G|1 when
                                      # a page takes the grab, G|0 on release (incl.
                                      # a crashed tab), and a re-assert on every
                                      # handshake so a device that connects mid-game
                                      # is told too. Ends with a STATIC check that
                                      # handleLine and handleConfigLine claim
                                      # disjoint verbs — the config console sees USB
                                      # lines first, so a collision is silently
                                      # unreachable over USB, which is exactly how
                                      # the first attempt at this verb (X|, already
                                      # X|WIPE) failed. Read it before adding one.

python3 tools/test_ble_link.py        # the BLE transport, both halves. Starts with
                                      # the CONTRACT — the service and characteristic
                                      # UUIDs live in two files, in two languages, and
                                      # a typo in one makes the device advertise
                                      # forever while the daemon scans forever, with
                                      # nothing on either side saying so. Then drives
                                      # the real BleLink against a FAKE bleak (a stub
                                      # module injected before the lazy import): the
                                      # nonce/HMAC handshake and both ways of failing
                                      # it, line reassembly (a notification boundary
                                      # is NOT a line boundary), and that handshake
                                      # lines never leak up to the dispatcher. Needs
                                      # no radio and no bleak install. Ends with
                                      # static checks that the firmware has ONE
                                      # gamepad row, that it is persisted, and that
                                      # I| landed on the config side of the verb split
```

Each prints a `PASS`/`FAIL` checklist and exits non-zero on failure, so they
double as CI smoke tests. They never touch your real `~/.claude`, the daemon
socket, or serial ports.

---

## Level 0 — Port shows up

Plug the Nano into the Mac, then:

```sh
ls /dev/cu.*
```

You should see a `/dev/cu.usbserial*` or `/dev/cu.usbmodem*` entry. That is the
device the daemon will auto-detect.

- **Nothing appears?** Try another (data-capable) USB cable, another port, and
  confirm the board has power. Some clone Nanos need the **CH340** USB-serial
  driver installed on macOS.

Pass criterion: a `cu.*` device appears (and disappears when you unplug).

---

## Level 1 — Selftest sketch

Confirm the **hardware** works independently of the protocol. Flash the selftest
sketch (`firmware/selftest/selftest.ino`) and watch the board. On boot it now:

- **Cycles a 4-row demo frame** (name / state+time / model+effort /
  position+fleet letters — the selftest predates the account/limit chips) through `ERR → WAIT → DONE → WORK → IDLE` on the OLED
  every ~3 s in the real interface layout, printing each one over serial, and
  **plays the matching LED pattern on D8** on each change (ERROR strobe, INPUT
  blink, DONE cascade, START one-shot, dark on IDLE) → display + LED OK.
- The **OLED** lights up and shows the frame (the alert name row flashing) → software
  I2C (SDA A4 / SCL A3) + display OK (if blank, try address **0x3D**; if it's
  a 1.3" panel, you may need the **SH1106** driver — see [WIRING.md](WIRING.md)).
- Pressing **GO (D2)**, **NEXT (D3)**, and **PREV (D4)** is printed over serial
  → buttons OK. (The standalone selftest uses simple press events; the
  long-press / auto-repeat behavior lives in the real firmware, Level 2.)

This validates OLED + indication LED + buttons with **no Mac software**.

Pass criterion: the OLED cycles the demo frames in the real interface layout
(four size-1 rows — name / state+time / model+effort / position+fleet letters,
the alert name row flashing), the D8 LED
plays the matching pattern on each change (ERROR strobe / INPUT blink / DONE
cascade / START one-shot / dark on IDLE), and all three buttons print their
press lines (GO D2 / NEXT D3 / PREV D4).

---

## Level 2 — Serial protocol by hand (Arduino Serial Monitor)

Flash the **real firmware**. Open the Arduino IDE **Serial Monitor** at
**115200 baud**, line ending **Newline (`\n`)**.

1. On connect/reset you should see the board emit:

   ```
   H
   ```

2. Now **send** lines by hand and watch the display. Send a full frame
   (`F|<flags>|<sel>|<r0>|<r1>|<r2>|<r3>`):

   ```
   F|1|4|api-server|WAIT  0:42       work|Opus 4.8 xhigh  5h82%|1/3 B W D
   ```

   → the OLED shows the frame as four size-1 rows: the name `api-server` on r0
   **flashing** (`flags` bit0 = 1), the state + time (+ the account,
   right-aligned) on r1, the model + effort (+ the remaining-limit chip)
   on r2, and the position + space-separated fleet letters on r3 with the
   letter at column `4` (the `B`) in a **wide centred filled rectangle** (a lit
   block, letter knocked out). Add bit1 to `flags` (send `3` instead of `1`)
   and a ► FOLLOW marker appears by the state row; send `flags` `0` and the
   flashing stops. Send a letter lowercase (e.g. `1/3 b W D`) and it blinks
   (an unacked alert).

   Blink the LED with `V|<kind>` and watch each pattern:

   ```
   V|START     one long 1 s blink, then dark (one-shot)
   V|INPUT     aggressive even blink (~2.8 Hz) that LOOPS — V|OFF stops it
   V|ERROR     fast strobe (~7 Hz) that LOOPS — V|OFF stops it
   V|DONE      4-blink cascade + pause that LOOPS — V|OFF stops it
   V|OFF       stops any looping/playing pattern immediately
   ```

   Confirm the loops keep repeating until you send `V|OFF`, and that with no
   serial at all a loop self-stops after ~30 s **and the display switches to
   the LINK LOST screen** (the daemon-silence watchdog); any typed line brings
   the frame back.

3. Send a ping:

   ```
   P
   ```

   → the board replies `K` (the keepalive ack; `H` is sent only on boot/reset).

4. Press the physical buttons and confirm the Serial Monitor prints:

   ```
   B|G     ← GO (D2), short press
   B|K     ← GO (D2), held ≥ ~0.5 s (long press)
   B|N     ← NEXT (D3); repeats ~5/s while held
   B|P     ← PREV (D4); repeats ~5/s while held
   ```

   Also confirm the panel does a quick ~80 ms invert blip on every press.

Pass criterion: `H` on boot, `F|` frames render (flash flag flashes the name
row), the LED patterns (`V|`, incl. the looping kinds stopped by `V|OFF`)
play from typed lines, LINK LOST appears after ~30 s of silence, buttons emit
`B|G`/`B|K`/`B|N`/`B|P` with auto-repeat on held PREV/NEXT.

> When done, **close the Serial Monitor** so the daemon can use the port.

---

## Level 3 — Daemon in mock mode

Run the daemon with fake sessions — no Claude, no hooks needed:

```sh
python3 $REPO/daemon/claude_mate_daemon.py --mock
```

`--mock` injects a few fake sessions that cycle through states (including a
`waiting` session, so all four words appear). Watch the real hardware:

- The **screen** stays on the tab you selected (it starts on the first tab
  and NEVER switches on its own); the shown session's name row **flashes**
  while its own alert is unacknowledged. Alerts on other tabs show as
  **blinking fleet letters** in the strip — the tab **order** stays
  alphabetical and never shuffles.
- The **LED** plays the pattern of the worst unacked class (`V|ERROR` strobe >
  `V|INPUT` blink > `V|DONE` cascade), looping until acknowledged; a calm
  `V|START` blink fires when a session starts working with nothing else pending.
- Press **NEXT** / **PREV** → the selection steps down/up the stable
  (alphabetical) order (wraps); the screen then stays where you put it —
  indefinitely.
- Press **GO** → the daemon acknowledges the session **shown on the glass**
  (WYSIWYG) and attempts to raise its window (in mock, watch the daemon log for
  the focus call); the display **stays on that tab** (no auto-switch).
- **Hold GO** (~0.5 s) → acknowledges WITHOUT any window op; the flashing and
  the LED loop stop, and the display stays on the tab. (Any remaining unacked
  alerts keep blinking their fleet letters and driving the LED — the view
  doesn't move.)
- **Double-click GO** → toggles FOLLOW mode (a ► marker appears); PREV/NEXT
  then also raise the selected terminal after it settles.

Also confirm robustness: **unplug** the Nano mid-run — the daemon should not
crash — then **replug**; it should reconnect and (via the `H` handshake) restore
the frame AND re-arm any active LED loop.

Pass criterion: queue-ordered display + correct LED class + buttons handled +
survives an unplug/replug.

---

## Level 4 — Fake hook line via tools/feed.sh

Now test the **socket → daemon** path without Claude. Run the daemon **without**
`--mock` (so it listens on the socket), then feed it a fake hook line:

```sh
python3 $REPO/daemon/claude_mate_daemon.py    # in one terminal

$REPO/tools/feed.sh working abc123 demo        # in another
```

`tools/feed.sh` writes one newline-terminated line to `/tmp/claude-mate.sock` in
the socket format `<state>|<session_id>|<name>` (here:
`working|abc123|demo`). Try each state — `working`, `waiting`, `done`, `error` —
and watch the frame and the LED update accordingly:

- `error` → `ERR` frame, name row flashing + a looping `V|ERROR` strobe
  (until you GO / hold GO / it clears).
- `waiting` → `WAIT` frame, flashing + a looping `V|INPUT` blink.
- `done` → `DONE` frame, flashing + a looping `V|DONE` cascade.
- `working` (nothing else pending) → `WORK` frame, steady + one-shot `V|START`.

Pass criterion: feeding socket lines drives the frame + LED per
[PROTOCOL.md](PROTOCOL.md).

---

## Level 5 — Real Claude hooks (last)

Finally, exercise the whole pipeline with Claude Code. With the daemon running
and the hooks merged (see [INSTALL.md](INSTALL.md)):

1. Open a Claude Code session (VS Code extension or CLI) and **submit a prompt**
   (`UserPromptSubmit`) → a `WORK` frame appears and a one-shot `V|START`
   blink fires (if nothing else needs you).
2. Trigger a **Notification** (e.g. a permission prompt) → the `V|INPUT`
   blink **loops** and that session's fleet letter blinks until you navigate
   to it and GO / hold GO / answer in the terminal (shown, its `WAIT` frame
   flashes; the screen does not jump there on its own).
3. Let a turn **complete** (`Stop`) → a flashing `DONE` frame and a `V|DONE`
   cascade that **loops** until acknowledged.
4. Cause an **API error** (`StopFailure`) → a flashing `ERR` frame and a
   `V|ERROR` strobe that **loops** until acknowledged. (`StopFailure` fires
   instead of `Stop` on API errors — they never both fire.)
5. Open multiple sessions and confirm the fleet strip on the bottom row shows
   one letter per session in a stable alphabetical order (unacked alerts
   blink lowercase→uppercase), and that the shown tab never changes on its
   own.
6. Press **GO** on a shown session → its terminal window is **raised** (wrapper
   sessions) or VS Code focuses via the deep link / workspace fallback (see
   the focus Limitations in [ARCHITECTURE.md](ARCHITECTURE.md)). Confirm
   navigation with **NEXT**/**PREV** moves NO windows — ever.
7. End a session → it disappears; with zero sessions the display shows
   `MATE / no sessions`.

Pass criterion: real hook events drive the frames and LED correctly, GO raises
the right session, and navigation never touches a window.

---

## Quick troubleshooting

| Symptom | Likely cause |
|---|---|
| Daemon: "could not open port" / "resource busy" | Serial Monitor (or another daemon) still holds the port. Close it. |
| No device in `ls /dev/cu.*` | Bad cable, missing CH340 driver, or no power. |
| OLED blank | Wrong I2C address (try 0x3D) or SH1106 1.3" panel needs the SH1106 driver. |
| Display blanks ~1.5 s when daemon reconnects | Expected — USB open resets the Nano; the `H` handshake restores state. |
| No WAIT frame on a question | Check the `Notification` hook is wired and the daemon is running. |
| LED never blinks | Alerts come from `V|<kind>`. Confirm a session actually transitioned (start/wait/done/error). Test the LED directly by typing `V|ERROR` in the Serial Monitor (Level 2). Check the D8 wiring (LED + series resistor to GND, see [WIRING.md](WIRING.md)). |
| LED blinks forever | It loops until acknowledged: GO (raise) or hold GO (ack only) sends `V|OFF`. A loop also self-stops ~30 s after the daemon goes silent (and LINK LOST appears). |
| Buttons do nothing in the daemon | Confirm Level 2 first (`B|G`/`B|N`/`B|P` over serial, `B|K` on a held GO), then check the daemon's button thread/logs. |
| Screen shows LINK LOST | The daemon has been silent ~30 s: check `launchctl list \| grep claudemate` and `~/Library/Logs/claude-mate.err.log`. Any daemon line clears the overlay. |

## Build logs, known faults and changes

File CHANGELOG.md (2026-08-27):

# Changelog

All notable changes to Claude Mate are documented here.

The format is based on [Keep a Changelog](https://keepachangelog.com/en/1.1.0/).
Claude Mate is pre-1.0, so entries are grouped by **date** rather than a
semantic version until the first tagged release; see
[`packaging/VERSION`](packaging/VERSION) for the current package version. Older
entries are kept as-written and describe the design **as it was on that date** —
they are the project's history, not the current behavior (which the
[README](README.md) always reflects).

## [Unreleased]

### 2026-08-27 — Pick the connection on the device: auto, cable, bt, wifi, p2p

Asked for directly: *"i want be able to switch it on device, like connection
interface auto, bt, wifi, cable."* **SETTINGS → Connection.** GO cycles, a hold
switches and restarts.

- **`cable`** is new: both radios off, the USB link carries everything. It
  already did in every other mode — config lines, token provisioning, the boot
  `H` — so this mode does not start anything, it declines to.
- **`auto`** is new and is a MODE, never an effective transport. It resolves once
  at boot: a computer on the USB port means cable, otherwise the radio you last
  chose explicitly. Resolved from `HWCDC::isPlugged()`, which is SOF-based, so a
  wall charger is not mistaken for a Mac. The row shows what it picked —
  `auto (cable)` — because the one mode whose job is deciding for you should say
  what it decided.
- **Cycling only previews.** Reaching the fourth option costs four presses and no
  restarts, and walking away reverts.

**The gate that makes this safe.** The `Link` row was deleted because one press
moved a **credential-less** board onto Wi-Fi, which reboots into a portal that
outranks the menu — hiding the row you would undo it with. Every other mode
needs no configuration and cannot start that sequence, so the whole hazard is
one question, and the cycle answers it: **Wi-Fi is not offered until the device
knows a network.** With credentials, a failed join sits in `JOINING`, which does
*not* outrank the menu, so the row is still there to switch back.

The interesting work was not the row, it was the twenty-two places that branched
on the transport. Every one read `transport == LINK_BLE ? ble : net` — "anything
that is not BLE is Wi-Fi", true while there were two radios and still true when
P2P arrived, because P2P *is* net. `cable` broke it: a cabled device would have
been routed to a `MateNet` whose radio is deliberately off, reporting "wifi off
- usb only" as its status and `connected() == false` for ever — a device that
works perfectly, saying it does not. Three predicates (`linkUsesBle`,
`linkUsesNet`, `linkIsCable`) now make each site say which case it means.

Found by auditing the change rather than running it:

- **`auto` could walk straight past its own gate.** Pick Wi-Fi while credentials
  exist, wipe them later, and every boot resolves to a Wi-Fi transport with
  nothing to join — into the exact portal the row refuses to send you to. The
  gate belongs to the decision, not to the row that presents it.
- **`auto` demoted existing Wi-Fi users to BLE.** The fallback read a key that no
  device predating this change has, then defaulted to BLE — moving a board that
  had been on Wi-Fi for months off its own network the moment its owner chose
  "auto". It falls back to the stored transport first.
- **A hold on an untouched row did nothing.** `K` is excluded from the alias to
  `G` so it can commit, which made the first long press — the gesture every
  other confirming row teaches — silently inert.
- **Cable drew no link indicator at all.** An early return skipped the USB badge
  that `drawLinkGlyph()` ends with, leaving a blank corner on the mode most
  likely to be mistaken for "not working".
- **A no-change commit skipped the reboot**, re-introducing the early return
  `setTransport()` documents at length: the reboot IS the repair for a wedged
  stack, and three places tell you to perform it by re-selecting the mode you
  are already on.
- **The NO LINK screen led with "no token" on the cable**, sending someone to run
  pairing they do not need for a link that is already up. The token
  authenticates a radio; cable has none.

A second audit pass, run against the finished row, confirmed twelve more and
five were live:

- **`auto` still demoted portal-provisioned boards.** The first fix fell back to
  the stored `link` key — but a board set up through the portal never writes
  `link` at all; it reaches Wi-Fi through `storedTransport()`'s `haveSsid` rule.
  So the fallback missed exactly the devices it was added to protect. It uses
  the same `ssid` rule now, stated in both places.
- **`auto` asked about USB once, too early.** Enumeration is not instant, so a
  single `isPlugged()` at boot answers "no host" on a device plainly on a cable,
  and the mode whose job is noticing the cable misses it. It settles for up to
  400 ms and exits the moment a host answers.
- **`auto (cable)` was painted green whether or not anything was on the cable.**
  Green means the link is up, not that the mode is clever.
- **The row read NVS on every repaint** — flash wear and latency in the draw
  path, for a value that cannot change without a reboot. Cached at boot.
- **`?` printed `auto` and never what it resolved to**, making the one mode that
  decides for you the one you cannot diagnose over the console you reach for
  when it is behaving oddly.

A build failure worth recording, because it names nothing that was edited:
defining a function up beside the `SetRow` enum moved arduino-cli's generated
prototypes above `struct LedStep`, and the error arrived 250 lines away as
`'LedStep' does not name a type`.

### 2026-08-27 — Wi-Fi setup is a row on the device again

Reported as a flat correction: *"hold boot its wrong it should be wifi setup
option in settings."* The instruction was accurate for the firmware as it stood
— there was no such row, and a test asserted there could not be one — but the
instruction being accurate is not the same as the design being right. Teaching
the device a network is an ordinary task, and "unscrew the case and hold BOOT
while plugging it in" is not a route to one.

**Why the old reasoning did not cover this.** The row was removed on the grounds
that "pairing replaced the only reason it existed". That was about **tokens**,
and it is still true of tokens — BLE enrolment provisions those. It never
covered Wi-Fi **credentials**, which pairing cannot supply and which a device
meant to live on your network has to learn from somewhere.

- **SETTINGS → Wi-Fi setup.** GO arms, a hold confirms — the same gesture
  Factory reset uses, because the portal outranks the menu for up to five
  minutes and a mis-press should not cost that. The row's value says whether the
  device already knows a network (`set` / `none`).
- **It is not the row that was removed.** It does not touch the transport, so
  one press still cannot move a cordless board onto Wi-Fi, and it reaches the
  portal by **restarting into it** rather than raising a SoftAP beside a live
  BLE stack — which could not be undone until the next power cycle, because BLE
  cannot be re-initialised after a teardown in the same boot.
- **The request is a one-shot, cleared before the portal opens**, so an
  abandoned setup or a power cut mid-portal costs one ordinary boot rather than
  a device that comes back into the portal for ever with the row that sent it
  there hidden behind the screen it opened.

Two bugs found by auditing the change rather than by running it:

- **The one-shot was not one-shot.** `digitalRead(BOOT) == LOW || takePortalRequest()`
  short-circuits, so the flag went unconsumed on any boot with BOOT held — and
  on a bare devkit BOOT *is* GO, so the long press that confirms this very row
  is still down when `setup()` runs. The portal would open, correctly, and then
  open again on every boot after. Consumed on its own line now.
- **A pad-on board reached the portal with a BLE HID stack live.** The gamepad
  tail of `setup()` sits outside the transport branch, so a SoftAP and a HID
  GATT server shared the one 2.4 GHz radio for the portal's whole life — and at
  portal end the link service was grafted onto the pad's server, because
  `BLEDevice::createServer()` returns a singleton. Reachable by BOOT-held today,
  independent of the new row. A device dragged into setup is no longer a
  gamepad for those minutes.

Also fixed while in here: the SETUP-ended hand-back tested `transport ==
LINK_BLE`, so a **P2P** device dragged through the portal came back with its
radio off, hosting nothing, reachable only by rebooting. It asks the right
question now — is this device something other than a Wi-Fi station — and returns
a P2P device to hosting its own AP.

The test that forbade the row now pins what kind of row it is instead: that it
does not switch transports, does not open a portal in place, arms before it
acts, and consumes its flag. Each of those was checked against a deliberately
broken version first.

### 2026-08-27 — The listener only exists on networks you trust

Asked plainly: *"the server on the mac should be super secure in case I
connected not to home network."* It was not. The TCP listener bound `0.0.0.0`
at every login on every network, and `dns-sd` announced the hostname and port to
every peer on the segment before anyone connected. Its own docstring had said
"use it on a network you trust" without ever checking whether you were on one.

- **A network must be trusted before the listener exists on it.**
  `claude-mate trust` / `--list` / `--remove`. Carry the Mac to a café and the
  listener and the mDNS advert close within ~20 s; come home and they reopen.
  A network is identified by its **gateway's MAC address** — not the SSID,
  which macOS hides from a background daemon, and not the subnet, because every
  other café is `192.168.1.0/24`.
- **First run adopts the network it finds**, once and loudly, so an upgrade
  cannot disconnect a device that worked yesterday. Never worse than listening
  everywhere; strictly better from the second network on. `--trust-any-network`
  restores the old behaviour.
- **An unauthenticated peer can no longer exhaust the daemon.** The client cap
  counted only peers that had *already* authenticated, so connections that never
  finished the handshake were never counted — each one costing a thread, and the
  thread list itself was appended to per connection and never pruned. There is
  now a separate budget for in-flight handshakes, and the list is pruned.
- **…nor hold a slot open indefinitely.** `NET_AUTH_TIMEOUT_S` was a per-*byte*
  timeout: the reader takes one byte at a time and a socket timeout bounds the
  gap between reads, not the read. One byte every four seconds held a thread for
  512 × 5 s — about forty minutes — and enough of those keep the real device out
  without ever knowing the token. The handshake now has one wall-clock deadline.
- **The restart path was broken before anything used it.** `stop()` set an event
  that `start()` never cleared, so a re-opened listener came back bound,
  listening, and attached to an accept loop that had already exited. That is
  worse than a failure because it looks exactly like success — and it is what
  the gate does every time you come home, so it had to work.

Both DoS fixes and the restart are pinned by tests that were checked against the
unfixed code first. The first attempt at the slowloris test passed against the
bug, because blocking on `recv` is itself the long gap the old timeout already
caught; it polls with `select` now and fails without the deadline.

**What this is not.** It is a strong practical control, not a cryptographic one:
someone already on your LAN who knows your gateway's MAC could forge it. And the
wire is still plaintext — session names, project paths, the account email and
the terminal mirror's contents are readable by anyone sniffing a network you
have trusted, and an on-path attacker can inject button events. The token is
never sent, so nobody can impersonate your device, but that is authentication,
not confidentiality. [`docs/USING.md`](docs/USING.md) says so in those words.
Encrypting the channel is the next piece of work, not this one.

### 2026-08-27 — A Wi-Fi link with no network in it

A third transport: `p2p`. Wi-Fi with the infrastructure taken out. The **device**
brings up its own access point, your Mac joins *it*, and the device reads the
Mac's DHCP lease off its own AP and dials the daemon on the usual port.

- **No router, no credentials, nothing else on the segment.** `wifi` needs the
  password of a network you both trust, which is a non-starter on a guest SSID or
  a locked-down corporate one. `p2p` needs no network at all.
- **Every byte above the socket is the same code.** Same nonce handshake, same
  line protocol, same `NetLink` on the Mac side — which needed **no changes**.
  The AP's SSID and password are generated once and kept, so the Mac saves the
  network and rejoins it at every login (unlike the setup portal's, which is
  regenerated on every start).
- **`claude-mate link <wifi|p2p|ble>`** moves the cabled device between
  transports. There was previously no way to do this at all: the setting lives
  behind the firmware's `I|` console command, and the only route to that console
  was a hand-run `miniterm` on a port the daemon holds open — so the two readers
  split the device's replies and a switch that had worked looked like one that
  had not. The socket verb takes three fixed words and builds the line itself;
  it is deliberately **not** a general relay, because the same console takes
  `T|<token>`.
- **The trade, stated plainly: your Mac has one Wi-Fi radio.** While it is on the
  device's network it is not on yours. That is not fixable from this side, and
  [`docs/USING.md`](docs/USING.md) says so rather than letting you find out.

Two things a compiler cannot catch, both found by reading the states rather than
the syntax: every "not connected" test in `netcfg.h` is about the *station*
interface, and a P2P device has none — so `pollLinked()` dropped the link on the
first poll after `A|OK`, and `pollDial()` called `startJoin()` (`WIFI_STA`),
tearing down the very AP it was hosting. Both now ask the question that means
something for an access point: is anyone still associated?

The P2P join panel sits *below* the menu in the render order, unlike the setup
portal which outranks everything. A device whose Mac never joins would otherwise
have no way back to BLE but a cable — the "one press, no way back" trap the Link
row was once removed to avoid.

### 2026-08-27 — The daemon says why it did not start

From an afternoon that started with "I can't start claude mate and connect
device at all".

**The daemon had crash-looped 1786 times.** `import serial` at the top of
`claude_mate_daemon.py` was raising `ModuleNotFoundError` — on a machine where
pyserial *was* installed. The LaunchAgent runs `/usr/local/bin/python3`, which
is a symlink the python.org installer rewrites on every minor release; 3.14
landed, the symlink moved, and the packages stayed behind in 3.12's
`site-packages` where nothing was looking. `KeepAlive` turned that into a restart
every five seconds and a **50 MB** log of the same traceback. The whole time,
`claude-mate daemon` said only *"nothing is answering on the socket yet"* and
pointed at the log the answer was already in.

- **Fixed at the cause: the installer builds a virtualenv and pins the daemon to
  it.** `.venv/bin/python3` is a symlink to a *concrete* version with its
  packages beside it, so a Python upgrade can no longer separate the two. Where
  a venv cannot be created, the interpreter is resolved through `realpath` and
  pinned rather than left floating.
- **A failed start now prints the failure.** `claude-mate daemon` reads back the
  tail of the daemon's stderr and shows the exception — the frames included —
  instead of the path to it. The one crash launchd *cannot* narrate (a missing
  interpreter, where nothing is ever written to the log) is detected separately
  and named.
- **A crash loop can no longer eat the disk.** The daemon truncates its own
  stderr past 8 MB (`CLAUDE_MATE_LOG_MAX`) *before* the first import that can
  fail — a cap after the imports would never have run, because the crash was the
  import.
- **`pip install -r daemon/requirements.txt` now installs what the daemon needs.**
  `bleak` was a comment in that file while the shipped plist set
  `CLAUDE_MATE_BLE=1`, so following the daemon's own recovery instruction fixed
  the crash and left a BLE device with nothing to connect to. The installer also
  stops swallowing pip's stderr, drops `--user` (a third place for the same
  package to hide), and installs `pyte` — which it never had, so the PTY wrapper
  had been silently falling through to unwrapped Claude.

### 2026-08-14 — A dead cable no longer takes every device button with it

Reported from the couch as "the daemon is stuck". It was not stuck. It was
running perfectly, and the one thread that reads the device had been dead for
over two hours.

The USB port dropped (`Device not configured`), and six seconds later the device
came back on BLE and said `H`. The hub forwards `H`/`K` to the serial link's
token push no matter which transport carried it, so the write landed on a port
that had just closed — an `AttributeError`, which the handler around that write
does not catch. It escaped the dispatcher and ended the button reader.

**Nothing else stopped**, which is the whole problem. Sessions kept updating,
LEDs kept firing, the terminal keys and the web page kept working, the link
still showed connected. Every button on the device was simply dead, and the only
evidence was one traceback in a 34 MB log.

- **Fixed: provisioning a port that closed under it.** The token push checks the
  port is open, and closing it now spends the pending arm rather than leaving it
  aimed at a port that no longer exists.
- **Fixed: one bad line could cost the entire input path.** The button reader
  logs a failed dispatch and reads the next line. It is the only way in from the
  device; a line it cannot handle is worth a log entry, not the buttons.

`tools/test_net_link.py` covers both. The reader check feeds **two** presses and
throws on the first — with one press a dead thread and a live one both leave the
loop, and the test would pass against the bug it exists to catch.

### 2026-08-14 — Arrow keys all the way down, not just at the top

The top level got a chooser and every level underneath it kept asking you to
read a number off a list and type it. Reported bluntly and fairly: *"top level
navigation is amazing but internal is bullshit."* It was — **Accounts** ran
`claude-mate-switch --help` and left you looking at an argparse usage block
under a "press enter to go back".

- **One chooser, in `bin/claude_mate_ui.py`, that every level calls.** The app's
  submenus, `claude-mate accounts rm`, and the account picker the wrapper shows
  on every session all use the same `pick()` — so ↑↓ / ⏎ / esc mean the same
  thing everywhere, and `esc` always means back.
- **Accounts is a real menu**: every login with its email, open one to use it
  for the next session or delete it. **Device** is a real menu too: connection
  report, pair, show the token, restart the daemon.
- **`claude-mate accounts rm` with no argument asks** instead of answering
  "which account?". That error was fair at the end of a pipe and silly at a
  terminal, where the list is already known.
- **The wrapper's account picker is a chooser**, with the old typed prompt kept
  intact for anything that is not a terminal on both ends.

**And that last one is a bug fix, not a coat of paint.** The picker asked you to
*type* a profile name — so an arrow key, the thing anyone reaches for at a list,
typed an **escape sequence into the name field and created a profile called
`\033`**. It renders as a blank row with somebody's email beside it, and it
cannot be typed back to delete. The maintainer's machine had one, plus a `в`
from a keyboard left in the wrong layout. A chooser cannot do that to you, and
`tools/test_app.py` now mashes the arrow keys at the picker and asserts no
profile appears.

Those existing casualties are reachable again: unprintable names show as
`'\x1b'`, are marked *unprintable name*, and can be selected and deleted.
Deleting from a menu confirms with a chooser whose cursor starts on **No**,
rather than by typing a name that in this exact case cannot be typed.

- **Fixed: a profile name could emit a control sequence into your terminal.**
  The name is also a *directory* name, so the path carries the raw ESC too, and
  printing it does not show a funny character — it starts an escape sequence and
  the bytes after it are eaten. Everything rendered from data goes through
  `printable()` now. Pinned by a test that feeds the chooser a label containing
  `\x1b[31m` and an OSC title-set, and counts stray ESC bytes in the output.
- **Fixed: importing the shared module put colour back into pipes.** The import
  re-bound `B`/`D`/`OFF` *after* this file blanks them for a non-TTY, so every
  piped `claude-mate` regained ANSI. Caught by the existing test; the module
  keeps its own copies and the script keeps its own.

### 2026-08-13 — `claude-mate` is an app, and the CLI is finally written down

- **`claude-mate` on a terminal is now an arrow-key app.** The queue with the
  cursor live in it — ↑↓ to move, ⏎ to raise a session, `a`/`f`/`m`/`c` for
  acknowledge, follow, mirror and continue — plus a menu that **starts a new
  session** without going back to a shell. That entry runs `claude` through the
  wrapper in this terminal, because a session started any other way is
  invisible to the daemon and never reaches the device. There are two entries,
  one of them `--dangerously-skip-permissions`, rather than one entry and a
  hidden default: skipping permission prompts is a decision and a menu should
  say which one it is making.
- **On a pipe it is exactly what it always was.** The app appears only when
  stdin *and* stdout are both terminals. Both, deliberately: the test suite run
  from a developer's terminal inherits a TTY stdin, and CI redirects
  `< /dev/null` — either check alone is wrong on a machine that matters.
- **`claude-mate daemon` starts it, and the old advice never could.** Every
  error path in the project printed `launchctl bootstrap gui/$UID …`, which
  fails with `Bootstrap failed: 5: Input/output error` whenever the job is
  already loaded — that is, on every machine that ran the installer, which is
  every machine that has the file. It goes through `kickstart -k` now, and
  never spawns the daemon directly: there is no single-instance guard and the
  socket is unlinked before binding, so a hand-started second copy silently
  takes the socket from the first while the first keeps the serial port.
- **Fixed: `claude-mate-switch` was broken for everyone who installed it.**
  `install.sh` symlinks it into `/usr/local/bin` but deliberately does not
  symlink the wrapper, and the tool resolved its sibling with
  `os.path.abspath(__file__)`, which does not follow symlinks — so the
  installed command died on import with `cannot load
  /usr/local/bin/claude-mate-wrap` and worked only from a checkout. One word:
  `realpath`.
- **Fixed: `claude-mate-connect` had no `--help`** and parsed its flags by
  substring, so `--help` printed four screens of link diagnosis without naming
  a flag, and a typo like `--pari` silently ran the report instead of erroring.
- **Fixed: `claude-mate watch | tee` wrote a clear-screen into the file** once a
  second. The colours were already blanked for a non-TTY; this one escape was
  not.
- **Documentation.** A new [docs/CLI.md](docs/CLI.md) is the thing that did not
  exist: one page saying that there are **four** binaries, what each is for, why
  the wrapper is not on `PATH`, every command and alias, and every
  `CLAUDE_MATE_*` variable. [docs/PROTOCOL.md](docs/PROTOCOL.md) now documents
  the control socket's six verbs — it called itself the source of truth and had
  only ever described the session-update line. README's second, drifted copy of
  the command list (it had lost `continue` and `new-terminal`) is back in sync.
- `--version`, on the tool that had a `packaging/VERSION` and no way to ask.
- New `tools/test_app.py`: the key decoder against real byte bursts, and the app
  driven under a PTY with arrow keys. It caught two bugs in its own subject —
  a decoder that read through `sys.stdin` while selecting on the descriptor (so
  every arrow arrived as a bare ESC and nothing moved), and a renderer that
  trusted `os.get_terminal_size()` and quietly ate its last line whenever a
  terminal honestly reported 0×0, which is what `pty.openpty()` hands you.

### 2026-08-13 — Sleep that stays asleep, and a gauge that does not vanish when it matters

Reported after the BLE release: *the device wakes the instant you put it to
sleep, and the cell is going down faster than it did on Wi-Fi.* Three unrelated
faults, found by auditing the whole power path rather than the transport.

**Sleep**

- **Fixed: one failed power-off broke every power-off after it, permanently.**
  `powerOff()` arms two GPIO latches that live in the RTC domain and survive
  every reset except a true power-on, and `setup()` released them only when the
  boot was a deep-sleep *wake*. But `esp_deep_sleep_start()`'s own failure path
  is `abort()` — a **panic reset**, not a wake — so a single sleep that did not
  take came back with the backlight pinned LOW (a running device with a screen
  that cannot light) and the wake pad stuck in RTC function, where
  `digitalRead()` reads it as permanently pressed. From then on the device could
  never sleep again and nothing on the glass could say why; only pulling the cell
  cleared it. The release is unconditional now, and `rtc_gpio_hold_dis()` comes
  **before** the `rtc_gpio_deinit()` it was silently defeating — a held pad
  ignores the mux write, so that line only ever *looked* like it handed the pin
  back.
- **Fixed: the wait-for-release before sleeping was unbounded.** It runs after
  the panel, the backlight and both radios are already down, so a wake pin
  reading LOW for any reason parked the board awake, dark and at full clock
  until the cell was flat — indistinguishable from dead hardware.
  `rebootAfterRelease()` had already learned this and even names `powerOff()` as
  its precedent; the lesson never came back the other way.
- **The device can now say which of these happened.** `?` and the About page
  report `esp_reset_reason()` and the ext1 wake mask, so a spurious wake and a
  crash-reboot — identical from across a room, and completely different bugs —
  are one line apart. Brownout and watchdog resets say so by name.

**Where the battery was actually going**

- **Fixed: `loop()` never yielded.** Nothing on the loop blocks any more, so
  `loopTask` was always ready, `IDLE1` never ran, and core 1 never reached
  `waiti`: a 240 MHz core at 100% duty doing five `digitalRead`s per pass. On
  the datasheet's own figures that is on the order of 10–15 mA — **comparable to
  the entire radio budget the BLE migration was undertaken to reduce**. One
  `delay(1)`.
- **Fixed: the game pinned the backlight on forever.** `UI_GAME` re-armed the
  hibernate timer on every pass with no test of `game.idle()`, so an abandoned
  START screen, codex card or finish screen held the largest load on the board
  at full duty until the cell died. The screen now blanks in place, and because
  the three nav buttons never reach `onButton()` in this mode, the game branch
  reads their pins itself — both to count a thumb as presence on the screens
  where no level is running (picking a milestone, reading a codex card) and to
  wake the panel, swallowing the press that did it so it cannot also start a
  sprint nobody can see.
- **Fixed: a lit panel hibernate could never turn off again.** `enterPad()` and
  `leavePad()` wrote the backlight directly while `screenOn` stayed false, and
  `sleepScreen()` early-returns on `!screenOn`. Both are reachable with nobody
  touching the device — `G|1` from the daemon, or an alert leaving the pad — and
  one of them writes *full* brightness onto a screen that is then never
  repainted. `wakeScreen()`/`sleepScreen()` own the pin in every mode now.
- **Fixed: the ADC's power domain was taken on the first battery poll and held
  for the rest of the boot** (~1 mA, by Espressif's own note) because the core
  only drops the oneshot unit when the pin changes bus. Released once per poll.
- **Fixed: a pairing prompt rendered the full 110 KB canvas ~35 times a second
  for 45 s** to animate a countdown that changes once a second — and any peer in
  radio range can re-arm it on an unprovisioned board.
- **Fixed (daemon): a device saying hello was dragged back into a terminal view
  it never opened.** The mirror is a daemon-side 1 s timer torn down by three
  things, none of which was the device going away — so after any reboot or
  reconnect the Mac pushed 19 lines a second into a device that had not asked,
  and the view sits in front of the status bar, hiding the battery and the link
  glyph. Closed on `H`, with the fetch race behind it closed too — and because
  "said hello" means *rebooted* only most of the time, a device whose view
  survived the drop (a BLE flap shorter than the 30 s watchdog) answers its own
  `H` with `B|M` to put it straight back. The device is the authority on what is
  on its glass; the daemon asks rather than assumes, using verbs both ends
  already speak.

- **Fixed (test): `tools/test_account_switch.py` failed for anyone who actually
  uses account switching.** `select_account()` consults `CLAUDE_MATE_ACCOUNT`
  before it offers the picker, and the test never cleared it — so fourteen
  checks failed on a developer's machine and none of them in CI, which is the
  worst possible place for that asymmetry to be.
- **Fixed (daemon): an unprovisioned board was re-dialled every few seconds
  forever.** The backoff counter was cleared when a device was *found*, before
  the session was tried, so a handshake that failed instantly retried against a
  flat 1 s sleep — and every cycle drags the peripheral out of its advertising
  duty cycle. A board with no stored SSID defaults to BLE, so this was every
  factory-reset device. The Wi-Fi path already backed the same failure off to
  30 s.

**The gauge**

- **Fixed: a nearly-flat cell reported itself as *absent* and erased the
  indicator.** The "nothing is wired to the divider" threshold was 3000 mV — a
  reading only a real, nearly-empty 14500 can produce on this board, since the
  charger rail holds the sense node at ~4.2 V when nothing is fitted. So the
  chip vanished and both readouts printed `no cell` at exactly the moment the
  cell was empty, and the same branch forced `charging` false, so putting it on
  the charger showed no bolt either. It is 2400 mV now — below where the 3V3
  regulator gives up, so it means what it says.
- **A `LOW` warning that blinks**, from `BATT_LOW_MV` (3300 mV, the percent
  curve's own zero). One red segment covers 3.7 V down to 3.0 V — about half the
  usable capacity — so the chip looked identical at *"soon"* and at *"now"*. It
  blinks on its own clock rather than the daemon's, because a cell going flat
  while the link is down is exactly when it has to still work.
- **The battery is on the screens that did not have it**: the gamepad face
  (which the device can boot straight into, and the most power-hungry standing
  configuration it has), the ACTIONS sheet, the account picker, the Wi-Fi setup
  portal (AP mode, the heaviest radio state there is) and the terminal mirror.
- **macOS gets the real charge.** The BLE gamepad already advertised a standard
  Battery Service that macOS reads — and was feeding it a hard-coded `100`
  forever. It carries `battPercent` now.
- **"Charging" is only claimed when a voltage says so.** `HWCDC::isPlugged()` is
  "a host is sending SOF frames", which is equally true in constant-current, in
  constant-voltage, and hours after termination. This board cannot detect
  termination at all — the sense divider sits on the charger rail — so the
  readouts say **on USB** for that case and keep *charging* for the voltage
  tests. See [#26](https://github.com/vlgutv22/claude_mate/issues/26) for the
  cutoff this still does not have.
- **The gauge's arithmetic moved to `battery.h` so a host can run it**, and
  `tools/test_battery.py` does — in CI, beside the game engine's harness, which
  was split out for the same reason. It immediately caught one more: the level
  hold stamped its clock `now ? now : 1UL`, which at `millis() == 0` is a time
  in the *future*, and the unsigned compare underflowed straight past the 45 s
  hold. That sentinel has been unpicked three times in this firmware; it is a
  `bool` now and cannot come back.

**Not changed, on purpose**

The two radio-level reasons BLE may not beat Wi-Fi on this board — the S3's BT
controller ships with modem sleep compiled *off*, and the duty cycle only runs
while advertising while the daemon holds the link open all day — are documented
in [`docs/POWER.md`](docs/POWER.md) and tracked in
[#25](https://github.com/vlgutv22/claude_mate/issues/25). Both are radio
behaviour changes whose only justification is a measurement nobody has taken
yet, and that table is still the thing owed.

### 2026-08-13 — The rest of the review, including two features that could not work

- **Fixed: the gamepad could never start on a BLE board.** `setup()` brought the
  link up and then tore it down for the pad three lines later — the
  init-after-deinit this chip does not survive — so the pad failed in *every*
  boot, and failing took the link with it: flipping the switch rebooted the
  device and came back with the switch off, while `setup()`'s own comment
  promised "THE GAMEPAD SURVIVES THE REBOOT". The link is no longer started when
  the switch is on, and turning it on at runtime reboots, mirroring the exit that
  already did.
- **Fixed: the PAIR? prompt was unanswerable from the game screen, and the 4th
  button never answered it anywhere.** The prompt is drawn *over* the game, but
  both nav pollers returned before edge detection in `UI_GAME`, so GO started a
  run behind it and the firmware auto-refused 45 s later. The 4th button is
  dispatched by its own poller and never reached `onButton()`, so *"any other
  button = refuse"* was untrue: a tap changed screens behind the prompt, a
  double-tap opened the menu and emitted `B|M`, and a 2 s hold slept the board
  mid-offer. All three gestures answer it now.
- **Fixed: the three pairing timeouts were ordered wrong** — 50 s daemon against
  45 s device, so the device always spoke first and the daemon's *"nobody pressed
  GO"* branch was unreachable for its own case: every unanswered offer was
  reported as though somebody had refused. Now 45 s (device answers) → 60 s
  (device drops the link) → 65 s (daemon gives up), pinned by a test that reads
  all three out of two languages and three files.
- **Fixed: a successful pairing could report itself as declined.** The flag meant
  "a question was answered" rather than "it was refused", so a slow handshake
  after GO told the person who had just pressed it that they had said no.
- **Fixed: the daemon waited out the clock on a device that had gone.**
  `_await_auth_line` checked neither the connection nor the disconnect event, so
  a board carried out of range mid-pairing pinned the daemon inside the client
  context for ~51 s — not scanning, not recovering.
- **Fixed: BLE dropped the farewell frames on shutdown** (7 of 10 runs measured).
  `V|OFF` and the "daemon stopped" frame are coroutines *scheduled* on the BLE
  loop, and stopping the loop in the same batch discarded them, so a battery
  device sat on a stale frame flashing an alert for up to 30 s — exactly what
  those two writes exist to prevent.
- **Fixed: the setup portal erased a configured daemon address.** The host input
  had no prefill and the port carried a literal `8787`, so a visit that only
  re-entered a token — the expected visit on a BLE device now — silently reset
  both and dropped the device back to the mDNS discovery an explicit host exists
  to avoid. The form round-trips them, like the token box already explained
  itself.
- **Fixed: `rebootAfterRelease()` used `millis() + X`**, the one non-rollover-safe
  idiom left in a file that fixes that arithmetic in three other places — **and
  the test pinned the buggy form**, so it would have defended it.
- Also: `PORT_GLOBS` in `claude-mate-connect` claimed a `wchusbserial` pattern the
  daemon never looks for, so a CH340 board got a promise it could not keep *and*
  the pairing advice that would have worked was short-circuited; a `select` check
  written as `A or B` covered every possible reply and could not fail; and the
  docs still named the deleted **Set token** row, GO-at-power-on after
  `forcePortal` became BOOT-only, and `pyserial` as the only permitted dependency.

### 2026-08-12 — One command to install it, and a manual for both ways to drive it

- **Changed: the install is one command.** `./install/install.sh --yes` does all
  of it — hook, the `settings.json` merge (backed up first), the LaunchAgent
  started, and the three CLI tools on `PATH`. It had exactly one interactive
  prompt, which is the difference between "one command" and "one command, then
  watch for a question". `--yes` is opt-in rather than the default on purpose:
  the question is whether to edit `~/.claude/settings.json`, and a script that
  rewrites your editor config without being asked is not one to trust twice.
- **Added: [`docs/USING.md`](docs/USING.md), the manual.** The daemon (what it
  is, how to check and restart it, the five states and which three need you), the
  CLI (every command, each **paired with the device button it presses**), the
  device (four buttons, three gestures, the screen, the LED, all eight SETTINGS
  rows), connecting a device, and a symptom-to-cause table for when it is not
  working. One page, because there are two ways to drive one thing and
  documenting them apart would invite them to drift.
- **Fixed: `docs/INSTALL.md` described a project two iterations old.** Nano only,
  Arduino IDE, no ESP32-S3, no BLE, no LaunchAgent, no CLI. It leads with the one
  command now and hands S3 flashing to `firmware/README.md`, where the reasons
  `arduino-cli upload` cannot do it are already written down.
- **Added: a docs-drift guard.** `tools/test_cli.py` asserts that every button
  command the CLI implements appears in the manual, that the install one-liner
  printed in the docs is verbatim what the installer accepts, and that the manual
  states the same-press claim the design rests on. Docs rot silently; a command
  documented but removed is worse than one undocumented, because someone types it.

### 2026-08-12 — `claude-mate`: the device's interface, in a terminal

- **Added: `claude-mate`.** The queue, the selection, GO, ACK, FOLLOW, the
  mirror, "continue", a new terminal — everything the device does, from a
  terminal. The device is the better interface, but it is one device, sometimes
  across the room and sometimes flat, and all of this was already a line on the
  daemon's socket.
- **It presses the same buttons.** `claude-mate go` sends `press|G`, which the
  daemon hands to the **same `ButtonReader`** that handles `B|G` off the wire. So
  every rule that applies to a real press applies here: PREV scrolls the mirror
  instead of moving the selection when the mirror is open, GO closes the mirror
  first, a browser holding the grab swallows the lot. A CLI that called
  `_go_pressed()` itself would be a second implementation of GO, and the two
  would drift the first time either changed. `select` is the one addition — the
  device walks there with PREV/NEXT, and a terminal that prints the whole queue
  should be able to point at a row. Ambiguous names are **refused rather than
  guessed**, because this moves what GO acts on.
- **Added: `claude-mate accounts`, and `accounts rm`.** Deletion runs in the
  CLI's own process, never over the socket: that socket is `chmod 0666` so hooks
  in any shell can post updates, so everything on it is reachable by every local
  process. Reading state and pressing buttons survive a stray write; removing a
  login does not. Confirmation is **typing the name back**, not a y/n — a y/n on
  a destructive action is a reflex, and typing the name also proves you are
  deleting the one you think you are.
- **Fixed: a stray keystroke at the account picker created an account.** Anything
  typed there became a profile, and an arrow key types an *escape sequence* — so
  a real accounts dir held a directory named `\033`, which prints as a blank row
  with somebody's email beside it, and another named `в` from a keyboard left in
  the wrong layout. Both had been logged into, because the picker committed and
  claude then asked for a login. A new name is now **offered** rather than
  assumed, and implausible ones (unprintable, over 32 chars, containing a path
  separator — `../` under the profiles root was never a naming choice) are
  ignored outright. `claude-mate accounts` shows such names as reprs so they can
  be identified, and `accounts rm` takes an index, because `\033` cannot be typed
  at a prompt.

### 2026-08-12 — No Wi-Fi on the device's menu at all

- **Removed: the setup-portal row.** It existed for exactly one reason — a
  factory-reset board with no cable had no way to be given a token — and
  enrolment removed that reason. What was left was a Wi-Fi flow wearing a label
  that said *Set token*: press it and you get an access point, a phone and a
  secret to transcribe, on a device whose whole point is that it does not need
  any of that. `SETTINGS` is now eight rows and none of them touches Wi-Fi.
- **The order mattered and was learned the hard way.** Removing this row
  *before* pairing existed stranded a real board within minutes, and putting it
  back was the right call at the time. `tools/test_ble_link.py` now asserts the
  `E|?` handler exists in the same breath as asserting the row does not, so the
  removal cannot be repeated without the replacement.
- The portal is still reachable where a mistake cannot reach it: `Z` over USB,
  or **BOOT**/**GO** held at power-on. A board whose BLE will not start needs
  something, and both of those require physical access the menu does not.

### 2026-08-12 — Pairing: one command, one button, no Wi-Fi anywhere

- **Added: `E|`, an enrolment handshake over BLE, and `claude-mate-connect
  --pair`.** Provisioning a cordless board meant a cable it was nowhere near, or
  a Wi-Fi access point, a phone and a 32-character secret typed by hand — over a
  BLE link that was *already connected and talking to the daemon*. Now: run the
  command (or press `d` at the account picker), the device puts **PAIR?** on its
  screen, press **GO**, done.
- **The device is the one that asks its human**, which is the whole security
  argument. Being in radio range gets an attacker a prompt on a screen they
  cannot reach and nothing else; `E|<token>` is refused outright unless a button
  was pressed in that same connection, because *"has no token yet"* must never
  be permission by itself. Approval is single-use and dies with the connection,
  the daemon's side is **armed for three minutes** rather than on, and a refusal
  disarms it so a declined device is not asked again on a loop. The cost is
  stated in `docs/PROTOCOL.md` rather than glossed: the token crosses the air
  once, in the clear, inside that window — the link is already unencrypted by
  design, but a sniffer listening at that second learns it.
- **Changed: every "no token" message names that route.** Two screens and the
  daemon's log had been pointing at the Wi-Fi portal, which is the long way
  round, and before that at a cable a cordless board may not have. They now all
  say `claude-mate-connect`, pinned together by a test — they had already
  drifted twice.

### 2026-08-12 — The cable provisions the radio, and the picker can say why it did not

- **Added: the daemon hands its token to any device that appears on USB.** *"How
  do I connect it after a factory reset"* had two honest answers — raise a portal
  from a phone, or type `T|<token>` down the cable — and both are work nobody
  should be asked to do, because the wiped device and the daemon that knows the
  secret are *already joined by a cable over which provisioning is the trusted
  path*. Every serial open now pushes the token. Measured on hardware: `no token`
  → `serial: handed the device this daemon's token` → `BLE device connected`, in
  **four seconds**, with nothing typed. Unconditional rather than conditional on
  "does it need one", because USB has no handshake to ask over (it is trusted by
  being physical) and the daemon's token is the authority — a device holding a
  different one cannot link, so overwriting is the repair. NVS skips a write
  whose value is unchanged, so the steady state costs nothing.
  `CLAUDE_MATE_NO_USB_PROVISION=1` turns it off.
- **Added: `claude-mate-connect`, and a `d) device` entry in the account
  picker.** That prompt is the only Claude Mate UI on the Mac, and until now it
  could only choose an account — so a device that would not link had its
  explanation in two places nobody at that prompt was looking: the device's own
  glass, and a log file. The command reports every link (daemon, token, cable,
  BLE) and prints the shortest fix for whichever is down, then the picker comes
  back. It also states the thing that reads as a fault and is not: **the device
  never appears in System Settings → Bluetooth**, because the status link is an
  unpaired GATT peripheral and the token handshake, not pairing, is what decides
  who may drive it.

### 2026-08-12 — The radio switch comes off the glass, the token screen moves to the front

- **Changed: no `Link` row in SETTINGS.** It was a plain toggle, so **one press
  moved a cordless board onto Wi-Fi** — and a board with no credentials then
  reboots into the setup portal, which outranks the menu and does not time out
  for a Wi-Fi device, so it hides the very row you would use to undo it. One
  press on the glass, and no way back without a cable. Found the way these
  things are always found: a board that had "stopped working over BLE" turned
  out to be sitting on Wi-Fi with no SSID, because the row had been pressed. The
  transport is not deleted — `I|WIFI` / `I|BLE` still work over USB, which keeps
  that switch behind a cable you have to actually have: if you can type `I|WIFI`
  you can type `I|BLE` back. Which radio is live, and whether it has found the
  daemon, is still on the glass in **SETTINGS → About**, which now colours the
  link green when the daemon is on the other end — the signal the `Link` row
  used to carry.
- **Changed: `Wi-Fi setup` becomes `Set token`, and moves to the top of
  SETTINGS.** Same portal behind it; a different name, because on a BLE device
  the only field that matters is the token and a row labelled *Wi-Fi setup* is
  a row nobody presses when a token is what they need. The value answers before
  you press it — `none`, in red, *is* the reason a freshly reset board is doing
  nothing. It is first because it is the row you need when nothing else works,
  and five rows are visible without scrolling.
- **Fixed: a factory-reset board with no cable attached could not be given a
  token at all.** For one commit this row was removed alongside `Link`, on the
  reasoning that both were Wi-Fi doors. They are not: the `Link` row *changes*
  the transport, while this one *provisions* the device, and on BLE it is the
  only on-glass route to a token. What remained was BOOT-held-at-power-on — an
  incantation nobody discovers, and useless advice to someone holding a cordless
  board that has just wiped itself. It is also not the trap `Link` was: on a BLE
  device the portal expires after five idle minutes and hands the glass back,
  and the token it takes reaches the running stack.
- **Changed: every "no token" message on the glass names that row** rather than
  a cable. `send T|<token> over USB` is not an instruction when the board is on
  its cell across the room; the status line, the NO LINK screen and the
  `A|NOTOKEN` note now all say `MENU > Set token`, and the daemon's log gives
  both routes. A test pins the three device-side strings together, because they
  drifted once already — the glass advertised a USB-only route while the only
  on-glass route had been deleted.
- **Fixed: a config write to an unprovisioned Wi-Fi device killed the setup
  portal.** `restart()` stopped the portal, saw no SSID and dropped to `OFF`. An
  unprovisioned Wi-Fi device *is* a device sitting in the portal — that is where
  `begin()` puts it — so `T|<token>`, typed at exactly the device that needs a
  token, tore down the only screen that could finish the job and left no link,
  no portal, and no way back but a reboot. It now does what `begin()` does:
  nothing to join means the portal.

### 2026-08-12 — A board with nothing in NVS can get itself a token

Five ways a factory-reset ESP32-S3 could not be provisioned at all, found by
wiping one and trying. Every one of them ends the same way: a device advertising
nothing and answering nothing, which no test on either side of the protocol
could have seen. `tools/test_ble_link.py` now pins all five statically
(43 → 57 checks).

- **Fixed: an unprovisioned board came up in a portal it could not satisfy.**
  Empty NVS defaulted the transport to Wi-Fi, so `begin()` found no SSID and
  raised the setup portal — which outranks every screen in `render()` and blocks
  the menu, including the **SETTINGS → Link** row that would have moved the
  device to BLE. The way out was reachable only from behind the thing blocking
  it. A board with nothing stored now comes up **on BLE**, the radio that needs
  nothing stored to work. A board with an SSID still comes up on Wi-Fi: an
  upgrade must not move a working device onto a different radio behind its
  owner's back.
- **Fixed: `T|<token>` reached NVS but not the running BLE stack.** The device
  went on answering `A|NOTOKEN` with the correct secret in flash beside it —
  indistinguishable, from either end, from a daemon rejecting a token that is
  right. Since BLE cannot be restarted in the same boot, the stack now takes the
  token live. The same hole existed on the **portal** path, where the page
  handler writes to NVS and has never heard of the stack, and that was the worse
  one: it is the only way a cordless board can be given a token with no cable.
- **Fixed: holding BOOT on a BLE board was a one-way door.** The portal only ever
  timed out on a device with credentials to fall back to, because for an
  unprovisioned Wi-Fi device the portal is all there is. A BLE device has a
  working link and no use for the screen, so it now expires after five idle
  minutes and hands the glass back — and expiring with no SSID powers the radio
  down rather than dialling an empty one, which would put the STA back up on the
  one radio the other transport is trying to use.
- **Fixed: `W|`, `S|` and `T|` restarted Wi-Fi on a BLE device.** Provisioning
  credentials for later would associate immediately, leaving both radios up —
  the exact contention one-transport-at-a-time exists to prevent. They are
  stored either way and applied only when Wi-Fi is the live link.
- **Fixed: the portal would not save a token without a network.** A blank
  network box was a `400 network required`, which is the right rule for the
  Wi-Fi flow and the wrong one on a device whose link is BLE, where the page is
  only ever opened for the token — it left "type a fake network name" as the way
  through. It now refuses only a submission that would save nothing, the
  network field says it is optional, and the dropdown offers **none**: a
  `<select>` always submits something, so a BLE user setting a token was
  silently storing whichever network happened to top the scan.
- **Changed: the screens a fresh board actually shows name the missing token
  first.** `ble: start the daemon with --ble` and `check it is running with
  --ble` are both true and both send you to the wrong half of the daemon's log
  when the real answer is that this device has no secret yet. The status line and
  the NO LINK screen now say `send T|<token> over USB`, and the `A|NOTOKEN` note
  no longer points a BLE user at a portal it never opens.

### 2026-08-11 — BLE as a transport, and one gamepad switch instead of two rows

- **Added: the line protocol over Bluetooth LE** (`firmware/claude_mate_s3/blelink.h`,
  `daemon/blelink.py`), as an alternative to Wi-Fi for the battery build.
  Nothing about the protocol changes — the same `F|`/`V|`/`M|`/`P` down and
  `H`/`K`/`B|` up, the same nonce/HMAC handshake, the same token — so nothing
  above the wire knows which pipe it got. What changes is the shape of the idle
  cost: Wi-Fi holds an association open all day for a device whose status
  changes are rare and bursty, while BLE **advertises for 200 ms and then goes
  quiet for four seconds**, repeating, until the daemon connects. Those figures
  are the ones [issue #21](https://github.com/vlgutv22/claude_mate/issues/21)
  asked for, credited there to Jack Jansen in the ESP8266/ESP32 group, who
  measured roughly 5% of normal consumption with that rhythm on his own battery
  devices. The roles are **inverted** from the TCP transport and deliberately:
  there the device dials out because the daemon's address is stable and a DHCP
  device's is not; here the Mac scans, because the side with mains power and a
  real scheduler should be the one doing the looking. The device consequently
  needs no daemon address at all — no mDNS browse, no host field in the portal.
- **Changed: `SETTINGS → Link` picks the radio, live, with no reboot** — and it
  is a stored byte rather than a compile-time `#define`, which is the part of
  #21 that makes the rest usable: moving a device on a desk between transports
  should not need a toolchain. `I|WIFI` / `I|BLE` does the same over the cable.
  The old stack always goes down before the new one comes up, because the S3 has
  **one 2.4 GHz radio** and even a few hundred milliseconds of overlap is the
  contention the whole arrangement exists to avoid. Holding BOOT at power-on
  still forces the Wi-Fi setup portal whichever transport is stored — an escape
  hatch that could be locked out by the setting you were trying to fix would not
  be one.
- **Changed: the two gamepad rows became one switch.** *Game controller* and
  *BLE gamepad* sat next to each other on a 172 px screen offering what reads as
  the same thing twice. They were not the same thing, but the difference was a
  *transport detail* — precisely the kind of thing a menu must not ask someone
  to hold in their head. The HID one wins on every axis that matters from the
  device's side (no daemon, no Wi-Fi, no loopback, and it is the only input path
  a page served over **https** can use at all), so **BLE gamepad** is now a
  single **on/off** row and the daemon-driven mode survives only where it
  belongs: as something the Mac asks for over the link (`G|1`), never as a menu
  item.
- **Changed: the gamepad switch is remembered, across a screen sleep and across
  a reboot.** It was an *action* before — somewhere the device went — and since
  "power off" here is deep sleep and waking re-runs `setup()` from the top,
  every sleep quietly handed a paired controller back to being a conductor. You
  found out mid-level, with the Mac still listing "Claude Mate" as a connected
  gamepad that had stopped sending anything. It is now a stored preference: on
  means the device **is** a gamepad until you say otherwise, off means it is the
  conductor and the daemon link comes back. Two consequences worth stating
  because both are deliberate: the switch is written to NVS **immediately**
  rather than on the usual 1.5 s deferred timer (a cell pulled in that window
  could otherwise leave the switch and the device disagreeing across a power
  cycle), and **`G|0` no longer revokes it** — a browser tab closing on the Mac
  must not override a standing instruction from the person holding the device.
  The two-second hold of the 4th button, or the row itself, is what turns it off.
- **Added: `docs/POWER.md`**, and it is deliberately incomplete. The issue asks
  for the measured idle draw documented next to the Wi-Fi number, and **neither
  number has been taken** — so the table says so in as many words, states the
  expectation *before* measuring so it can be checked, and gives the method in
  enough detail that two people's readings can be compared (meter in the battery
  lead, backlight off, both transports back to back on the same cell). A power
  page full of plausible figures nobody measured is worse than an empty one,
  because it stops anyone from measuring. It is also honest about the ceiling:
  stopping the advertiser cuts the *radio's* share, not the CPU's — this
  firmware never light-sleeps, because the display, the LED engine and the
  button poll all want the loop running — and the backlight remains the budget.
- **Measured: the BLE transport costs 9,008 bytes of flash and 2,848 of RAM**,
  against the same sketch built without it (1,320,866 → 1,329,874 B; 55,536 →
  58,384 B). That is cheap because the BLE stack was **already linked in** for
  the HID gamepad: the ~290 KB was paid for once and this is the second thing to
  use it. The sketch sits at 42% of the 3 MB app partition.
- **Added: `tools/test_ble_link.py`**, which starts with the check the compiler
  cannot do: the service and two characteristic UUIDs live in two files, in two
  languages, and a typo in one produces a device that advertises forever and a
  daemon that scans forever with **neither side reporting anything wrong**. The
  rest drives the real `BleLink` against a fake `bleak` injected before the lazy
  import — the handshake and both ways of failing it, and line reassembly, since
  a notification boundary is *not* a line boundary and the device can pack two
  lines into one notification or split one across two. No radio, and no `bleak`
  install, so CI runs it unchanged.
- **Changed: `bleak` is an optional dependency and stays optional.** It is
  imported inside `--ble`, never at module scope, so a daemon without it starts
  and runs exactly as before and reports one clear line instead of a traceback.
  The daemon's only hard third-party requirement is still pyserial, which is a
  promise the README makes.
- **Changed: `LinkHub` holds a list of wireless transports** rather than a named
  TCP one. A Nano on a cable, a Wi-Fi board and a BLE board can all be attached
  at once and every one of them gets every frame — the fan-out deliberately does
  not short-circuit, since an `or` chain would stop at the first transport that
  took the bytes and leave the second device showing a frame from a minute ago.
- **Fixed, on hardware, four ways the link could die and stay dead.** All four
  were invisible to the test suite and to CI, and all four were found by
  flashing a board and using it:
  - **BLE does not come back in the same boot.** `BLEDevice::deinit(true)` does
    not fully release the controller and every `init()` after it fails —
    deterministically. The first cut swapped the stacks in place, which worked
    exactly once per boot in each direction, so flipping SETTINGS → Link twice
    (what anyone does while looking at a new setting) left the device with **no
    link at all**: no advertising, no Wi-Fi, no retry, and `ble : OFF` visible
    only over a cable a cordless device is probably not attached to. Anything
    that takes the BLE stack down now **reboots** to bring it back, behind a
    screen that says which link it is switching to. The transport is in NVS, so
    three seconds is the whole cost. The same applies to turning the gamepad off
    on a BLE build — the pad and the link are two roles on one controller.
  - **A failed start was silent and permanent.** `blelink.h` now remembers it
    was asked to be up, retries, and when the retries are spent says so
    (`stuck()`) so the sketch can reboot rather than sit there being nothing.
  - **`I|BLE` could not restart a dead stack**, because `setTransport()`
    returned early when the value had not changed — so the one command that
    looked like it should fix it was a no-op.
  - **The daemon never noticed a device that vanished.** bleak's
    `disconnected_callback` did not fire when the board rebooted, and the daemon
    went on believing it was connected **for ninety minutes** — `has_clients()`
    true, frames written into nothing, and no scan ever started again. A
    transport whose recovery depends on one notification it does not control has
    no recovery, so the session loop now asks `is_connected` every tick and
    counts consecutive failed writes, which is the same thing `NetLink` has
    always done from the other direction. Recovery measured at ~6 s.
  `tools/test_ble_link.py` gained a regression test for the last of those, which
  also meant giving the fake client an `is_connected` the real one has. One of
  its own checks turned out to be environment-dependent — "bleak missing" passed
  only because bleak happened not to be installed, and quietly stopped testing
  anything the day it was; it now blocks the import outright.

### 2026-08-08 — SHIP IT level 2: M2 · SCAFFOLDING, and the product manager

- **Added: level 2 of SHIP IT**, playable in the web edition through a new
  MILESTONE row on the start screen. It unlocks once M1 has shipped on any
  tier — the row says so, and refuses until then — and the M1 finish screen
  announces the unlock. The sizing is arithmetic rather than
  taste: the crossing is 126 tiles against level 1's 105 — **20% longer**, so
  the same per-step drain prices a straight run at 1.2× the tier's walk cost
  (the start screen now quotes the real number per level) — and hazard density
  rises about **5%** (18 enemies and 10 gaps over 126 tiles, against 14 and 8
  over 105). Per-hit costs per tier are unchanged, so a chosen difficulty
  stays the difficulty chosen. The shape is the one `docs/GAME.md` §4 promised
  for M2: rising streaks — scaffolds, catwalks, perches and one pyramid that
  cannot be walked around.
- **Added: the product manager**, the game's third enemy and its most
  expensive. It patrols its floor at 0.7× the tier's enemy speed and *chases
  on sight* at 1.35×, capped at 1.2 px/step — deliberately below the 1.45
  walk, because a meeting you cannot outrun is not a mechanic, it is a wall.
  It cannot be stomped, and a collision costs the tier's priority-change
  penalty **plus 2½ days** (4½/4½/5/5½/5½ across the tiers), a 60 px shove
  and 90 frames of invulnerability. It gets a codex card like everyone else.
  Knockbacks are now swept against terrain instead of teleporting — the
  review found that a raw 46 px shove from the priority change at level 2's
  col 112 could pass through the pyramid's wall into its sealed hollow, a
  pit no jump can leave. It turns out to fix **level 1** too, which ships:
  at the priority changes on cols 31 and 93, 18 of the 172 standing positions
  that register a hit used to shove the player *inside* the staircase block
  behind them — from x=484 the old shove landed at 438, buried in terrain,
  where the swept one stops at 447 flush against the wall. That is the main
  walking floor, so it was the ordinary case rather than a corner of the map.
- **Added: `tools/test_levels.py`**, the reachability checker the design doc
  demanded after level 1's first draft shipped with all seventeen PRs
  unreachable: a breadth-first search over standing positions using only the
  measured jump budget, run in CI for every level, failing if the flag or any
  pull request cannot be reached.
- **Changed: `tools/gen_level.py` now generates every level**, not just the
  first. Each firmware header owns its geometry and actors; the palette and
  sprites are merged game-wide (the character lives in `level_01.h`, the
  product manager in `level_02.h`) and emitted into every generated module,
  with a duplicate definition anywhere being a hard error.
- **Changed: the device engine plays the campaign too**, not just level 1.
  `ship_it.h` was bound to level 1 at *compile* time — `LVL1_MAP` inside
  `solid()`, `LVL1_COLS` in the camera clamp, `LVL1_BUG_COUNT` as an array
  size — and now reads every level through a campaign table, so nothing in the
  simulation or the renderer knows which level it is playing and level 3 is a
  header plus one row. Actor arrays are sized to the worst level at compile
  time, so switching milestone never allocates; `ROWS` and `TILE` are still
  shared by every level and now `static_assert` it. The device gets the same
  MILESTONE row, the same lock, the product manager and its codex card, the
  per-level walk cost (M2 quotes 6 days where M1 quotes 5, on SPRINT), and the
  swept knockback. The start screen fits a fourth row by moving the title block
  up 6 px and tightening the row pitch from 32 to 27.
- A host harness compiles that device engine and drives it with the panel and
  NVS stubbed, which is how the layout of a screen CI cannot see is checked at
  all: 1840 drawn strings across every screen, both levels and all five tiers,
  none of them off the 320×172 panel and none colliding on its own row. It also
  pins the two engines to the same pixel — the swept shove lands on 447 on
  level 1 and 1775 on level 2 in the browser *and* in the firmware.

### 2026-07-31 — A battery indicator that stops lying, and a menu that responds

- **Changed: three segments instead of a battery percentage** (3 green, 2 amber,
  1 red). Reported from the bench: unplug a full cell and the display falls from
  100 % to 70–80 % within minutes. Every number was honest and the display was
  still a lie — 4200 mV is the *charger's* constant-voltage point rather than the
  cell's charge, a Li-ion just off charge sheds surface charge over tens of
  minutes, and at ~9 mV per percent the ADC noise on an unfiltered divider is
  worth whole points. A number invites you to trust its last digit. Behind the
  segments: 60 mV of hysteresis (fall only — rise on touch), a 45-second hold so
  no Wi-Fi burst or backlight step can move it, and the EMA slowed from 1/8 to
  1/16. The exact percentage and millivolts stay in `?` and on the About page,
  because diagnosis wants the number and a glance wants the shape.
- **Fixed: the menu was close to unusable with no daemon.** `TCPClient::connect()`
  and `MDNS.queryService()` both block, and both are called from the loop that
  polls the buttons — in DIALING that was roughly three quarters of every second
  with the firmware unable to read a pin, so a press *and* its release could land
  inside one window and be dropped rather than delayed. Reconnection is now held
  while a firmware-local screen is up, backs off 2 s → 30 s while the daemon is
  absent, and the dial timeout dropped 1500 → 600 ms.
- **Added: "Mac sound" in settings**, with a new `O|<KEY>|<value>` device →
  daemon verb to carry it. The device has no speaker, so this is the one
  preference whose effect happens on the Mac; it is re-sent on every connect
  because the daemon keeps no per-device state. Unknown keys are ignored on both
  sides, so old and new interoperate in either direction.
- **The settings page scrolls**, since five rows fit and there are now six.

### 2026-07-30 — Wi-Fi setup stops being a dead end, and the Mac can beep

- **Fixed: an empty token box erased the stored token.** The setup portal wrote
  it unconditionally, so the obvious thing to do on a return visit — fill in the
  Wi-Fi password and nothing else — silently wiped the shared secret, after
  which the device could never complete the handshake and reported only that it
  was not connected. Empty now means **keep**; clearing is a deliberate
  checkbox, or `X|WIPE`. The old docs warned "re-enter it every time", which was
  an admission the behaviour was wrong rather than a fix.
- **Fixed: every connection failure looked identical.** `drop(why)` discarded
  its reason (`(void)why;`), so a wrong token, a missing token, a daemon that
  is not listening and a lost network all presented as the device quietly
  cycling back to `dialing…`. The reason now shows on the bottom line for 20 s.
- **Changed: `--tcp` generates a token instead of refusing.** Failing closed was
  aimed at the right danger — an *unauthenticated* listener — but caught the
  wrong thing: the portal asks for a token, and the only way to have one was to
  already know to create the file by hand. It now writes a 32-byte secret to
  `~/.config/claude-mate/token` (0600, create-exclusive, never overwriting an
  existing file) and prints it for typing into the portal. It still refuses when
  a token can neither be read nor created, which is the real fail-closed case,
  and `test_net_link` pins both halves (23 → 28 checks).
- **Added: `--sound`** (off by default). Plays a macOS alert sound on the same
  transition that drives the LED — one truth, now three renderings: rhythm,
  colour, sound. One-shot, never looping: light is ignorable and a beep is not,
  and an alert that repeated until acknowledged would be a smoke alarm. The
  device itself stays silent — the ESP32-S3 has no DAC, and the board's 3.3 V
  rail is a linear LDO with the backlight on a resistor-limited MOSFET, so there
  is no switching node any firmware trick could make audible.

### 2026-07-30 — A menu on the 4th button, and a screen that turns itself off

**ESP32-S3 only, and nothing outside its firmware changed** — no protocol
change, no daemon change, and the Nano build untouched. All of this is
firmware-local because none of it is about a session: it is about the piece of
hardware, which the daemon has no business knowing.

- **Added: three gestures on the 4th button.** A tap still opens the terminal
  mirror in the (now named) **CONDUCTOR** view; a **double-tap** opens an
  on-device menu; the 2 s hold still means long sleep. The tap is now deferred
  by 300 ms, because a first tap is not yet knowably a single one — a cost paid
  by the least latency-sensitive of the three on purpose, since the mirror
  already waits a daemon round-trip. 300 ms is the daemon's own
  `DOUBLE_CLICK_S`, so both double-taps on the device want the same rhythm.
- **Added: a menu** — CONDUCTOR · SETTINGS · ABOUT · WI-FI · SLEEP, as a
  horizontal strip rather than a list, because a 320×172 panel gives a list a
  fifth of its width and runs it out of height at five rows. While the menu is
  up PREV/GO/NEXT are handled on the device and never emitted, so the queue
  cannot move while you are aiming at a row. **ABOUT** puts the serial `?`
  readout on the glass, which is the only place it can be read on a cordless
  device with no console attached, and **WI-FI** starts the setup portal —
  previously reachable only by holding BOOT through power-on or sending `Z`.
- **Added: screen sleep**, off after 1/2/5/10/30 min and only when nothing is
  waiting on you, judged from the frame the device already has (flashing name
  row, any lowercase fleet letter, or a *looping* LED — the daemon drives that
  from exactly "worst unacknowledged alert"). An alert turns it back on. A
  `working` fleet deliberately does not hold it on, and neither does `NO LINK`:
  a dead daemon must not be able to burn the cell flat, which is what would
  happen the moment you carried the device out of Wi-Fi range. Only the
  backlight goes off — `displayOff()` would save another milliamp and put the
  wake path one command from the dead-panel failure this firmware already warns
  about twice. Defaults to **off**, so nobody's screen starts going dark because
  they took an update.
- **Added: settings**, in their own NVS namespace so a factory reset can choose
  what it destroys — screen sleep, backlight (5 steps, non-linear in duty
  because equal duty steps feel like one huge jump then four identical ones),
  alert LED with a genuine **off** (a 7 Hz red strobe is right at a desk and
  wrong in a bedroom, and the alert still arrives through the name row), flip
  screen, and factory reset. Writes are deferred 1.5 s, so holding NEXT through
  the brightness steps costs one flash write instead of five.
- **A press on a dark screen only wakes, and is swallowed.** Phone convention,
  but for a specific reason: GO raises a terminal window, so obeying a press
  aimed at a screen you cannot read would occasionally yank you to the wrong
  session — the exact thing this device exists to prevent.

### 2026-07-28 — Iteration 2: a cordless ESP32-S3 companion with a colour screen

**The Arduino Nano build is unchanged and still supported.** Both devices speak
the identical protocol and can be connected at the same time; everything new
sits behind verbs the Nano never sends.

- **Added: an ESP32-S3 Wi-Fi companion** (Waveshare ESP32-S3-LCD-1.47B) —
  172×320 colour LCD, four buttons, a WS2812 whose colour *and* rhythm encode
  the alert class, and Li-ion operation with an on-screen battery gauge. It
  reaches the daemon over TCP, discovered by mDNS and authenticated with a
  nonce/HMAC handshake in which the token never crosses the wire. Config lives
  in NVS and survives a reflash; an unprovisioned board raises a Wi-Fi setup
  portal. See [`firmware/README.md`](firmware/README.md).
- **Added: a live terminal mirror.** The fourth button opens the selected
  session's *actual terminal* on the device, refreshed ~1×/s, with PREV/NEXT
  scrolling it. It reuses the PTY wrapper's existing pyte mirror and the
  per-session control socket the daemon already used for `focus`, so there is no
  new channel and no cost when the view is closed. Wrapped sessions only — a
  hook-only session has no PTY and says so. Terminal contents cross the same
  **plaintext** TCP link as everything else, which is a materially larger
  exposure than a status string.
- **Added: `firmware/flash_s3.sh`.** `arduino-cli upload` cannot flash this
  board: its download mode ignores the DTR/RTS straps, the USB link stalls
  partway through any large transfer, and a hard reset lands back in the
  bootloader looking exactly like a dead board. The script works around all
  three and verifies every piece with a device-side hash.
- **Added: `firmware/README.md`**, which the S3 sketch had been citing while it
  did not exist. Covers both builds, board options, wiring, flashing and
  provisioning.
- **Added: power off.** Holding MIRROR for 2 s puts the device into deep sleep;
  a tap wakes it. "Off" is deep sleep rather than zero — the WS2812 has no
  shutdown pin and idles ~1 mA whenever the rail is up, which dwarfs the ~8 µA
  the S3 draws asleep, so expect roughly a month of standby on a 14500 and use a
  switch in the battery lead if you need true zero. Waking reboots; NVS config
  survives, and `?` reports which kind of boot it was.
- **Protocol:** new `M|` lines (daemon → device) carry the mirror; new `B|M`
  (mirror button) and `B|F` (direct FOLLOW toggle) are accepted from devices
  that have the buttons for them. Additive in a dispatch that already ignores
  unknown verbs, so old firmware and this daemon interoperate in both
  directions.
- **Fixed: a wireless device starved a USB one.** `LinkHub.is_open()` answers
  *"is any device reachable"*, and `SerialMaintainer` gated reconnection on
  exactly that — so once an ESP32 linked, a Nano that dropped (or was plugged in
  afterwards) was never reopened and sat on `NO LINK`. Fixing the gate alone
  would have broken the other case, because the retry path `continue`d past the
  keepalive ping; both are fixed, and `test_net_link` grew a phase pinning the
  invariant (20 → 23 checks).
- **Added: the printed enclosure for the S3** —
  [`assets/3d-model/claude_mate_s3.stl`](assets/3d-model/claude_mate_s3.stl),
  ≈ 55 × 43 × 23 mm, cut for the 1.47" LCD on a raised shelf, four **Kailh Choc
  low-profile (1350)** switches, USB-C, and a tube on the back that takes the
  14500 cell behind a two-screw base plate. New build photos in
  [`assets/photos/`](assets/photos/).
- **Docs:** the README opens on both devices and now carries a per-build bill of
  materials, an S3 pinout, the S3 screen sketch, the wireless-handshake flow and
  the terminal-mirror section; the landing page was rebuilt around iteration 2.

### 2026-07-26 — …and it leaves WIP again once that work is actually done

- **Fixed: the device stayed on WIP forever after the task finished.** The
  background-work tells added the day before are Claude's *transcript* text —
  printed once, never rewritten. A recap still reads `✻ Worked for 4s · 1 shell
  still running` long after that shell exited, and nothing scrolls it off while
  you are away from the keyboard, which is exactly when the device is all you
  can see. The daemon only alerts DONE on `working → idle`, so a session that
  never left `working` never buzzed at all.

  Measured on two 200-second recordings of live sessions, one frame per second:

  | Session | Work ends | Old detector | New detector |
  |---------|-----------|--------------|--------------|
  | backgrounded shell (`sleep 45`) | t=57s | `working` on all 143 remaining frames | `idle` from t=60s |
  | background agent (Explore) | t=26s | `working` on all 154 remaining frames | `idle` from t=26s |

  The fix is structural rather than a timeout: the three tells that live in the
  transcript (the `Waiting for N … to finish` banner, the turn recap's
  `· N … still running` suffix, the task panel's `N in background` counter) now
  count only while nothing Claude printed **after** them has superseded them.
  When the work really ends Claude says so on a new line — `⏺ Background command
  … completed (exit code 0)`, `⏺ Agent … finished · 9s` — so a tell expires on
  the very frame its work does. Turn-end furniture that legitimately follows one
  (the task panel, the `❋ recap:` line, a usage warning) expires nothing.

- **Fixed: a finished subagent kept the session on WIP for as long as the agents
  panel stayed up** (27s in the recording). Claude leaves the completed agent's
  row on screen with its final tally, `◯ Explore  Count .h files … 9s · ↓ 7.5k
  tokens`, and `↓ 7.5k tokens` is textually a live activity meter. The meter is
  now read only *above* the prompt box, which is where Claude's own foreground
  status line renders; the agents panel below it is excluded.

- **Fixed: the live in-flight chip is now read below the prompt box** rather
  than from "the last four non-empty lines". That is Claude's own chrome, so
  neither the conversation nor the text you are typing (`kill the 3 shells`) can
  reach it, and the chip is still found when an agents panel pushes the hint row
  further up.

- **Fixed: two shapes that fired on ordinary prose.** The banner now has to name
  the banner's own nouns, so Claude writing *"⏺ Waiting for 2 CI jobs to finish
  before I merge."* no longer pins the device (prose is permanent transcript, so
  that pin never lifted). The `N in background` counter now has to sit alone on
  its line, so a right-aligned table column reading `build   2 in background`
  does not match. The banner's phrases (`background agent`, `agent to finish`,
  `workflow to finish`, `tool to finish`) are gone from the tunable `busy` list
  in `patterns.json`: as bare substrings they carried neither the structural
  shape nor the freshness gate, and the structural regex already covers them.

- **Fixed (hook): a `Stop` payload listing an already-finished background task
  no longer downgrades DONE to `working`.** Each `background_tasks[]` entry
  carries its own `status` (verified against real payloads:
  `{"type":"subagent","status":"running",…}`), and Claude Code fires another
  `Stop` with an empty array once the work lands. Counting a terminal entry
  would suppress a DONE that no later event ever corrects. An entry with **no**
  status is still counted, so a build that omits the field behaves as before.

### 2026-07-25 — A turn that ends with background work no longer reads IDLE

- **Fixed: the device showed IDLE (and buzzed a premature DONE) while a
  background dynamic workflow, background agents, a backgrounded shell, a
  monitor or an MCP task were still running — or still queued.** Claude's reply
  finishes and the prompt comes back, but the session is not done; the wrapper
  only recognised one of the three tells Claude renders for that, and only in
  its unwrapped form.
- **PTY wrapper — three new background-work signals:**
  - the turn recap's suffix — `✻ Crunched for 1m 56s · 1 shell still running` —
    which covers the work the banner does not name;
  - the **live in-flight chip** in the hint row under the prompt box
    (`⏵⏵ bypass permissions on · 1 shell · ← for agents · ↓ to manage`) — the
    tell that also covers **queued** work and scheduled loops, and that keeps
    updating after the transcript lines scroll away. It is read only in the
    footer region, where conversation text cannot reach;
  - the same fact on Claude's compact status row (`N in background`).
  The `Waiting for N … to finish` banner is now also matched when it **wraps**
  in a narrow terminal. A to-do left `in progress` in the task panel is
  deliberately *not* a busy signal — it is a plan item, not a running task.
  Verified against frames captured from a live session: the exact idle frame
  that used to read `idle` now reads `working`.
- **Background work no longer masks "needs your input".** The generic
  question-picker footer is vetoed by the **foreground spinner only** — a
  session that keeps a shell or a workflow running still reports `waiting` when
  it asks you something.
- **Hooks — `Stop` now reports what Claude tells it.** The payload's
  `background_tasks` (running/pending background work) and one-shot
  `session_crons` (a `/loop` tick, a `ScheduleWakeup`, a one-shot cron — this
  turn continuing later) downgrade `done` to `working`; the finish is reported
  by the next `Stop` that lands with nothing in flight. Recurring crons are not
  counted, so a session that merely owns a daily schedule still reports DONE.
  Both fields are optional — older Claude Code builds behave as before.
- **Added `tools/test_hook_state.py`** (18 checks over the hook's wire line per
  payload, via a new `CLAUDE_MATE_DRY_RUN=1` that prints the line instead of
  sending it) and **15 new `tools/test_detect.py` cases**, including a frame
  captured verbatim from a live session, the input-precedence guards, and the
  false-positive guards (prose about work "still running" or "N in background",
  chip-shaped text in the conversation rather than the hint row, and the
  reported screenshot itself: an in-progress to-do with nothing actually in
  flight must stay IDLE).

### 2026-07-07 — Project goal, non-commercial license, enclosure + photos

- **Repositioned** around the actual goal: cutting the cognitive overload of
  orchestrating many Claude Code agent sessions at once — across different
  accounts and projects. Added a **Roadmap**: iteration 1 is Arduino + macOS
  (this repo); iteration 2 is a wireless **ESP32 Wi-Fi** remote (no USB tether).
- **License changed from MIT to CC BY-NC 4.0** (Creative Commons
  Attribution-NonCommercial). Personal use and contributions are welcome;
  **commercial use is prohibited**. Covers the software, firmware, hardware
  design, 3D model, photos, and docs.
- **Added `assets/`** — photos of the built device and a printable 3D enclosure
  model (`assets/3d-model/claude_mate_v2.3mf`). The README now leads with a hero
  photo and an *Enclosure & 3D model* section.

### 2026-07-07 — Sticky selection

- **The selection is now fully sticky.** The ~10 s idle auto-surface is gone:
  the screen **never** switches tabs on its own. Alerts elsewhere announce
  themselves via the LED and their blinking fleet letters; you browse with
  PREV/NEXT.
- **FOLLOW's ► marker no longer overdraws the account name.** While FOLLOW is
  on, the daemon keeps the last two columns of the state row blank (the
  right-aligned account shifts left), so the play triangle has its own space.

### 2026-07-06 — Account profiles + on-device account & remaining-limit

- **Account profiles.** The PTY wrapper can run different terminals under
  different Claude accounts by pointing each session at its own
  `CLAUDE_CONFIG_DIR`. Every subdirectory of `~/.claude-accounts` is a profile;
  an interactive start shows an opt-in picker listing each profile with the
  email logged into it. `--account <name>` / `CLAUDE_MATE_ACCOUNT` selects one
  non-interactively; an already-exported `CLAUDE_CONFIG_DIR` always wins. With
  no profile dirs, nothing changes.
- **Device shows the account + remaining limit.** Each wrapped session reports
  which account it runs as (right-aligned on the state row) and how much of that
  account's plan limit is left as a chip on the model+effort row (`5h82%` = 82%
  of the 5-hour window, `wk31%` = 31% of the week — the tighter one shows). The
  wrapper reads the session's own OAuth token and polls Anthropic's usage
  endpoint read-only; it never refreshes or rewrites credentials.

### 2026-07-05 — Interface rewrite: one screen, one queue, three buttons

The device interface was rewritten from scratch — **one screen, one queue,
three buttons**:

- **UI modes are gone.** No SCROLL/LIST toggle, no carousel, no detail card, no
  mode long-press. The daemon keeps ONE **stable, alphabetically-ordered** triage
  queue (tabs never shuffle; urgency is tracked separately, for the LED + idle
  auto-surface only) and pre-renders ONE screen — four size-1 rows (name ·
  state+time+account · model+effort+remaining-limit · position+fleet strip);
  the firmware is a dumb one-frame renderer.
- **Buttons are PREV / GO / NEXT everywhere.** GO short = acknowledge + raise
  the shown window (WYSIWYG); GO **double-click** = toggle FOLLOW mode; GO long
  = acknowledge only; PREV/NEXT auto-repeat while held. A GO/ACK **stays on the
  tab** it acted on (no auto-switch); after ~10 s idle the display auto-surfaces
  the most-urgent unacknowledged alert at its stable position (else the first
  tab). _(The idle auto-surface was later removed on 2026-07-07.)_
- **Navigation never touches windows** (except in FOLLOW mode, which raises
  only). The old terminal-follow preview (collapse/expand on every navigation)
  is gone; the daemon never sends `collapse`.
- **Serial protocol simplified.** Down: `F|<flags>|<sel>|<r0>|<r1>|<r2>|<r3>` +
  `V|<kind>` + `P`. Up: `H` + `B|P` / `B|N` / `B|G` / `B|K`. The old
  `D|` / `S|` / `T|` / `I` lines and `B|1`..`B|5` are gone.
- **Firmware additions:** a boot splash, a **LINK LOST** screen after ~30 s of
  daemon silence, and an ~80 ms whole-panel invert blip on every accepted
  press. LED semantics are unchanged (START one-shot; INPUT / ERROR / DONE loop
  until acknowledged; OFF).
- The hook, the PTY wrapper, the socket protocol, and the wiring are unchanged
  (button *roles* renamed: D4 MODE → PREV, D2 SUBMIT → GO).

### 2026-06-29 — OLED + PTY wrapper + acknowledge model

A big iteration day. Highlights:

- **Hardware redesign:** dropped the stepper-driven status wheel; the device is
  now a **0.91" 128×32 OLED + micro vibration motor + 3 buttons**. The OLED shows
  a per-session status card (state + live timer + acknowledge dot). _(The
  vibration motor was later replaced by an indication LED on D8.)_
- **New PTY wrapper** (`bin/claude-mate-wrap`): wrap `claude` to read its **live
  TUI state** (errors, prompts, pickers, background-workflow "still busy") and to
  raise the **exact terminal** on FOCUS (by TTY). Safe to install as a global
  `claude` shim.
- **Per-session haptics + acknowledge model:** the motor buzzes for *each
  session's own* start/finish/block/error (`V|<KIND>`). The DONE and ERROR alerts
  **loop** in the firmware (waiting re-taps every ~10 s) until you FOCUS, which
  sends `V|OFF`; a finished turn stays "done" until seen. The OLED carries a
  blinking/hollow ack dot.
- **No blind auto-carousel:** the screen auto-surfaces the single most-urgent
  unacknowledged tab; NEXT/PREV browse manually and pause auto-surface ~10 s.
- **Tighter detection:** `patterns.json` (hot-reloadable), state matching scoped
  to the live status region (bottom ~20 lines) + footer-only picker phrases,
  option-pickers treated as **waiting**, and `usage limit reached` treated as
  **error**.
- **Live time-in-state** timer; gentle **looping** DONE/ERROR haptics (soft
  heartbeat / alarm) that stop on FOCUS via `V|OFF`; assorted reliability fixes
  (loop-idempotent sends, daemon-silence watchdog, handshake resend, nav-pause order).

[Unreleased]: https://github.com/vlgutv22/claude_mate/commits/main

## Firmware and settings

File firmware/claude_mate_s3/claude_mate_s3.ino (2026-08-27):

/*
 * Claude Mate - ESP32-S3 wireless firmware (main sketch)
 * =====================================================
 *
 * The cordless sibling of the Arduino Nano build: the same triage companion for
 * a fleet of Claude Code sessions, on a 1.47" colour LCD, talking to the daemon
 * over WiFi instead of a USB cable so it can sit anywhere on a battery.
 *
 * It speaks the SAME protocol, byte for byte (docs/PROTOCOL.md). The daemon
 * cannot tell the two devices apart, and both can be connected at once.
 *
 * THE INTERFACE: one screen, one queue, three buttons.
 *
 * The daemon keeps a STABLE, alphabetically-ordered list of sessions and
 * pre-renders ONE frame as four rows of at most 21 characters. This firmware is
 * a dumb renderer: it holds exactly one frame and draws it. All ordering,
 * selection, truncation and text layout live in the daemon -- the extra pixels
 * here buy TYPOGRAPHY and COLOUR, never a different information model.
 *
 *   +--------------------------------------------+
 *   | (wifi)  CLAUDE MATE               [ 87% ]  |  firmware-local status bar
 *   |--------------------------------------------|
 *   |  api-server                                |  r0 name, big, state colour
 *   |  WAIT   0:42                        work   |  r1 state tag + time (+acct)
 *   |  Opus 4.8 xhigh                    5h82%   |  r2 model + effort (+limit)
 *   |                                            |
 *   |  2/6  E  B  W  D  I                        |  r3 fleet strip; the active
 *   |  wifi 192.168.1.42                         |  tab sits in a filled box,
 *   |============================================|  unacked alerts BLINK
 *   +--------------------------------------------+  accent = worst state colour
 *
 * There are NO modes: the buttons mean the same thing at all times --
 *
 *     PREV          step the selection up the queue      (auto-repeats held)
 *     GO            short: raise that session's terminal window (+ack)
 *                   long : acknowledge the alert WITHOUT raising anything
 *                   double: toggle FOLLOW (the daemon disambiguates)
 *     NEXT          step the selection down the queue    (auto-repeats held)
 *     MIRROR        tap : open/close a live view of the session's TERMINAL
 *                   hold: power off (deep sleep); tap again to wake
 *
 * MIRROR is the one thing three buttons could not do. Acknowledging and FOLLOW
 * were already reachable through GO, so a 4th button spent on either would have
 * bought a shortcut; showing the actual terminal was not reachable at all. The
 * daemon pulls the rendered TUI from that session's PTY wrapper about once a
 * second and pushes it as M| rows, and while the view is open it reinterprets
 * PREV/NEXT as scroll -- so this firmware still has NO modes: it emits the same
 * verbs regardless and simply draws whichever rows arrive.
 *
 * POWER OFF is deep sleep, not zero: the WS2812 has no shutdown pin and idles
 * ~1 mA whenever the rail is up, dwarfing the ~8 uA the S3 draws asleep. That is
 * roughly a month of standby on a 14500 -- off in every practical sense, though
 * a switch in the battery lead is the only true zero. Waking REBOOTS (deep sleep
 * does not resume), so rejoining WiFi costs a few seconds; NVS config survives.
 *
 * Only WRAPPED sessions can be mirrored. A hook-only session has no PTY for the
 * daemon to read, and says so rather than showing a blank screen that would
 * look like an idle session.
 *
 * The onboard WS2812 replaces the Nano's single LED: the daemon's V|<KIND>
 * alert class picks both a COLOUR and a RHYTHM, and loops until acknowledged.
 *
 * THREE TRANSPORTS, ONE PROTOCOL
 *
 *   USB   native USB CDC at 115200. Plugged into the Mac the board is a drop-in
 *         Nano replacement -- the daemon's autodetect already globs
 *         /dev/cu.usbmodem*, so it just works with no daemon flags at all.
 *   WiFi  a TCP connection to the daemon's --tcp listener, discovered over mDNS
 *         and authenticated with a nonce/HMAC handshake. See netcfg.h.
 *   BLE   a GATT service the daemon's --ble central connects to, advertised in
 *         200 ms bursts four seconds apart and authenticated with the SAME
 *         nonce/HMAC handshake and the SAME token. See blelink.h.
 *
 * WiFi and BLE are ALTERNATIVES, never both: one 2.4 GHz radio, and sharing it
 * degrades both. Which one is a stored setting (SETTINGS -> Link, or I|BLE over
 * the cable), not a compile-time choice -- Wi-Fi remains right for a host that
 * is not on this desk, BLE for a device that is, and moving between them should
 * not need a toolchain.
 *
 * Input is accepted from USB AND the wireless one at once, but button events go
 * to only ONE (the wireless link when it is up, else USB) -- emitting on both
 * would make the daemon count every press twice.
 *
 * If nothing is heard for ~30 s the firmware stops any LED loop and replaces the
 * (stale) frame with a LINK LOST screen: a dead daemon is an honest, visible
 * state rather than a frozen display.
 *
 * CONFIG LINES (USB serial only -- provisioning is not something a remote peer
 * should be able to do, and these are not part of the wire protocol):
 *
 *     ?                     print the current config (never the token itself)
 *     W|<ssid>|<password>   set WiFi credentials
 *     S|<host>|<port>       set the daemon address (empty host = mDNS discovery)
 *     T|<token>             set the shared secret (must match the daemon's)
 *     I|WIFI  I|BLE         which radio carries the link (takes effect at once)
 *     X|WIPE                clear all stored config
 *     R                     reboot
 *     Z                     start the WiFi setup portal now
 *
 * Or hold BOOT while powering on to bring up the setup portal: the LCD then
 * shows an access point name and password to join from a phone.
 *
 * REQUIRED LIBRARY (Arduino Library Manager):
 *   - GFX Library for Arduino  (Arduino_GFX, by moononournation)
 *
 * BOARD: "Waveshare ESP32-S3-LCD-1.47" with USB Mode "Hardware CDC and JTAG",
 * USB CDC On Boot enabled, and a partition scheme of at least 3 MB app
 * (WiFi + display does not fit the default 1.2 MB). See firmware/README.md.
 *
 * PIN MAP, LAYOUT GEOMETRY AND PALETTE: board_s3.h
 * WIFI TRANSPORT, CONFIG STORAGE AND SETUP PORTAL: netcfg.h
 * BLE TRANSPORT (duty-cycled advertising + GATT): blelink.h
 * THE DEVICE AS A BLUETOOTH HID GAMEPAD: blepad.h
 */

#include <Arduino_GFX_Library.h>
#include <esp_sleep.h>
#include <esp_system.h>        // esp_reset_reason(): a crash-reboot and a wake
                               // from deep sleep are indistinguishable without
                               // it, and they are different bugs
#include <driver/rtc_io.h>
#include "board_s3.h"
#include "battery.h"       // the gauge's arithmetic, so a host can test it
#include "netcfg.h"
#include "settings.h"
#include "blelink.h"
#include "blepad.h"
#include "game/ship_it.h"

// ---- Display -----------------------------------------------------------------
// Drawn into an off-screen canvas and flushed in one go: the frame is rebuilt
// from scratch on every change, and without a buffer the clear-then-draw would
// be visible as a flicker once a second while the state timer ticks.
Arduino_DataBus *bus = new Arduino_ESP32SPI(LCD_DC, LCD_CS, LCD_SCK, LCD_MOSI,
                                            GFX_NOT_DEFINED);
Arduino_GFX *panel = new Arduino_ST7789(bus, LCD_RST, LCD_ROTATION,
                                        true /* IPS */,
                                        LCD_NATIVE_W, LCD_NATIVE_H,
                                        LCD_COL_OFFSET, LCD_ROW_OFFSET,
                                        LCD_COL_OFFSET, LCD_ROW_OFFSET);
Arduino_Canvas *canvas = new Arduino_Canvas(SCREEN_W, SCREEN_H, panel);
Arduino_GFX *gfx = nullptr;        // canvas, or the panel if the buffer failed
static bool buffered = true;

// ---- Wireless transport ------------------------------------------------------
// TWO radios' worth of transport, EXACTLY ONE OF THEM UP AT A TIME. The S3 has
// a single 2.4 GHz radio: running Wi-Fi and BLE together degrades both, and
// this device has no reason to. `transport` says which one this build is
// currently being, and it is a stored byte rather than a #define so a device on
// a desk can be moved between them without a cable (see netcfg.h).
MateNet net;
MateBle ble;
static MateTransport transport = LINK_WIFI;

// ---- Device settings (firmware-local; see settings.h for why) ---------------
MateSettings cfg;

// ---- UI mode -----------------------------------------------------------------
// CONDUCTOR is the triage view this device has always shown: the daemon's frame,
// its terminal mirror, and nothing of the firmware's own invention. It is named
// because it is now one of several things the screen can be, and because that is
// what the device does -- it conducts a fleet of agents the way a conductor
// conducts an orchestra, watching all of them so you only have to watch one
// surface.
//
// MENU and PAGE are entirely firmware-local. While either is up, PREV/NEXT/GO
// are handled HERE and never reach the daemon -- which is a real change to the
// old promise that "this firmware never learns that a mode exists". It has to
// be: forwarding a GO while you are aiming at a settings row would raise a
// terminal you were not looking at. The daemon simply sees no button events,
// needs no protocol change, and keeps its frame current the whole time, so
// leaving the menu is instant.
enum UiMode : uint8_t { UI_CONDUCTOR, UI_MENU, UI_PAGE, UI_GAME, UI_PAD,
                       UI_ACTIONS, UI_ACCOUNTS };

// CONTROLLER MODE. The daemon turns this on (G|1) while a browser page is
// driving the device's buttons, and off (G|0) when the page goes away.
//
// It exists because the ordinary button semantics are unplayable as a gamepad,
// and not by a little: pollNavBtn debounces for 40 ms, then waits 400 ms before
// auto-repeating, then emits one event every 200 ms. That is correct for a
// selection list and it means a held direction moves you once, stalls for most
// of a second, then stutters. Reported as "huge delay", and it was.
//
// Here the pins are read raw every loop and PRESS/RELEASE EDGES go up the link
// (B|+P, B|-P, ...), so the page knows what is held down right now, which is
// the only question a platformer asks.
//
// It is also the low-power screen. Nobody is looking at the glass while they
// play on a monitor, so the pad face is drawn ONCE and the backlight drops --
// a full flush is 110 KB over SPI, and doing that 30 times a second to render a
// screen nobody is watching is exactly the overuse this mode avoids.
static bool     padActive   = false;
static bool     padDirty    = false;   // only the pad's OWN changes redraw it
static uint8_t  padHeld     = 0;      // bitmask, for the on-glass key preview
static UiMode   padReturnTo = UI_CONDUCTOR;
static bool     padManual   = false;  // switched on here, not by the daemon
// Which way the presses leave the device. PAD_LINK is the daemon (serial or
// TCP, whichever is up); PAD_BLE is a standard HID gamepad and needs no daemon,
// no Wi-Fi and no loopback -- which is the only way the PUBLIC site can ever be
// driven by this hardware, since https cannot reach http://127.0.0.1.
enum PadVia : uint8_t { PAD_LINK, PAD_BLE };
static PadVia   padVia      = PAD_LINK;
static unsigned long padLastInput = 0;   // for the radio policy; see loop()
static bool     padWifiParked = false;
static unsigned long padWifiUpSince = 0;
static UiMode uiMode = UI_CONDUCTOR;

enum MenuItem : uint8_t {
  MI_CONDUCTOR, MI_SETTINGS, MI_GAME, MI_SLEEP
};
static uint8_t menuIdx = MI_CONDUCTOR;

enum PageId : uint8_t { PG_SETTINGS, PG_ABOUT };

// The ACTIONS sheet -- what the 4th button opens over the triage view.
//
// Everything here is done to the session ON THE GLASS, the same WYSIWYG rule GO
// follows, and every item is a thing you would otherwise have to turn to the
// laptop for. SEND CONTINUE is the reason it exists: a session that hit its
// 5-hour limit or took an API error is waiting for one word, and walking back
// to the keyboard to type it is the friction this device is supposed to remove.
//
// One press per item, no sub-menus: choosing WHICH account to switch to needs
// every profile's remaining usage, which lives on the Mac, so the device asks
// for "somewhere with headroom" and lets the wrapper decide.
enum ActRow : uint8_t {
  AR_VIEW, AR_PREVIEW, AR_CONTINUE, AR_NEWTERM, AR_SWITCH, AR_COUNT
};
static uint8_t actIdx = 0;

// The saved accounts the daemon knows about, pushed on every handshake. Five
// fits the sheet; a sixth would need scrolling and nobody has six logins.
#define ACCT_MAX   5
#define ACCT_NAME  14
#define ACCT_CHIP  7
static char    acctName[ACCT_MAX][ACCT_NAME + 1];
static char    acctChip[ACCT_MAX][ACCT_CHIP + 1];
static uint8_t acctCount = 0;
static uint8_t acctIdx   = 0;
// The account the USER chose, by name. The list is rebuilt in place whenever
// the Mac re-pushes it, and it always re-pushes at least once: names first,
// then the same names with their remaining-limit chips a network round trip
// later -- which arrives exactly while someone is standing at this picker
// waiting for those chips. Row numbers do not survive that; a name does.
static char    acctSel[ACCT_NAME + 1] = "";
static PageId  pageId  = PG_SETTINGS;
static uint8_t pageIdx = 0;          // selected row within the page
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
void loop() {
  static MateNet::State lastNetState = MateNet::OFF;
  static MateBle::State lastBleState = MateBle::OFF;

  // Hold off reconnection attempts while a firmware-local screen is up. Both
  // the mDNS browse and the TCP connect BLOCK this loop, so with no daemon to
  // find they stop the button poll for most of every second -- a press and its
  // release can land entirely inside one and be dropped, which made the menu
  // close to unusable exactly when you most need it (no link, so you have come
  // to the menu to fix something). The link is not wanted while you are in
  // Settings anyway, and it resumes the instant you leave.
  // ...but the GAME's start screen is an exception to the exception. The hold
  // exists because the mDNS browse and the TCP connect BLOCK this loop for most
  // of a second, which made the menu near-unusable with no daemon to find. In a
  // level that would be far worse -- a 600 ms freeze mid-jump. But the game's
  // only speaker is the daemon, so holding unconditionally means a link that
  // dropped before you pressed START stays dropped, and the whole run is silent
  // with no way to fix it short of leaving. Reconnecting is therefore allowed on
  // the start screen and the codex cards, where nothing is moving and a hitch
  // costs nothing, and forbidden the instant a level is running.
  // UI_PAD is exempt for the same reason the game's start screen is: the pad is
  // a still image, so a blocking browse costs nothing to look at -- and if the
  // link drops while the Mac holds the grab, nothing can send G|0 to release
  // it. Holding reconnection there would strand the device in controller mode.
  // ...and NONE of that applies to BLE, which is the quiet advantage of this
  // transport rather than a footnote to it. There is nothing here that blocks:
  // no mDNS browse with no timeout parameter, no 600 ms TCP dial. The duty
  // cycle is two comparisons against millis(). So the hold has nothing to hold
  // back, and a device on BLE keeps looking for its daemon while you are deep
  // in a menu -- which the Wi-Fi build cannot afford to do.
  net.holdReconnect(uiMode != UI_CONDUCTOR && uiMode != UI_PAD &&
                    !(uiMode == UI_GAME && game.idle()));
  net.poll();
  net.applyPendingConfig();
  ble.poll();
  // The backstop. ble.poll() retries a start that did not take, and stuck()
  // means it has run out of tries -- which on this chip means the controller is
  // not coming back without a reboot. Doing nothing here is what the first cut
  // did, and it presented as a device that had quietly stopped having a link at
  // all, with `ble : OFF` visible only over a cable it was probably not
  // attached to. A reboot is three seconds and the transport is in NVS.
  if (ble.stuck()) restartWithNotice("LINK RESTART", "ble");
  pumpUsb();
  pumpNet();
  pumpBle();
  pollButtons();
  pollPadRadio();
  pollLed();
  pollBattery();
  blepad.setBattery(battPercent);           // the HID Battery Service macOS
                                            // already reads; no-op unless the
                                            // pad stack is actually up
  pollHibernate();
  cfg.commit();                             // deferred flash write, if any

  unsigned long now = millis();

  // The factory-reset confirmation disarms itself. An armed wipe left sitting on
  // the glass is a trap for the next person who picks the device up looking for
  // the battery percentage.
  if (resetArmedMs && (now - resetArmedMs) >= RESET_ARM_MS) {
    resetArmedMs = 0;
    requestRender();
  }
  if (wifiArmedMs && (now - wifiArmedMs) >= RESET_ARM_MS) {
    wifiArmedMs = 0;
    requestRender();
  }
  // An un-confirmed connection preview reverts. A row left reading "wifi?" on a
  // device that is still on BLE is a lie that survives until someone presses
  // something, and the someone is usually not the person who left it there.
  if (connTouchedMs && (now - connTouchedMs) >= RESET_ARM_MS) {
    connTouchedMs = 0;
    requestRender();
  }

  // ---- pairing ------------------------------------------------------------
  // A daemon asked to enrol us. Raise the question on the glass; the buttons
  // answer it (see onButton) and it expires on its own, because an offer left
  // standing on a device nobody is near is an offer to whoever passes next.
  if (ble.pairRequested() && !pairAskedMs) {
    // STAMPED FROM `now`, NOT A FRESH millis(). `now` was read at the top of
    // this iteration, so a later reading is a few microseconds AHEAD of it --
    // and the unsigned `now - pairAskedMs` below then underflows to ~4.29e9,
    // which is comfortably >= PAIR_ASK_MS. The prompt would answer itself, with
    // "no", in the same loop pass that raised it. The same trap as the `| 1`
    // sentinel bugs elsewhere in this file, arrived at from the other side.
    pairAskedMs = now ? now : 1UL;  // 0 is the sentinel; never stamp it
    wakeScreen();                   // a question nobody can see is a no
    Serial.println("pair: asked");
    requestRender();
  }
  if (pairedNoticeMs && (now - pairedNoticeMs) >= PAIRED_NOTICE_MS) {
    pairedNoticeMs = 0;
    requestRender();
  }
  if (pairAskedMs) {
    // WITHDRAWN. The peer that asked can vanish -- it drops, or the link times
    // it out -- and blelink clears the request when that happens. Leaving the
    // question on the glass would mean answering into a connection that no
    // longer exists, and a GO press landing somewhere the user did not expect.
    if (!ble.pairRequested()) { pairAskedMs = 0; requestRender(); }
    else if ((now - pairAskedMs) >= PAIR_ASK_MS) answerPairing(false);
    else {
      // ONE REDRAW PER SECOND, NOT ONE PER PASS. This used to call
      // requestRender() unconditionally, and the throttle below does not catch
      // it -- `quiet` is true on essentially every pass during a prompt -- so a
      // pairing question cost a full 110 KB canvas rebuild and SPI flush about
      // thirty-five times a second for its whole 45 s life, to animate a
      // countdown that changes once a second. It also forces the backlight back
      // on, and any peer in radio range can re-arm it indefinitely on a board
      // with no token.
      //
      // Ticking on the DISPLAYED VALUE rather than a fixed 1000 ms gate: a
      // fixed gate drifts by about one render against the countdown's own
      // second boundary, so over 45 ticks it visibly skips a number.
      unsigned long left = (PAIR_ASK_MS - (now - pairAskedMs)) / 1000;
      static unsigned long lastLeft = ~0UL;
      if (left != lastLeft) { lastLeft = left; requestRender(); }
    }
  }
  // The token the daemon granted after we said yes. The BLE stack took it live
  // already -- that is what let the handshake straight after it succeed -- so
  // this is only the durable half. Doing it here rather than on the BLE task
  // keeps every NVS write on the main loop, where the rest of them are.
  {
    String granted;
    if (ble.takeGrantedToken(granted)) {
      net.setToken(granted);
      Serial.println("paired: token stored");
      pairedNoticeMs = now ? now : 1UL;   // stamped from `now`; see pairAskedMs
      requestRender();
    }
  }
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

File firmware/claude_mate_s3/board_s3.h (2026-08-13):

/*
 * Claude Mate - ESP32-S3-LCD-1.47 board definition
 * ================================================
 *
 * Everything hardware- or geometry-specific about the wireless companion lives
 * here, so the sketch itself is about the PROTOCOL and the UI, not about pins.
 *
 * TARGET BOARD: Waveshare ESP32-S3-LCD-1.47B, an ESP32-S3R8 (dual core, 8 MB
 * OPI PSRAM, 16 MB flash) with a 1.47" 172x320 IPS LCD on an ST7789, a WS2812
 * RGB LED, a TF-card slot and native USB. The B revision also carries a QMI8658
 * 6-axis IMU and battery charging, neither of which this firmware uses.
 *
 * The LCD pins are NOT in the Arduino core's variant file (which only defines
 * PIN_RGB_LED and the header pins), so they are spelled out below. They match
 * the Waveshare schematic and the values the TFT_eSPI community settled on.
 *
 * The two revisions differ in EXACTLY ONE pin: the backlight is GPIO 46 on the
 * -1.47B and GPIO 48 on the original -1.47. See LCD_BL below -- getting it wrong
 * costs hours, because nothing looks broken except that the screen stays dark.
 *
 * WIRING YOU ADD (the bare board has only BOOT + RESET):
 *
 *   FOUR buttons, each INPUT_PULLUP with its other leg to GND. Physical layout
 *   left -> right, in ascending GPIO order so the wiring reads like the row of
 *   switches under the thumb:
 *
 *       PREV -> GPIO 3    GO -> GPIO 4    NEXT -> GPIO 5    MIRROR -> GPIO 6
 *
 *   All four are free on this board -- an ADC sweep of GPIO 1-10 found every one
 *   of them floating, with only the battery sense on GPIO 1 driven. BOOT
 *   (GPIO 0) doubles as GO, so a board with nothing soldered to it yet is still
 *   usable.
 *
 *   GPIO 3 IS A STRAPPING PIN, but an inert one here. It selects the JTAG
 *   source, and that strap is only SAMPLED when EFUSE_JTAG_SEL_ENABLE is
 *   burned, which is not the factory default -- so on a stock chip the pin is
 *   an ordinary GPIO. Boot mode is decided by GPIO 0 and GPIO 46, neither of
 *   which is wired to a button, so no button held through a reset can strand
 *   the device in download mode. (Worth re-checking with `espefuse summary` if
 *   these boards ever ship with different eFuses.)
 *
 *   The 4th button is MIRROR: a tap opens a live view of the selected session's
 *   actual terminal on the glass, and another tap closes it. It earns the pin
 *   because it is the only action that was not reachable at all before --
 *   acknowledging and FOLLOW already live on GO's long-press and double-click,
 *   so putting either here would have spent a switch on a shortcut.
 *
 *   Deliberately tap-only: no auto-repeat (holding would flap the view on and
 *   off) and no long-press meaning. While the view is open the DAEMON
 *   reinterprets PREV/NEXT as scroll, so the firmware never learns that a mode
 *   exists -- it emits the same verbs either way.
 *
 *   Battery: NOTHING TO WIRE on the -1.47B. The board has its own charger and
 *   its own sense divider already landing on GPIO 1 (ADC1_CH0), so the gauge
 *   works with just a cell plugged into the battery header.
 *
 *   Waveshare does not publish the sense pin or the divider ratio for this
 *   revision, so both were measured: sweeping ADC1 (GPIO 1-10) with a cell
 *   attached, GPIO 1 read a rock-steady 1399 mV while every other pin wandered
 *   randomly between 40 and 1030 mV -- floating. 1399 mV against a LiPo that
 *   can only sit between 3.0 and 4.2 V means the divider is 3:1 (4.20 V), not
 *   the 2:1 a hand-built pair of equal resistors would give (that would imply
 *   2.80 V, under a LiPo's floor).
 */

#pragma once

// ---- LCD (ST7789, 172x320 IPS, hardware SPI) --------------------------------
#define LCD_MOSI      45
#define LCD_SCK       40
#define LCD_CS        42
#define LCD_DC        41
#define LCD_RST       39
#define LCD_BL        46      // backlight, active HIGH (PWM-dimmable). THIS PIN
                              // DIFFERS BY REVISION: 46 on the -1.47B, 48 on the
                              // original -1.47. Every other LCD pin is identical
                              // between them, so the wrong value here fails in a
                              // deeply confusing way -- the ST7789 is driven
                              // perfectly and the panel simply never lights,
                              // which reads as a dead board or a bad flash.

// The panel is 172x320, but the ST7789 controller is a 240x320 part: the 172
// visible columns sit in the MIDDLE of its memory, so every write needs a
// (240-172)/2 = 34 column offset or the image lands 34 px off and wraps.
#define LCD_NATIVE_W  172
#define LCD_NATIVE_H  320
#define LCD_COL_OFFSET 34
#define LCD_ROW_OFFSET 0
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

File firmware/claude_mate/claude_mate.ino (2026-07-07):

/*
 * Claude Mate - Arduino Nano firmware (main sketch)
 * ==================================================
 *
 * A USB hardware companion for triaging a fleet of Claude Code sessions.
 * This sketch drives a 128x32 SSD1306 I2C OLED, an indication LED (alert) and
 * three buttons. It speaks the daemon<->Arduino serial protocol over USB CDC
 * serial at 115200 baud, 8N1.
 *
 * THE INTERFACE: one screen, one queue, three buttons.
 *
 * The daemon keeps a STABLE, alphabetically-ordered list of sessions (tabs
 * never shuffle; urgency drives the LED + the blinking fleet letters only --
 * the screen never switches tabs on its own) and pre-renders ONE frame as
 * four size-1 rows:
 *
 *     +---------------------+
 *     |api-server           |   r0: session name -- flashes (inverts ~2.5 Hz)
 *     |WAIT  0:42           |   r1: state tag + time-in-state
 *     |Opus 4.8  xhigh      |   r2: model + effort
 *     |2/6 W B E D I        |   r3: queue position + one status LETTER per
 *     +---------------------+       session (E/B/W/D/I). An UNACKED alert's
 *                                   letter BLINKS (sent lowercase). The active
 *                                   tab's letter sits in a wide centred filled
 *                                   rectangle (letter knocked out). A ">"
 *                                   triangle by the state row = FOLLOW mode on.
 *
 * The firmware is a dumb renderer: it holds exactly one frame (3 text rows +
 * a flash flag) and draws it. All ordering, selection, truncation, and text
 * layout live in the daemon. There are NO modes: the buttons mean the same
 * thing at all times --
 *
 *     PREV (left)   step the selection up the queue      (auto-repeats held)
 *     GO   (middle) short: raise that session's terminal window (+ack)
 *                   long : acknowledge the alert WITHOUT raising anything
 *     NEXT (right)  step the selection down the queue    (auto-repeats held)
 *
 * The indication LED is driven entirely by the daemon via V|<KIND> lines: it
 * plays a status-distinct pattern for the worst UNacknowledged alert class
 * and loops until acknowledged. The firmware just plays the pattern.
 *
 * If the daemon goes silent for ~30s the firmware stops any LED loop AND
 * replaces the (stale) frame with a LINK LOST screen, so a dead daemon is an
 * honest, visible state instead of a frozen display.
 *
 * REQUIRED LIBRARIES (install via the Arduino Library Manager):
 *   - Adafruit GFX Library     (Adafruit_GFX)
 *   (the SSD1306 itself is driven by the bundled softssd1306.h)
 *
 * PIN MAP (Arduino Nano, ATmega328P):
 *   OLED SSD1306 128x32 (0.91") over SOFTWARE I2C (hardware SCL A5 was damaged):
 *     VCC -> 5V, GND -> GND, SDA -> A4, SCL -> A3  (bit-banged; see softssd1306.h)
 *     I2C address 0x3C (common alternative: 0x3D)
 *   Buttons (INPUT_PULLUP, other leg to GND) -- layout PREV | GO | NEXT:
 *     GO   button -> D2  (emits "B|G" on a short press: focus the shown
 *                        session; "B|K" on a long press: acknowledge only)
 *     NEXT button -> D3  (emits "B|N" on press; auto-repeats while held)
 *     PREV button -> D4  (emits "B|P" on press; auto-repeats while held)
 *   Indication LED (the sole alert output):
 *     LED          -> D8   (OUTPUT; LED + ~220-1k series resistor to GND). Blinks
 *                          the alert pattern.
 *
 * SERIAL PROTOCOL (115200 8N1, ASCII lines terminated by '\n', fields split '|')
 *   Daemon -> Arduino:
 *     F|<flags>|<sel>|<r0>|<r1>|<r2>|<r3>  the whole screen, pre-rendered as
 *                                        four size-1 rows (each up to 21 chars).
 *         flags = bitfield: bit0 = flash row 0 (the name) at ~2.5 Hz (unacked
 *                 alert); bit1 = FOLLOW mode (draw the play triangle by r1;
 *                 the daemon keeps r1's last two columns blank while set)
 *         sel   = column in r3 of the active tab's fleet letter (-1 = none);
 *                 that letter's cell is filled (lit square, letter knocked out)
 *         r0    = session name
 *         r1    = state tag + time-in-state (+ account, right-aligned)
 *         r2    = model + effort (+ remaining-limit chip, right-aligned)
 *         r3    = queue position + packed status letters, no separator (an
 *                 unacked alert's letter is LOWERCASE -> drawn uppercase but
 *                 blinking). r3 is the LAST field (the tokenizer stops at the
 *                 6th bar and takes the rest verbatim).
 *     V|<kind>                           LED alert control (light only):
 *                                        START one-shot start blink; INPUT /
 *                                        ERROR / DONE looping "until
 *                                        acknowledged" alerts (repeat until
 *                                        V|OFF); OFF darkens the LED now
 *     P                                  ping/keepalive (we reply K)
 *   Arduino -> Daemon:
 *     H                                  hello, sent once after boot/reset --
 *                                        the daemon answers with a full resend
 *     K                                  keepalive ack (reply to P)
 *     B|P  B|N                           PREV / NEXT pressed (or auto-repeat)
 *     B|G                                GO short press. Single = focus the
 *                                        shown session; DOUBLE (two within
 *                                        ~0.3s, disambiguated daemon-side) =
 *                                        toggle FOLLOW mode (PREV/NEXT then
 *                                        auto-raise the selected terminal).
 *     B|K                                GO long press (acknowledge only)
 *
 * NOTE: opening the USB serial port resets the Nano (~1.5s). That is why we emit
 * H once in setup() so the daemon can (re)send the full current state.
 *
 * RAM is tight on the '328P; we use fixed char buffers and the F() macro for
 * literals, and avoid String churn in loop().
 */

#include <Adafruit_GFX.h>
// Hardware I2C SCL (A5) was damaged, so the OLED runs on SOFTWARE I2C with SCL on
// A3 (a plain GPIO; the 328P's TWI is fixed to A4/A5 and can't be remapped) and
// SDA on A4. softssd1306.h is a drop-in Adafruit_GFX subclass, so all the drawing
// code below is unchanged. To go back to hardware I2C (A4/A5), restore the
// Adafruit_SSD1306 + <Wire.h> include and the matching constructor.
#include "softssd1306.h"      // defines OLED_SW_SCL=A3, OLED_SW_SDA=A4
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

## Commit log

2026-06-26 Initial scaffold: Claude Mate USB hardware status device
    Hardware companion that shows live Claude Code session status on an
    Arduino Nano + OLED + 3-color traffic light, with a button to focus the
    VS Code session that needs attention.
    - firmware/: main sketch (OLED carousel, traffic-light LEDs, 2 buttons)
    and a standalone selftest sketch
    - daemon/: Python daemon (Unix-socket server, serial auto-reconnect,
    carousel, traffic-light logic, focus via VS Code deep link + fallback,
    --mock mode) + tools/feed.sh test helper
    - hooks/: claude-status.sh fire-and-forget hook + settings snippet
    (UserPromptSubmit/Notification/Stop/StopFailure -> working/waiting/done/error)
    - install/: LaunchAgent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
    [claude_mate.ino, claude_mate_daemon.py, selftest.ino]
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2026-06-26 Add no-hardware tests for the daemon and installer merge
    - tools/test_e2e.py: fake Arduino over a PTY + stub `open` on PATH. Feeds real
    hook lines through the socket and asserts traffic light (G/Y/R), carousel
    cards, handshake resend, and that FOCUS opens the correct vscode deep link —
    all without hardware or launching anything. 8/8 assertions pass.
    - tools/test_settings_merge.py: verifies the installer's settings.json deep-merge
    preserves existing user settings/hooks and is idempotent. 6/6 pass.
    - docs/TESTING.md: document both as level -1 (run before any hardware).
    Verified: both tests pass locally against the committed daemon and snippet.
    [test_e2e.py, test_settings_merge.py]
2026-06-26 Replace traffic-light LEDs with a stepper-driven status wheel
    The overall indicator is now a motor-driven wheel showing one of four words
    instead of 3 LEDs. OLED carousel and FOCUS/NEXT buttons are unchanged.
    Words <- state (priority WTF > BLOCKED > WIP > FREE):
    FREE = idle/done/no sessions (also the home position)
    WIP = working
    BLOCKED = waiting (Claude needs your input)
    WTF = error (StopFailure / API 5xx / overloaded / timeout)
    - Protocol: drop `L|<color>`, add `D|<WORD>`. Daemon computes the word and the
    Arduino moves the wheel shortest-path, non-blocking.
    - Firmware: AccelStepper, driver selectable by one #define (default 28BYJ-48 +
    ULN2003 on D5-D8; A4988/NEMA17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
    [claude_mate.ino, claude_mate_daemon.py, selftest.ino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]
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2026-06-29 Replace stepper status wheel with a micro vibration motor + 3rd button
    Per hardware change: drop the stepper/ULN2003/endstop entirely; the OLED is now
    the sole visual status (word + cards), and a micro vibration motor gives haptic
    alerts. Add a third button (PREV).
    Firmware (main + selftest):
    - Removed AccelStepper, driver selection, all stepper/homing/endstop code.
    - New pins: FOCUS D2 (B|1), NEXT D3 (B|2), PREV D4 (B|3), VIBRO D5 (output).
    - Non-blocking haptic engine (startBuzz/pollVibro/buzzForWord): on a status-word
    CHANGE only (dedupes the ~15s keep-alive) — WTF=3 pulses, BLOCKED=2, FREE=1
    tick, WIP=silent. OLED-init-fail now pulses the motor.
    - Main sketch down to 57% flash / 3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
    [claude_mate.ino, claude_mate_daemon.py, selftest.ino]
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2026-06-29 Add PTY wrapper for full-state tracking + reliable terminal focus
    Replace the hook approach with a process that wraps `claude` in a PTY and reads
    its entire live TUI — so it sees everything the hooks couldn't: the spinner,
    API errors/retries, permission prompts, and "Waiting for N dynamic workflow"
    (i.e. it knows a session is still busy after the turn "ends").
    - bin/claude-mate-wrap: forks a PTY, runs the real claude transparently, mirrors
    the TUI into a pyte screen, and classifies state (working/waiting/error/idle)
    from the rendered screen. Reports to the daemon, auto-registers on launch and
    sends 'end' on exit (display mirrors open wrapped terminals). Listens on a
    per-session co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
    [claude_mate_daemon.py, test_wrapper.py]
2026-06-29 UX: no auto-carousel, compact 2-line card, helicopter buzz, single-window focus
    Per user feedback:
    - Daemon: drop auto-rotation — only NEXT/PREV change the displayed card. Names
    up to 20 chars (NAME_MAX 10->20).
    - Firmware: replace the big status word with a compact card — top line
    "name(<=20) i/N", bottom line size-2 "STATUS time" (WORK/WAIT/ERR/DONE/IDLE).
    Helicopter haptic: ~2s rapid stutter on BLOCKED and FREE(finish); WTF a
    distinct urgent burst; WIP silent. curName buffer 11->21.
    - Wrapper: FOCUS raises ONLY the matched Terminal window (match tab by TTY, drop
    the app-wide `activate` that was bringing every Terminal window forward); name
    cap 10->20.
    Verified: firmware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
    [claude_mate.ino, claude_mate_daemon.py]
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2026-06-29 Daemon: live 'time in state' timer for idle/waiting/error cards
    The card timer froze on the last turn's duration for any non-working
    state (runtime_seconds returned last_runtime), so an idle/blocked tab
    showed a stale mm:ss that never advanced while WIP ticked live.
    Track state_since (stamped only on real state changes, so 20s keepalives
    don't reset it) and show live elapsed-in-state for idle/waiting/error.
    'working' stays live since turn start; 'done' keeps the frozen completed
    turn duration as a result.
    [claude_mate_daemon.py]
2026-06-29 Haptics: per-session buzz on finish/block/error (V| command)
    The motor only buzzed when the AGGREGATE status word changed (firmware
    buzzed on D| word change). With multiple concurrent sessions, one
    finishing left the word as WIP (another still working), so no buzz --
    'finished task but no vibration'.
    Add a daemon-driven V|<WORD> firmware command that buzzes a pattern
    without touching the wheel/OLED. Registry.update() now returns a
    per-session haptic word (FREE on working->idle/done, BLOCKED on
    ->waiting, WTF on ->error) which the socket server routes to the device.
    So each session's own finish/block/error is felt regardless of the
    aggregate word. D| word-change buzz stays as a coalescing ba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
    [claude_mate.ino, claude_mate_daemon.py]
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2026-06-29 Haptics+UX: acknowledge model, repeat nags, auto-show, gentler graded buzz
    Daemon now owns all haptics with a graduated, gentler vocabulary (PWM
    amplitude) and per-session acknowledgment:
    - Job started -> one-shot super-short gentle 'START' tick.
    - Finished (working->idle) becomes DONE and stays DONE (alerting) until
    the user FOCUSes the tab; later idle keepalives don't clear it. Nags
    every 15s.
    - Needs input (waiting) nags every 10s; error (incl. API 500/429) every
    5s. FOCUS acknowledges (silences) any alert; for done it also -> idle.
    - Auto-show: the screen surfaces the most urgent unacknowledged tab
    (error>waiting>done); NEXT/PREV browse without acknowledging and hold
    for NEXT_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
    [claude_mate.ino, claude_mate_daemon.py]
2026-06-29 DONE buzz soft->hard; detect: footer-scope picker phrases (fix false waiting/error)
    Haptics: DONE was too gentle. Add a per-pulse accent amplitude to the buzz
    engine (startBuzz dutyLast) and make DONE a soft pulse then a HARD hit, so
    a finish is clearly felt while staying short.
    Detection (review fixes): the new generic picker phrases matched the WHOLE
    screen, so Claude merely showing them (editing patterns.json, quoting a
    footer) flipped to a nagging 'waiting'; and 'rate_limit_error' (a literal
    API token in code/docs) flipped to a 5s-nagging 'error'.
    - Move generic picker phrases to a footer-only category matched in the last
    few non-empty lines; a footer 'esc to interrupt' (generating) w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
    [claude_mate.ino]
2026-06-29 Review fixes: close onset double-buzz race, show_session snapshot, nav-pause order, done runtime fallback
    Address LOW findings from the adversarial review:
    - _repeat_alert: require the alert to be >= one interval old (state_since)
    before nagging, so the one-shot transition buzz can't double-fire at
    onset if a Carousel tick reads alert_due before push_buzz stamps it.
    - show_index takes an optional sessions snapshot; show_session passes its
    own ordered() snapshot (no TOCTOU second ordering).
    - NEXT/PREV pause auto-show BEFORE advancing, so a racing tick already
    sees the pause and holds the user's selection.
    - done card runtime falls back to time-in-state when no turn was tracked
    (avo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
    [claude_mate_daemon.py]
2026-06-29 OLED: ack dot on the card (blinking=unacknowledged, hollow=acknowledged)
    Hard to tell which alert tabs are acknowledged. Add an 8th card field
    'ack' (1/0) and render a top-left dot for alert states (done/waiting/
    error): a filled BLINKING dot when unacknowledged (needs you), a hollow
    ring once acknowledged (focused). Non-alert states (idle/working) show
    no dot. Firmware blinks the dot ~every 400ms and reserves a left slot so
    the name doesn't overlap; tolerant of a 7-field (no-ack) line.
    [claude_mate.ino, claude_mate_daemon.py]
2026-06-30 OLED: show model · effort per card; stop /effort & /model pickers from false-buzzing
    Card: the PTY wrapper now scrapes the model (welcome-box header) and effort
    (◉ pill), caches them per session, and reports them as two new trailing wire
    fields (state|sid|name|ctrl|model|effort). The daemon stores them on the
    session and appends them to the S card (…|ack|model|effort); the firmware draws
    a small 'model · effort' row between the name and the big status word (3-line
    card when present, original 2-line card when absent). All new fields are
    optional, so hook-driven sessions and older peers are unaffected.
    Buzz fix: opening the /effort (and /model) slider rendered '… · Esc to cancel',
    wh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
    [claude_mate.ino, claude_mate_daemon.py]
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2026-06-30 Detect: read the live activity meter as working (fix thinking phase mis-read as idle)
    Claude Code's extended-thinking spinner ('Forming… (14s · ↓ 610 tokens ·
    thinking with xhigh effort)') carries no 'esc to interrupt' hint — and that hint
    rotates out for a 'Tip:' line even while generating. Keying 'working' off those
    keywords alone read the thinking phase as idle, so the daemon turned the
    working→idle flap into a premature DONE buzz mid-turn and flipped the card to the
    done/needs-you alert while Claude was still grinding (worst with xhigh/ultracode,
    where thinking runs long). Add a regex for the live activity meter (arrow+token
    counter / elapsed-timer parenthetical / 'thinking wit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
    [test_detect.py]
2026-06-30 Wrapper: fix terminal-resize/new-tab hang (SIGWINCH self-deadlock)
    The SIGWINCH handler did `with screen_lock: screen.resize(...)`. Python
    delivers signals on the MAIN thread between bytecodes, so when a resize
    arrived while the main loop already held screen_lock inside
    `stream.feed(...)` (the common case during heavy output), the handler ran
    on that same thread and blocked forever re-acquiring a non-reentrant lock
    it already held. The whole session froze and had to be killed -- losing
    all output. Opening a new tab raises the same SIGWINCH in many emulators,
    so it hung there too.
    Fix: the handler now does only what's async-signal-safe -- flip a flag --
    and `set_wakeup_fd` pokes a self-pipe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
    [test_wrapper_resize.py]
2026-06-30 Detect: scope live spinner/meter to bottom status region (fix self-scrape working-while-idle)
    The generating meter, 'esc to interrupt', and background-agent hints only
    ever render on the bottom status line, but were matched against the full
    20-line live region. A session whose conversation QUOTES those strings (e.g.
    the detector's own design notes) then false-read as working while idle.
    Give busy/meter a tight BUSY_TAIL_LINES=8 window; keep error/waiting on the
    wider 20-line tail (those are genuinely multi-line). Regression test added.
    [test_detect.py]
2026-06-30 Wrapper: "machine gun, no excuses" robustness pass (signals, non-blocking I/O, detection, lifecycle)
    Recovered + actioned the earlier 13-issue review (only #1 SIGWINCH was done).
    Fixes the confirmed HIGH/MEDIUM functional/UX issues, verified by an adversarial
    multi-lens review of the diff (2 rounds) plus new regression tests.
    Signals / lifecycle:
    - #2 add SIGTERM/SIGHUP/SIGQUIT handlers + atexit -> one idempotent cleanup();
    kill/logout/reboot now restore the tty and deregister instead of leaving a raw
    shell + ghost session + leaked ctrl socket.
    - cleanup(): critical teardown (send 'end', unlink socket) runs FIRST; tty restore
    uses TCSANOW (TCSADRAIN/TCSAFLUSH block until output drains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
    [test_detect.py, test_wrapper_lifecycle.py]
2026-06-30 Firmware: move OLED SCL to A3 via software I2C (hardware A5 damaged)
    The Nano's hardware I2C SCL pin (A5) was physically damaged. The ATmega328P's
    TWI peripheral is fixed to A4=SDA / A5=SCL and can't be remapped, so SCL moved
    to A3 (a plain GPIO) driven by a bit-banged I2C master; SDA stays on A4.
    - New softssd1306.h: an Adafruit_GFX subclass implementing begin/clearDisplay/
    display/drawPixel over open-drain software I2C on A3(SCL)/A4(SDA). All existing
    drawing/text code (print, setCursor, setTextSize, drawCircle, fillCircle, ...)
    is unchanged since it's pure Adafruit_GFX.
    - claude_mate.ino: drop <Wire.h>/<Adafruit_SSD1306.h> + the hardware-Wire
    constructor; use SoftSSD1306. Updated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
    [claude_mate.ino, softssd1306.h]
2026-07-01 Haptics: gentler patterns + continuous 'until acknowledged' loops
    Rework the vibration model to be softer and less noisy, and to loop until
    you focus the tab (per user request):
    Firmware (claude_mate.ino): replace the single-gap startBuzz with a step-based
    engine (VibroStep{onMs,offMs} list, per-pattern PWM duty, optional LOOP flag).
    New patterns, graduated-but-soft amplitude (never full 255):
    START 3x0.3s gentle ticks one-shot
    INPUT soft double-tap one-shot (daemon re-taps ~10s)
    DONE 5x0.2s heartbeat, gaps 0.2/0.4s loops until V|OFF
    ERROR 0.4s on / 0.2s off alarm loops until V|OFF
    OFF stop the motor
    A loop repeats until V|OFF or a 30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
    [claude_mate.ino, claude_mate_daemon.py, test_e2e.py]
2026-07-01 Haptics: fix loop desync/races found in adversarial review
    Follow-up to 5ed1f86, from a multi-agent review of the haptics rework:
    - HIGH: re-arm the motor loop on handshake/reconnect. A Nano reset or replug
    (routine for this board) reboots the firmware motor-off, but the daemon kept
    _loop_kind='DONE'/'ERROR', so _set_loop saw the loop as already-sent and never
    re-emitted it -> an unacknowledged done/error alert went silent forever.
    resend_full_state() now forgets _loop_kind and re-drives update_haptics().
    - MEDIUM: _set_loop() now does check -> write -> commit atomically under the lock
    and commits _loop_kind only on a SUCCESSFUL write. Fixes both the failed-write
    desync (tracker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
    [claude_mate_daemon.py, test_e2e.py]
2026-07-01 UI: PREV->MODE button, LIST mode (all tabs), snappier buttons
    Redesign the 3-button interface (layout MODE | SUBMIT | NEXT):
    - PREV becomes MODE: short press = prev/back (B|3), long press >=500ms = toggle
    UI mode (new B|4). SUBMIT (was FOCUS, B|1) and NEXT (B|2) keep their roles.
    - Two UI modes (daemon-owned): SCROLL = the existing carousel; LIST = a scrolling
    list of ALL tabs (name + one-char state glyph), highlight moved by NEXT (down) /
    MODE-short (up), SUBMIT focuses the highlighted tab. Long-press MODE toggles.
    - Faster buttons: debounce 200ms -> 40ms; SUBMIT/NEXT emit on press, MODE
    distinguishes short (on release) vs long (at threshold).
    Firmware: step-based button polling (p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
    [claude_mate.ino, claude_mate_daemon.py, test_e2e.py]
2026-07-01 UI: track LIST selection by session key (fix highlight drift + docs)
    Follow-up to c8f1174, from an adversarial review of the button/LIST redesign:
    - MEDIUM: LIST highlight was a positional index into ordered(), which re-sorts by
    (state, name). When the fleet reordered (a new session, a state change, a prune)
    the highlight silently jumped to a different tab and SUBMIT focused the WRONG
    session. Now the selection is tracked by session .key: toggle_mode seeds the key,
    list_nav moves to the neighbour's key, render_list re-anchors sel from the key,
    and list_selected_session resolves by key (falls back to the first tab if pruned).
    - LOW: refreshed the daemon module docstring (B|1..B|4 +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
    [claude_mate_daemon.py, test_e2e.py]
2026-07-01 LIST mode: show readable status labels (WIP/WAIT/ERR/DONE/IDLE) not glyphs
    Per user feedback, the single-char glyphs (W/?/!/D/-) were cryptic and the '-'
    for idle was unclear. LIST rows now show a short status label in a left column
    (WIP/WAIT/ERR/DONE/IDLE) followed by the name in an aligned column.
    Daemon: STATE_GLYPH -> STATE_LABEL (word labels); LIST_NAME_MAX 14->12 so the
    packed T| line stays well under LINE_MAX (worst case ~41 chars observed).
    Firmware: per-row listState char -> listStatus[6] string; drawList prints the
    label at x=1 and the name at a fixed LIST_NAME_X=30 column (names stay aligned).
    Docs (PROTOCOL/README/TESTING) updated to the label scheme.
    Firmware builds 47% flash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
    [claude_mate.ino, claude_mate_daemon.py]
2026-07-01 SCROLL: stay on the acknowledged tab (fix jump-to-first-tab)
    User report: acknowledging (SUBMIT) a tab in SCROLL mode jumped the view back to
    the first/top tab instead of staying on the tab just acknowledged.
    Root cause: refresh_current() re-rendered by POSITIONAL index (_current_index).
    Acknowledging a 'done' tab turns it 'done'->'idle', which re-sorts it to the
    bottom of ordered(); the index then landed on whatever shifted up into that slot
    (the top tab). Same positional-drift class as the earlier LIST-mode bug.
    Fix: refresh_current() now re-anchors to the current SESSION by key (falls back
    to the index only if that session was pruned), so the view follows the same tab
    across re-sorts. S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
    [claude_mate_daemon.py, test_e2e.py]
2026-07-01 Detect: read a running agents panel as working (fix false idle/done)
    User report: a session running background subagents (an Explore agent: 'Hatching…
    5m 2s', '○ Explore … 3m 30s · ↓ 79.9k tokens', 'esc to interrupt') flapped to
    IDLE/DONE on the device.
    Cause: busy_now was computed only from the bottom BUSY_TAIL_LINES (8) region. When
    an agent panel is open, the agent's transcript fills the bottom of the screen and
    pushes the live spinner/meter ABOVE that window, so no busy signal was seen.
    Fix: add _LIVE_LINE_RE and match it over the WHOLE visible screen -- a line that
    STARTS with a spinner/agent glyph (not a done/error marker) followed by a running
    elapsed timer AND an arrow tok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
    [test_detect.py]
2026-07-01 Detect: tighten live-work signal to a line-anchored spinner (fix false positives)
    An adversarial probe of the previous whole-screen detector (a9de815) found real
    false positives: idle sessions whose visible screen merely CONTAINED meter-like
    text read as working -- a markdown benchmark table (| Opus | 2m 30s | ↓ 79.9k
    tokens |), a bulleted note quoting a meter, and a finished-agent recap row that
    kept its token tally (hollow ○, not the excluded ●). The bare glyph+timer+meter
    match was too permissive ([^\w\s] also matches -, |, *, ·).
    Replace _LIVE_LINE_RE with _LIVE_SPINNER_RE: require Claude's actual live-spinner
    shape -- a verb + ellipsis + parenthetical timer/meter ('Forming… (1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
    [test_detect.py]
2026-07-01 Detect: gate working-signal on the idle-prompt footer (kill meter-quote false positives)
    A re-probe found the tightened spinner regex still false-fired on a spinner line
    reproduced verbatim on its OWN line above an idle prompt (a pasted bug report, a
    README blockquote, this repo's fixtures) -- live and quoted spinners are textually
    identical, so line-anchoring alone can't separate them.
    Robust structural tell: Claude's idle-at-prompt footer ('? for shortcuts') shows
    ONLY when the session is waiting for input; a real working frame -- foreground OR
    a running agents panel -- shows 'esc to interrupt' instead. So gate the whole
    busy_now on 'not idle_prompt' (new _IDLE_FOOTER): quoted meters/spin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
    [test_detect.py]
2026-07-01 Detect: handle hours-format timers and k/M token counts (close false-idle gaps)
    Final probe found the working-signal regexes missed long-running / high-token
    agents: (1) an elapsed timer with an HOURS component '(1h 4m 30s · …)' failed
    because both timer sub-patterns required the first unit after '(' to be m/s;
    (2) _WORKING_METER_RE's bare arrow meter '↓ 79.9k tokens' had no k/M suffix, so a
    k-abbreviated count in the bottom region slipped through. Both re-opened the
    original false-idle (a busy agent read as idle -> premature DONE) for big jobs.
    Fix: allow [hms] as the leading timer unit in _LIVE_SPINNER_RE and _WORKING_METER_RE,
    and add [kKmM]? to the bare arrow-meter alt. test_detect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
    [test_detect.py]
2026-07-02 UI: quiet mode, LIST detail (double-click), and per-row blink dot
    Three interaction upgrades (firmware + daemon):
    1. Quiet mode (mute vibration) -- SUBMIT long-press (new B|5) toggles it, handled
    firmware-locally: while muted, buzzForKind swallows every V| (except OFF),
    tracks the last DONE/ERROR loop, and on UN-mute replays it (so an unacked alert
    is felt at once -- the 'buzz if unacked' behavior). A small muted badge is drawn
    on every screen while quiet. SUBMIT is now a short/long button (generic
    pollLongButton, shared with MODE); the daemon just logs B|5.
    2. LIST detail sub-view -- double-click SUBMIT (two short presses within ~0.35s)
    opens the highlighted tab's full c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
    [claude_mate.ino, claude_mate_daemon.py, test_e2e.py]
2026-07-02 UI: fix review findings (detail-stuck, double-click race, quiet badge)
    From an adversarial review of 36bae0c:
    - MEDIUM: LIST detail view stuck on a stale card when the detailed tab ended/was
    pruned (render_list_view fell back to sessions[0]). Now a STRICT key lookup: if
    the detailed tab is gone, auto-close detail back to the list.
    - MEDIUM: double-click boundary race -- threading.Timer.cancel() can't stop a
    timer already firing, so a click at ~0.35s could double-fire (toggle + focus).
    Added a generation token; the deferred single-fire no-ops if superseded.
    - MEDIUM/LOW: the persistent quiet badge (8x8 top-right) clobbered the card's
    idx/total counter and the list scrollbar, and co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
    [claude_mate.ino, claude_mate_daemon.py, test_e2e.py]
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2026-07-02 Firmware: kick-start the vibration motor (fix intermittent/no buzz)
    The LED blinked the pattern correctly but the motor was intermittent -- a coin/
    pager motor can't reliably START spinning at the gentle PWM duties (80-160/255),
    so it stuttered near its startup threshold (the LED, digital full-on, was fine).
    Fix: KICK-START each pulse -- drive the motor at full power for VIBRO_KICK_MS(45ms)
    then drop to the pattern's sustain duty (a motor's hold threshold is well below its
    start threshold, so it keeps spinning). Also raised the sustain floors a bit
    (80/120/160 -> 110/150/200) so it doesn't stall once the kick ends; still
    graduated. toggleQuiet applies the kick/sustain correctly on un-mute m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
    [claude_mate.ino]
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

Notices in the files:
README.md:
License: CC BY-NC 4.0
